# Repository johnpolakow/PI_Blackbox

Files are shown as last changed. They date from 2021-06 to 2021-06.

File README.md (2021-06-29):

# Raspberry Pi Based Data Acquistion System

# Directories in Repository    
## Docs/    
Contains various documentation info  created while building the software. Specification of commands to the client interface. Information on the ADC Loop, which is continuosly read out by the Raspberry Pi. Some notes on initial configuration of a Pi DAQ. Some how to files that may be useful while administrating the Pi DAQ.

## PCB/    
PI DAQ PCB Files    
Contains the files needed to FAB the Pi DAQ. All Gerber board files are present. The native Kicad project files are present as well, for maintenance and modification. There is rework required for the version of gerbers used here. The rework directions are in the **Docs/** folder. If time permits, will include a "fixed/corrected" version of the Kicad project files, eliminating the need for future rework. 

Cal Station Board Files
The PCB files for the Cal Station board are present as well, however I would not reccomend ordering this board. It was done extremely quickly and many mistakes were made. There was MUCH rework required to make the PCB functional. Almost all of the relay footprints are off. The relay part fits, but some of the pins are swapped. It was unpleasant to re-route all the signals with hookup wire, you would save yourself much time by starting over.    

All BOMS should be present as well.    

## Pi Firmware/
This folder contains the release versions of firmware that runs on the Pi DAQ. The different versions are kept for documentation and bug fixes. Also, the Configuration folder contains useful code to configure a Pi for the first time. It performs functions like:
  - Configuring hostname on the Pi
  - Configure user accounts
  - Getting / Setting Environment variables
  - Setting up alias commands for the pi user
  - setting default IP address and network configuration
  - Enabling SPI & I2C on the pi
  - Enabling SSH
  - Enable AutoLogin at boot for user pi
  - Getting the micro SD card usage stats

# Code Installation and Usage
## Source Code Download 
To download the code to the Pi, make sure you have an active internet connection on the Pi. This may involve editing the /etc/wpa_supplicant/wpa_supplicant.conf file on the Pi to add the credentials for the wifi network you want to connect to. The file will look like this:    
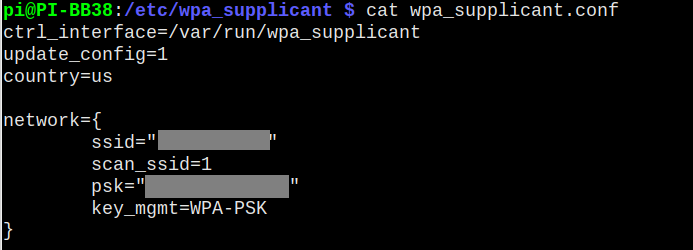
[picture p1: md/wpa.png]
plot
   
modify it by filling in the ssid of the network and the pre shared key (password) of the network.   

After conneting to Wifi/Internet, make a directory for the firmware:   
```mkdir /home/pi/firmware```   
```cd /home/pi/firmware```    
    
now clone the github repo:   
```git clone https://github.com/johnpolakow/PI_Blackbox.git```       

move everything to parent folder:         
```cd PI_Blackbox/```      
```mv -f ./* ../```     
```cd ..```
```rm -rf PI_Blackbox/```    

The PCB directory is not needed on the Pi:     
```rm -rf PCB/```     

move Docs folder to parent dir:    
```mv -f Docs/ ../```   

Change to Pi_Firmware directory and remove unnecesary releases, and move Configuration directory:      
```cd PI_Firmware/```     

Only the latest version is needed. You can remove the directories for older versions. For instance if you want to remove *Release0/* directory:    
```rm -rf Release0/```    

Move **Configuration/** directory to another location:    
```mv Configuration/ ../../```      

Last, the contents of the latest release may be moved to the firmware folder:    
```cd Release1```       
```mv -f ./* ../../```    
```cd ..```    
```rm -r Release1```    
```rm -r PI_Firmware/```     

You should now have two items in the **/home/pi/firmware/** folder:     
  - src/ folder, containing source code for compiling the DAQ executable    
  - makefile, to compile the source code    
![plot](./md/firmware3.png)    

## Compilation    
Compile the source code with the **make** command:    
![plot](./md/make_daq.png)   

the **DAQ** binary will be created. It can be executed directly with the command:     
```sudo ./DAQ```     

or, alternatively, the server process can be started with:     
```sudo systemctl restart Blackberry.service```    

check to see the process is running with the **top** command:   
```top```     
after executing the command a process display will popup. **DAQ** should be at the top:    
![plot](./md/top01.png)   
to exit out of the process display screen, hit the **q** button 

If DAQ process is not shown, then you need to either execute the DAQ process directly or start the Blackberry systemd service with:   
```sudo systemctl start Blackberry.service```

## SystemD Maintenance and Server Process Start     
 Some commands to administrate the Blackberry server process.
 see process status:        
```sudo systemctl status Blackberry.service```     

start the process:   
```sudo systemctl start Blackberry.service```    

stop the process:   
```sudo systemctl stop Blackberry.service```    

to start service at boot:    
```sudo systemctl enable [Blackberry.service]```    

view the server process file:   
```sudo systemctl cat Blackberry.service```

edit the service file:    
```sudo systemctl edit --full Blackberry.service```   

find out if the service is enabled:   
```sudo systemctl is-enabled Blackberry.service```

see log entries related only the the PI DAQ server process:   
```sudo journalctl UNIT=Blackberry.service```

```daemon-reload```

## Socket Connections    
The DAQ process opens tcp port 2020 and waits for a client to connect. To verify the port is open and listening, try these commands:    
```sudo ss -l -p | grep -vE '^(u_|nl )'```   
```sudo ss -lntu```    
```netstat -l -46```    
![plot](./md/netstat_l_46.png)   
![plot](./md/ss_lntu.png)   

## Querying the Server from a Client Machine
see client code repository. Also see 'Pi_Blackbox_Software_Behavioral_Specification' in the Docs/ directory:   
https://github.com/johnpolakow/PI_Blackbox/tree/master/Docs        
https://github.com/johnpolakow/PI_Blackbox/blob/master/Docs/Pi%20Blackbox%20Software%20Behavioral%20Specification_v2.pdf     
https://github.com/johnpolakow/Blackbox_Client    

## Lessons Learned
Things I would do differently if I was to do another version of this board:     
  - Do the layout in Cadence
  - Use switching regulator to drop input of +18-24V down to +13-14V. Eliminating the need for fan and heat sink
  - Low noise *switching* regulator for Pi voltage supply. The present switching converter IC required softening of the switching waveform to get the noise down.
  - Change 2N3055 BJT based programmable current source to FET based. 
  - smaller SMD crystals
  - Use SOM instead of full Pi Board
  - High speed ADCs for Voltage and Current measurement. More accurate power metric + phase information
  - More compact electrolytic caps
  - Only use ceramic caps near LT1054 voltage inverter. Tantalum cap ended up failing due to high ESR and switching current
  - smaller input capacitance, to lower the inrush current

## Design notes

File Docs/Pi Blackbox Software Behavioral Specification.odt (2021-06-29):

PI Blackbox

Software Specification

demo software commands

May 5, 2020

Table of Contents

Table 1 - Revision History

Version | Date | Author | Changes
Draft | Jan, 27, 2020 | John Polakowski | Based on group discussion of features and scope of interface. Initial goal to provide a rapid version of working code and conventions.

Table 2 – List of Acronyms

Acronym | Definition
DUT | Device Under Test
IDCA | Integrated Dewar Cooler Assembly
EMI | Electromagnetic Interference
PI_BB | PI Blackbox
LUT | Look Up Table

# Blackbox architecture

## Function

The Blackbox design goal is to datalog and control different metrics related to cooler testing. The Blackbox is to serve as an all-in-one piece of test equipment that can be used in many different use cases of cooler testing. These include: Lifetime Testing, Performance Testing, Burn-In Testing, …… The device under test (DUT) may be the complete IDCA, or one of its component parts (Compressor, Dewar, Displacer, CCC).

MUST EXECUTE PROGRAM WITH SUDO

## Peripherals

The peripherals of the PI_BB are:

Input Power

Power to CCC (banana plugs)

Dewar Connector (DB15)

3 thermocouples

PI USB

PI Ethernet

PI HDMI/DSI

Test Points

LEDs

## Metrics Captured

The IDCA metrics directly measured by the Pi Blackbox are:

- Power delivered to the Cooler Driver Board (Volts, mA, Watts)
- Dewar Temp Diode Voltage, and associated LUT temperature (Volts, Kelvins)
- Power delivered to heat load resistor in the Dewar (V, mA, mW)
- Heat Load State (On/Off)
- Relay State for Cooler Driver (On/Off)
- Temperature of x3 attached K-type thermocouples (Celsius)

## Capture Rate(s)

The target is to capture each metric once per second. The cooler power measurement accuracy improves considerably the more often we are able to sample it. It may become desirable at some point to reduce sampling frequency of the thermocouples, or temp diode, and increase the sampling frequency of the cooler power. For simplicity, at present all metrics are sampled equally.

The Pi firmware captures each metric sequentially, then writes the data points to file. Each datalog point of the above metrics is paired with:

- Timestamp ( MM/DD/YYYY hh:mm:ss )
- Elapsed Running Time when sample taken

# Software Specification

## Timestamp, Date-Time Naming Convention

A timestamp shall be represented in the format:

[MM-dd-YYYY]_[hh.mm.ss]

MM 2 digit month

dd 2 digit day of month

YYYY 4 digit year

hh 2 digit hour

mm 2 digit minute

ss 2 digit second

* 2 digit refers to the convention of including a leading zero if the value is less than ten.

** To avoid AM/PM confusion, the two digit hour shall be in the 24 hour based format. For example the hour 6:01:35 PM is represented as 18:01:35

Example:

Timestamp for Jan. 27th 2020 @ 3:18:34 PM is- 01/27/2020_15.18.34

## BlackBox Naming Convention

Each PI_BB has an associated ID. This is referred to in log files, Pi hostname, and IP address assignment. The ID scheme for a unit is as follows:

PI_BB[integer 10-240]

A valid ID would be: PI_BB20

This allocates a namespace of 230 potential blackboxes. The range of 10-240 makes sense in the IP Address space. The integer number will be the value used in the last address byte of the IP Address. The limitation to 240 follows with the largest value for an address byte: 255. The additional addresses (1-9, 241-254) are left for the hub computer, and any diagnostic PCs we might want to connect to. So for example if we have a unit named “PI_BB38”, on a network 192.168.123.0, the unit will have an IP Address of:

192.168.123.38

Additionally, the hostname for the pi will be:

pi@PI_BB38

If you open a terminal on this Pi, the resulting prompt will be:

This makes it easy to identify which Blackbox you are logged into if you SSH into the pi, or if you SCP a file to the PI.

**Possibility

If all units in a network are going to be used for a specific test, the ‘PI_BB’ could be changed to the name of the test. For instance:

pi@LifeTest20

pi@PerfTest20

pi@BurnIn20

Implementation Info

To change the hostname on a Pi two files need to be edited. These files must be edited using the ‘sudo’ command. To edit:

sudo vi /etc/hosts

sudo vi /etc/hostname

After editing and saving the above files, reboot to enable the new hostname.

Hub IP Address should always be .1

## Log File

### Log File Naming Convention:

The structure of the filename is:

BlackboxID_Date_Time.log

The specific syntax is:

PI_BB[blackbox#]_[MM-dd-YYYY]_[hh.mm.ss].log

The Date-Time timestamp is when the test begins.

All log files will end in ‘log’.

Optionally, the type of test being performed could be included in the filetype for easier file sorting in file store locations. For instance the following file extensions could be used when the type of test being performed is known:

.performance_log Performance test log file

.lifetime_log Lifetime Test Log files

.burnin_log Burn-In test Log Files

.log generic log file

Example: a log file for the performance test, which was captured using PI_BB21, and started the test on Feb. 2nd 2020 at 3:36:54 PM, would have the following log file:

PI_BB21_02-02-2020_15.36.54.performance_log

or alternatively:

PI_BB21_02-02-2020_15.36.54.log

### Log File Structure

// filename: XXXXXX

## PI_BB LOG FILE ##

firmware version XXXXX, PCB version

PI_BB: [blackbox#]

CCC: CCC_ID

Compressor: Compressor_ID

Dewar: Dewar_ID

Displacer: Displacer_ID

Test Execution: [Manual] or [profile filename]

Test_Type: [default/Performance/Lifetime/BurnIn]

Log Start: [Timestamp]

[COLUMN LEGEND]

_______________________________________________________________

START [TIMESTAMP]

DATA [TIMESTAMP]

COMMAND [TIMESTAMP]

DATA [TIMESTAMP]

STOP [TIMESTAMP]

________________________________________________________________

END

To avoid confusion and misinterpretation, the units of measure are included in both the Legend and immediately following the value of each metric.

### Log File Data Types and Format

The following are column entries in the log file. Each entry is defined as follows:

Value_ID [data type], decimal precision*, units, example entry

CCC_V floating point, 3, Volts, 12.432V

CCC_A floating point, 4, Amps, 0.4328A

CCC_W floating point, 3, Watts, 6.521W

Dewar_degK floating point, 2, Kelvins, 117.31K

Dewar_diodeV floating point, 3, Volts, 0.736V

Heat_Load_V floating point, 2, Volts, 8.42V

Heat_Load_mA floating point, 2, milliAmps, 28.31mA

Heat_Load_mW floating point, 2, milliWatts, 100.26mW

THRMCPL_degC floating point, 2, Celsius, 23.47C

Relay string, [ON/OFF], state, ON

Heat_Load string, [ON/OFF], state, OFF

*decimal precision here refers to the number of digits following the decimal point. For values less than 1, data shall have a leading 0.

For example: 0.236 = good,

.236 = not allowed

### Log File Creation and Refresh

A new log file is created, according to naming convention, at the start of test execution. A timestamp is including as part of the filename to prevent naming conflicts. The maximum length of time a log file records data is 24 hours. Whenever a new day begins ( at 00:00:00, or 12:00:00 AM), if an existing test is running, a new log file is created. The last line of the previous file instead of being “END” will be “CONTINUED” . The first line of the data section of the new file will be “PREVIOUS” instead of “START”. If the cooler is running, logging must occur.

Example:

[TODO]

### Log File Flags

START beginning of test execution. Either manually or via profile. Relay is closed (turned on). Metrics capture begins.

STOP Relay is opened (turned off). Cooler turns off. May be the end of the test or the test may continue with the cooler off. Datalogging continues.

END End of test. Datalogging halts. No data for this test is stored in a subsequent timestamped file.

CONTINUED Data for this test spans multiple files. It has data for this test stored in a subsequent timestamped file.

PREVIOUS Data for this test spans multiple files. It has data for this test stored in a previously timestamped file.

The above flags are not commands, but indicators of events.

Command Instructions which are issued either from a profile or via the socket interface are echoed to the log file.

### Log File Path

If a USB drive is inserted, the Linux kernel has been configured to mount it to:

/home/pi/USB_drive/

The flash drive is the default storage device if present. The Log file path is then:

/home/pi/USB_drive/Logs/filename.log

If a USB flash drive is not detected, the micro SD card will be used to store the data, and the path will be:

/home/pi/Logs/filename.log

DUT ID’s naming convention: TBD

- Compressor
- Dewar
- Displacer
- CCC

### Log File Upload

The Log File will be uploaded automatically when either:

- the test ends
- a new day begins, and a new file is created. Old file is uploaded

### Appending Parameters to Log File

In the future it may be desirable to annotate some derived metrics into the log file at the end of a test. These metrics might include:

- Cooldown Time
- Warmup Time
- Start Current, Stop Current
- Start Temp, Stop Temp
- Upper and Lower Bounds for power and temp, conditions when that datapoint ocurred.

## Config File

The config file stores and sets important system parameters for the PI_BB. It is not meant for regular user editing. Therefore it is a hidden file and requires elevated permissions to modify.

### Name

The config file is simply named “PI_BB.config”. Alternatively the individual blackbox number could be included, so “PI_BB38.config”. Only one config file should exist on each PI_BB.

### Config File Location

The config file is stored locally on the SD card in a hidden folder. In Linux hidden folders are named with a ‘.’ prefix. The config folder is named ‘.Config’ and is stored in the home directory.

For example:

~/.Config/PI_BB38.config

~/firmware/.config/PI_BB38.config

or

/home/pi/.Config/PI_BB38.config

/home/pi/firmware/.config/PI_BB38.config

### Config File Fields

// filename: PI_BB.config

hostname:

eth0_IP_address:

Network_address:

Subnet:

Hub_IP_address:

log file suffix (.log, .performance_log, etc)

HUB log store location

USB_flash_mount_folder:

PCB_revision_level:

Profile folder location(s)

environment variables

hostname

socket

HUB_IP_ADDR

cal file location

firmware version

## Profile File

### Profile File Structure

The file begins with a header describing the profile, the type of profile, and the profile name. After the file header is a separation line, then profile commands. For example:

// filename: XXXXX.profile

PI_BB_Profile_Definition_File

Profile_Type: [Lifetime | Performance | SADA | BurnIn | Custom]

Profile_Name: XXXXXX

Description: (description of profile)

________________________________________________________________

[COMMANDS] [TIMESTAMPS]

### Location

Profiles to be executed are stored locally on the SD card. The profiles are stored in a folder named ‘Profiles/’ and is located in the home directory.

For example:

~/Profiles/LifetimeTest.profile

or

/home/pi/Profiles/PerformanceTest.profile

### Profile Command List

START_LOG start data logging

RELAY_ON close relay to power CCC

RELAY_OFF open relay to power CCC

SET_LOAD change load setting. Setting is in mW, default is 0.0

LOAD_ON turn load on, adjust to setpoint

LOAD_OFF turn load off

STOP_TEST turn off load, turn off relay, stop logging

Each command must have an accompanying elapsed time timestamp, which indicates how much time elapses before executing the command. Every subsequent command must have a timestamp equal to or later than the previous command

Example File:

[ TODO ]

## System Startup

Once primary power is provided, the Pi begins to boot the kernel. A script is placed in the /etc/init.d/ folder which executes the following things:

- SPI and I2C enabled on the PI
- SSH enabled
- Read Config File
- Set IP Address
- Set Hostname
- Set Environment Variables
- Look for attached Flash Drive, if detected mount it
- Look for Hub to Connect to
- Sync to Network time if Available, else sync to DS3231
- Send SSH keys to hub
- Load Calibration files
- Enumerate any profiles in USB flash drive , copy to local SD card
- GPIOS are configured on the PI
- if network connected, do a package update

# parse kernel warnings

At end of test automatically upload file and unmount flash drive

log kernel errors to local non-volatile log file

# Socket Interface Specification

## Socket Instantiation

A specific port number mapping scheme needs to be decided on for the PIs and the Hub. [ TBD ]

## Socket Command Structure

All “commands” or instructions will originate from the hub computer. There are two types of instructions sent to a PI_BB:

- Get Instruction– will refer to as a ‘Query’
- Set Instruction – referred to as a ‘Command’

Query Instructions must begin with a ‘?’.

Command Instructions must begin with a ‘>’.

If an instruction is sent without the proper prefix of ‘?’ or ‘>’, or there is a typo in the instruction, the parser responds with a message:

Error: unable to parse instruction

to see command list type help

## Query List

?status Return the following parameters:

hostname

eth0 IP address

wlan0 address

flash drive disk usage

SD card disk usage

DUT ID for:

compressor

dewar

displacer

CCC

Pi CPU temperature

Test status (whether executing a test or not)

Execution set to manual or profile

Current time & date on PI

?profiles list the profiles currently stored on SD card

?logs list the logs currently stored on SD card

?profile list the current selected profile, if any

?show [filename] print the contents of the file. Could be a profile, log, config file, etc.

?metrics Returns a snapshot of the current measurements, if a test is running. If no test is running then a message is returned:

“No Test Currently Running”

?time Current date-time PI thinks it it right now

? If no argument is supplied with the query instruction, the list of query instructions is printed

help Prints query instructions and command instructions with usage info.

## Command List

>START_TEST Starts test execution, within the confines of selected test parameters. If a profile is selected, execution of the profile begins. If test execution is set to manual, then datalogging begins and the relay is turned on. A response is given affirming datalogging has begun, the response includes the name and path of the log file. Before executing the command, the system first asks the user to verify the test parameters. These include:

- Save Location
- Mode: manual or profile
- If profile is being run, lists the profile & run time

>RELAY_ON Turn on the relay. This command only valid if a test is currently executing AND test execution is set to manual.

>RELAY_OFF Turn off the relay. This command only valid if a test is currently executing AND test execution is set to manual.

>SET_LOAD [value] Set the load resistor setpoint. The load is not turned on with this command, just set to the value of the supplied argument. When the LOAD_ON command is issued, the load disipation will at the value supplied in this command. The units of [value] is milliWatts.This command only valid if a test is currently executing AND test execution is set to manual.

>LOAD_ON Set the load resistor current to the value prescribed by the SET_LOAD command. Default load current is 0 if the load has not been set yet. This command is only valid if a test is currently executing AND test execution is set to manual.

>LOAD_OFF Turn load resistor current off. This command is only valid if a test is currently executing AND test execution is set to manual.

>STOP_TEST Turn off cooler relay. Turn off load resistor current. Stop datalogging. Return total test execution time.

>SET_MANUAL_MODE Set test execution to manual.

>SET_PROFILE_MODE Set test execution to the current profile setting. If no profile has been selected, an error is given.

>LIST_PROFILES Display all profiles that can be found. Use ?profiles

>USE_PROFILE [profile] The file given as an argument is now selected as the profile to be executed. Verify the profile exists. The profile file is parsed to validate it is acceptable. Begin test execution by issuing START_TEST.

>SELFTEST Run the built-in self test operations and report back results.

>SET_TIME [MM-dd-YYYY]_[hh.mm.ss] Set Pi to argument timestamp.

>SEND_LOG upload log file(s) from the last test to the hub. This may span more than one file if the test lasted more than one day.

>SEND_ALL_LOGS upload all log files stored on the flash drive to the hub PC. If no flash drive is present, an error message is displayed regarding missing flash drive.

>SET_COMPRESSOR_ID

>SET_DISPLACER_ID

>SET_DEWAR_ID

>SET_CCC_ID

> If no argument is supplied with the Command instruction, the list of Commands is printed.

*Note: Once profile test execution begins with the START_TEST command, all commands except for STOP_TEST are ignored.

Example Command Workflow to Run a Profile Test:

>SELFTEST // verify PI_BB hardware is good

>USE_PROFILE [profile] // set the profile to a specific profile file

>SET_PROFILE_MODE // set execution to profile mode

?status // verify test parameters look ok

>START_TEST // run the profile

## Socket Permissions

All commands executed over the socket interface shall be executed with user account level permissions. Administrative actions require SSH login.

# PI OS Settings

## PI Relevant Folders

Logs: /home/pi/USB_drive/Logs/ [flash drive]

/home/pi/Logs/ [ SD Card]

Profiles: /home/pi/USB_drive/Profiles/ [flash drive]

/home/pi/Profiles/ [ SD Card]

Config: /home/pi/.Config/ [ SD Card]

Firmware: /home/pi/Firmware/ [ SD Card]

## SSH Keys

SSH is enabled for each PI_BB. SSH keys are generated for each Pi. At startup the PI sends the public keys to the hub for easy user level login and SCP file transfer.

## Calibration

The embedded hardware on the PI_BB PCB requires calibration to measure accurately.

[ TODO ]

## User Accounts

Two user accounts shall be created for use on the PI. One is a user level account, with permissions to do basic functions. The second account is an administrator account which can perform configuration edits, etc.

### Operator Access controlled functions

[ TODO ]

### Administrator Access Controlled functions

[ TODO ]

# Built in SELF Test function

A built in test function shall be available in the Command List. This function when exercised will perform a series of tests and report the result.

The list of information reported shall be

- CPU status
- RAM allocation for CPU and GPU
- GUI Video test
- PI_CPU temperature
- PI_USB interface up
- PI Ethernet Interface up
- Input Voltage in expected range
- Config file is filled out
- USB Flash drive detection
- Can ping Hub
- Can communicate with all onboard peripheral ICs
- Can operate relay
- temp diode and heat load resistor attached and working as expected
- Can talk to Hub over socket interface
- Real Time Clock has been set
- Synced to Network Time

PI_Blackbox Software Behavioral Document

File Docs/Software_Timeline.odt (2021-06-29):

Raspberry PI Blackbox

( Blackberry ?) Software

Timeline Estimates

Feb 13, 2020

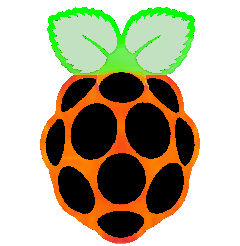
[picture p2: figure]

Table of Contents

# Completed Already

## System Startup / Configuration

Functionality Completed:

- Execute shell commands from C program
- List Files and Folders in a given directory
- Retrieve Environment Variables
- Set Hostname
- Get Hostname
- Add User
- Enable Autologin for user
- Set password for user / change password
- Backup files before modifying
- List Users
- Create Aliases File
- Verify boot file configured properly
- Configure boot file
  - enable ssh
  - enable I2C
  - enable SPI
  - enable SPI1
  - disable bluetooth
  - Set language to US
  - Set US keyboard layout

# Software TO COMPLETE

## System Startup / Configuration

Time Estimate: 7 days

Tasks

- setup network
- setup automatic mounting of flash drive to predictable location
- setup automated install of bcm2835 library, and other needed libraries
- parse PI_BB.config file
- Set Environment Variables
- Look for attached Flash Drive, if detected mount it
- Look for Hub to Connect to
- Sync to Network time if Available, else sync to DS3231
- Send SSH keys to hub
- Load Calibration files
- Enumerate any profiles in USB flash drive , copy to local SD card

## Board Assembly & Bring Up

Time Estimate: 7 days

Tasks

- add through hole components
- add Pis to boards
- bring boards up and verify everything works
  - verify relay working properly
  - verify both ADCs working
  - verify PS working
  - verify DS3231 working properly
  - verify programmable load and AC power measurement

## Execution Engine

Time Estimate: 10 days

Tasks

- Modify current monolithic datalogging code into modular executable components.
- Integrate socket / profile command inputs to execution engine

## Log File

Time Estimate: 3-4 days

Tasks

- Implement Naming Convention (use hostname)
- Parse device ID’s from config file, include in header
- Format Metrics properly
- Implement writing of start/stop flags
- Connect to execution engine to record commands (issued from socket or profile file) in the log
- Upload log file to hub after test completion
- Implement log file refresh every day at 12AM

## Profile File

Time Estimate: 3 days

Tasks

- parse profile, include error checking for: correct syntax, valid time specs, valid commands
- Create mechanism to pass commands to execution engine

## Calibration

Time Estimate: 10 days

Tasks

- get code working to connect to 5335B (power meter) over USB
- code to connect to HP 34401’s via RS232
- code to connect to HP power supply E3648A
- put together code to calibrate a board -
  - set voltage to various settings, read back with 34401
  - adjust pots on pcb
  - run through multiple cooldowns, at various load levels, logging from power meter
  - use logged values vs reported to create a LUT
  - Use external 200 Ohm resistor, run through various load currents, logging with 34401, use logged vs reported to create LUT
  - write code to group sampled values and create LUT
  - write LUT to Cal file

## GUI

Time Estimate: 4-7 days

Tasks

- integrate GUI w/ execution engine, linking the metrics reporting to dynamic updated fields in GUI
- polish GUI interface

## Code Release

Time Estimate: 4-7 days

Tasks

- put together network with Pis and a hub
- test & verify everything is functional when integrated together
- patch any bugs
- finish up any requisite documentation

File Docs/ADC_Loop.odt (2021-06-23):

///////////////////////////

HEAT_LOAD_ON

///////////////////////////

// DO NOT MODIFY THIS SEQUENCE

// THIS IS THE SEQUENCE FOR THE FUNCTION POINTER ARRAY FURTHER ABOVE IN THIS FILE.

// THERE IS A COMPLEX RELATIONSHIP BETWEEN SETTING THE MUX AND WHEN YOU CAN READ (TIME DELAY)

// WITH THIS SEQUENCE IT TAKES 937 milliseconds to complete a loop iteration

// THE FOLLOWING # OF SAMPLES ARE RECORDED:

// TEMP DIODE x 2 samples

// COOLER AMPS x 9 samples

// COOLER_VOLTS x 4 samples

// HEAT_LOAD_V x 4 samples

// HEAT_LOAD_I x 3 samples

// THRMCPL1 x 1 sample

// THRMCPL2 x 1 sample

// THRMCPL3 x 1 sample

ADC0_Read_Temp_Diode();

ADC1_Read_Cooler_Amps();

ADC0_Read_Temp_Diode();

ADC0_Set_MUX_Cooler_Volts();

ADC1_Read_Cooler_Amps();

ADC0_Throw_Away_Reading();

ADC1_Read_Cooler_Amps();

ADC1_Set_MUX_Heat_Load_V();

Read_Thermocouple_1();

ADC0_Read_Cooler_Volts();

ADC1_Throw_Away_Reading();

ADC0_Read_Cooler_Volts();

ADC1_Read_Heat_Load_V();

ADC0_Read_Cooler_Volts();

ADC1_Read_Heat_Load_V();

ADC0_Read_Cooler_Volts();

ADC0_Set_MUX_Cooler_Amps();

ADC1_Read_Heat_Load_V();

Read_Thermocouple_2();

ADC0_Throw_Away_Reading();

ADC1_Read_Heat_Load_V();

ADC1_Set_MUX_Heat_Load_I();

ADC0_Read_Cooler_Amps();

ADC1_Throw_Away_Reading();

ADC0_Read_Cooler_Amps();

ADC1_Read_Heat_Load_I();

ADC0_Read_Cooler_Amps();

ADC1_Read_Heat_Load_I();

ADC1_Set_MUX_Cooler_Amps();

ADC0_Read_Cooler_Amps();

ADC1_Throw_Away_Reading();

ADC0_Read_Cooler_Amps();

ADC0_Set_MUX_Temp_Diode();

Read_Thermocouple_3();

ADC0_Throw_Away_Reading();

ADC1_Read_Cooler_Amps();

//////////////////////////////////

HEAT LOAD OFF

///////////////////////////////////

// DO NOT MODIFY THIS SEQUENCE

// THERE IS COMPLEX RELATIONSHIP BETWEEN SETTING THE MUX AND WHEN YOU CAN READ FROM THE SETTING

// WITH THIS SEQUENCE IT TAKES 1004 milliseconds to complete a loop iteration

// THE FOLLOWING # OF SAMPLES ARE RECORDED:

// TEMP DIODE x 3 samples

// COOLER AMPS x 15 samples (ADC1 dedicated to reading cooler current)

// COOLER_VOLTS x 10 samples

// THRMCPL1 x 1 sample

// THRMCPL2 x 1 sample

// THRMCPL3 x 1 sample

ADC0_Read_Temp_Diode();

ADC1_Read_Cooler_Amps();

ADC0_Read_Temp_Diode();

ADC1_Read_Cooler_Amps();

ADC0_Read_Temp_Diode();

ADC0_Set_MUX_Cooler_Volts();

//printf("Converted %f V to %d counts\n", volts, corrected_counts);

ADC1_Read_Cooler_Amps();

Read_Thermocouple_1();

ADC0_Throw_Away_Reading();

ADC1_Read_Cooler_Amps();

ADC0_Read_Cooler_Volts();

ADC1_Read_Cooler_Amps();

ADC0_Read_Cooler_Volts();

ADC1_Read_Cooler_Amps();

ADC0_Read_Cooler_Volts();

ADC1_Read_Cooler_Amps();

ADC0_Read_Cooler_Volts();

ADC1_Read_Cooler_Amps();

ADC0_Read_Cooler_Volts();

ADC1_Read_Cooler_Amps();

Read_Thermocouple_2();

ADC0_Read_Cooler_Volts();

ADC1_Read_Cooler_Amps();

ADC0_Read_Cooler_Volts();

ADC1_Read_Cooler_Amps();

ADC0_Read_Cooler_Volts();

ADC1_Read_Cooler_Amps();

Read_Thermocouple_3();

ADC0_Read_Cooler_Volts();

ADC1_Read_Cooler_Amps();

ADC0_Read_Cooler_Volts();

ADC0_Set_MUX_Temp_Diode();

ADC1_Read_Cooler_Amps();

ADC0_Throw_Away_Reading();

ADC0:

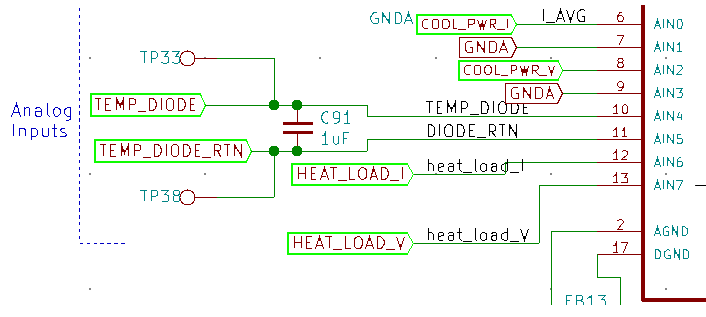
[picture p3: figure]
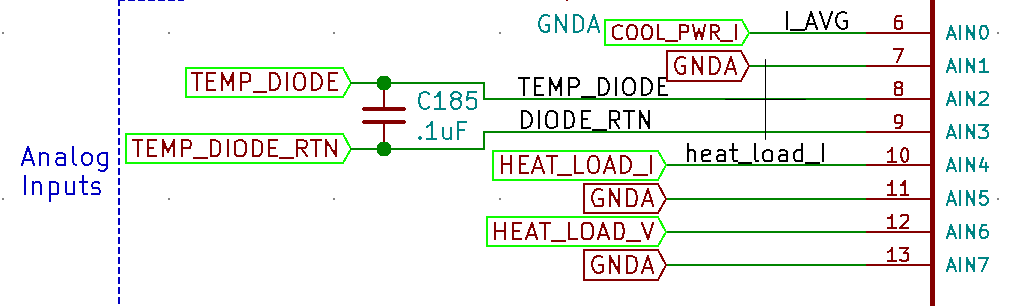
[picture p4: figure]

ADC1:

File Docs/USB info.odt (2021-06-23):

If drive is inserted, it will be listed in /media/pi/XXX

it can also be found with ls -laF /dev/disk/by-uuid

sudo umount /mnt/1GB_USB_flash

sudo mount -o uid=pi,gid=pi /dev/sda1 /mnt/1GB_USB_flash

where:

-o (lowercase letter "o", not the number zero) specifies that an option string follows

uid=pi,gid=pi specifies the user ID is user "pi" and the group ID is "pi" (note there are no spaces allowed between these terms)

/dev/sda1 is the first partition on the first USB drive

/mnt/1GB_USB_flash is the mount point directory

__________________________________________________________

$ sudo vi /etc/udev/rules.d/10-usbstick.rules

SUBSYSTEMS=="usb",KERNEL=="sd[a-h]1",SYMLINK+="usbkey", RUN+="/usr/lib/udev/usbkey " SUBSYSTEMS=="usb",KERNEL=="sd[a-h]1",ACTION=="remove", RUN+="/usr/lib/udev/usbkey"

3) created the /usr/lib/udev/ dir
4) created /usr/lib/udev/usbkey and Added

#!/bin/sh

ACTION=$(expr "$ACTION" : "\([a-zA-Z]\+\).*")

if [ "$ACTION" = "add" ]

then

mount /mnt/usb

else

umount /mnt/usb

fi

5) Gave it exec rights

Code: Select all (https://www.raspberrypi.org/forums/viewtopic.php?t=41056#)

sudo chmod 774 /usr/lib/udev/usbkey

6) Added the following in /etc/fstab

Code: Select all (https://www.raspberrypi.org/forums/viewtopic.php?t=41056#)

/dev/usbkey /mnt/usb vfat ro,noauto,user,exec 0 0

7) Create /mnt/usb dir

8) Reboot or restart udev service .

_______________________________________________________

sudo blkid - list disk devices

lsblk – list devices

ls -laF /dev/disk/by-uuid/

to reload fstab:

systemctl daemon-reload

use UUID in fstab:

UUID=18A9-9943 /media/usb vfat auto,nofail,noatime,users,rw,uid=pi,gid=pi 0 0

mount the device ( %mount /dev/sda1 )

unmount after writing

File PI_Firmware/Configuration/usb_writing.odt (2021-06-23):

We are writing a program for a Raspberry Pi 3B+ with Jesse I think and the 7 inch display. Pi has come a long way since I llooked at it several years ago. And it's true my Linux is a little historical in nature. The program is to display data from a battery controller that uses Tesla Model S batteries for solar energy storage.

It keeps a log file that can go back quite a bit in time and the 32GB SD card I'm using is more than generous. But the comma delimited file just begs an Xcel import and some further graphing and analysis. And we are putting the display and Pi in an enclosure that makes removing/installing the fragile SD card a less than optimal solution.

So basically, what I wanted to do was normally write to a log file on the SD card in our program directory. But if you insert a thumb drive into one of the USB ports, I wanted it to write it there instead. Later, if you removed the Thumb drive, I wanted to go back to the local directory.

I Googled this to death and instead of cunning techniques to do this, I found just entry after entry of snide and condescending snipes to the poor hapless yucks looking for this and bizarre workarounds that posed far too much work for far too little functionality. So by experimentation, I have kind of worked out a way to do this that isn't herculean. It's a little narrow in focus. But I thought I would take a moment and share it as it is kind of an obvious advantage of the 3B+ with the generous provision of four USB ports.

First, just mounting the thumb drive where you want it turned out to be a bit of a Texas Goat Rodeo to work out but quite simple in the end.

First I noted that if you just plugged in ONE thumb drive, no matter which port selected it always comes up as /dev/sda.. A stroke of luck. So to mount it , the first step is to make a directory where you want it to appear. Anywhere you have access to.

Code: Select all (https://www.raspberrypi.org/forums/viewtopic.php?t=222688#)

mkdir ~/programs/Powersafe/usbdrv

I thought this was a fabulous choice of course.

Step 2: append an entry to /etc/fstab using sudo nano /etc/fstab

Code: Select all (https://www.raspberrypi.org/forums/viewtopic.php?t=222688#)

/dev/sda /home/pi/programs/Powersafe/usbdrv auto uid=pi,gid=pi,umask=0022,sync,noauto,nosuid,rw,user 0 0

This basically mounts your drive when you insert it. It links the block /dev/sda to the directory /home/pi/programs/Powersafe/usbdrv.

auto actually refers to the file format. Some drives might be VFAT and others ext4 etc. the auto forces the kernel to try to identify it automatically which it does pretty well.

UID is user ID and GID is group ID and you want to set that to your user name, I still use the default pi account.
umask 0022 is again about permissions I think, I"m not actually sure.

synch simply sets it for synchronous communications.

noauto is quite important actually. It means don't automatically mount on boot. If you set this to auto, and you do NOT have a thumbdrive in a USB slot, it won't boot - it just hangs. Awkward.

nosuid block the operation of suid, and sgid bits.

rw indicates you can both read and write to the drive.

user means any user can mount and you need this for your desktop. Without this flag you might need sudo which isn't where I want to be in C.

The first 0 means the dump utility will ignore your thumbdrive and not try to back it up.
The final 0 is the pass value. File systems with a <pass> value 0 will not be checked by the fsck utility.

Once this is done, I've found the system surprisingly reliable. I can stick a thumb drive in and read it essentially immediately with a simple ls.
ANd when I remove it it disappears. It does usually pop up a FILE MANAGER window asking if I want to view it when I first insert the drive.

Programmatically, the difficulty is the usbdrv directory doesn't look much differently with a drive in our out. You can still read and write to the directory you made with no drive in at all. If you plug a drive in, you will see what is on it. And if you remove it, you'll see what was already there in the underlying directory. We ONLY want to write to that directory if it is linked to a thumb drive.

SO we have to detect whether a thumb drive is available. And that goes back to /dev/sda. So far, again no matter what drive stick I use or what port, it always comes up /dev/sda. So we'll use an ugly system call in our code to determine whether or not we have a thumb drive inserted.

Code: Select all (https://www.raspberrypi.org/forums/viewtopic.php?t=222688#)

void openLogFile()

{

//Check to see if we have a thumbdrive inserted by performing ls /dev/sda. If so we will open a logfile on the thumbdrive

//If not, we will open on the current directory.

char fileName[256]

int thumb = system("ls /dev/sda"); //Thumbdrive = 0 if thumbdrive detected or 512 if none available

//If it IS available, it is already mounted to our /usbdrv subdirectory by /etc/fstab

//FOR REFERENCE FSTAB /dev/sda /home/pi/programs/Powersafe/usbdrv auto uid=pi,gid=pi,umask=0022,sync,noauto,nosuid,rw,user 0 0

if(thumb==0)sprintf(fileName, "%s//usbdrv/PowerSafe100.log",programPath); //open a logfile on a USB Drive?

else sprintf(fileName, "%s//PowerSafe100.log", programPath); //else on our own directory

logfile=fopen(fileName,"a+");

}

The system call is

Code: Select all (https://www.raspberrypi.org/forums/viewtopic.php?t=222688#)

system("ls /dev/sda");

of course. It will return a result of 0 in int thumb if it can list /dev/sda and a value of 512 if it fails.

So we have two statements to form a fileName depending on whether or not thumb =0.

Code: Select all (https://www.raspberrypi.org/forums/viewtopic.php?t=222688#)

programPath

is simply a path link to /home/pi/programs/Powersafe where we run our program. So with a thumb drive, we go to the usbdrv directory below it, and if not, we stay in the main program directory. The file is PowerSafe100.log either way.

Once we have the file open for appending, we can refer to it elsewhere in the program using the global pointer logfile.

Anyway, thats how you can rather automatically mount it. That's how you can detect it. And that's how you can access it from C or C++.

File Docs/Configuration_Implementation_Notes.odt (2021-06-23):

PI Configuration Implementation Details

## Add_User(char* NEW_USERNAME)

Creates a new user login on the pi, and creates home directory for the new user. First the existing list of users is queried, so we don’t add a user if it already exists. If the new username doesnt already exists, it is created by executing the shell command:

sudo useradd [USERNAME]

Then the user account is added to all the groups on the PI, so the new user account can access all of the PI’s hardware resources. Shell command to add groups to the new user account:

sudo usermod %s -a -G sudo,pi,adm,dialout,cdrom,audio,video,plugdev, users,input,netdev,spi,i2c,gpio

## Create_Aliases_File()

Aliases are essentially keywords that represent other commands. They are used to make it simpler to execute otherwise complex or long commands. For instance if you wanted to create an easy way to change the IP Address on the command line, you create an “alias” that represents the longer form of the command.

Example long command:

sudo ifconfig eth0 192.168.250.118 // change IP Address

An alias can be created to represent this command. Pick a keyword to represent the above command, say, “setip”.

Example alias for long command:

alias setip=“sudo ifconfig eth0 192.168.250.188”

Now entering the command ‘setip’ performs the same function as if you entered the long form of changing eth0 address. Some custom alias commands have been added to make using the pi easier to navigate.

The aliases file where these are defined is location:

/home/pi/.bash_aliases or /home/[user]/.bash_aliases

Note the file begins with a ‘.’ This file executes when user ‘pi’ logs on. For a different username, the .bash_aliases file needs to be placed in location /home/[user]/.bash_aliases. If you edit this file manually, you wont see the results of changes until reboot. To effect the changes immediately you can enter the command:

source /home/pi/.bash_aliases

This file is created by this function. The aliases added are:

ls lists directory contents, but groups directories together and adds color coding

la lists all contents. Same as executing ls -la. Also groups directories and color codes the output.

dmesg returns kernel log information, but presents in human readable format. Timestamps are given as dates and timestamps instead of seconds since epoch

update updates cache of package repository

upgrade updates packages to their latest versiona

ps lists processes currently running, and shows the output in a tree format.

df lists disk space usage stats

temp reports CPU temperature of the PI.

Custom functions/commands:

the “temp” command is a custom addition. It reports the cpu temperature of the raspberry pi. It queries the temp by executing:

/opt/vc/bin/vcgencmd measure_temp

The output temperature is then parsed, and wrapped with text “CPU temp:”, and the temperature component is changed to red in color.

The “cd” command has been modified. The new functionality is defined in the ~/.bashrc file. The standard cd command changes directories. The new cd command changes directories, then lists the contents in the new directory location. Often when changing directories the next command you issue is an “ls” command, to list the contents. The new cd function integrates these two steps together and makes navigating the directory tree much easier. The addition to .bashrc is:

function cd

{

builtin cd "$@" && ls

}

source /home/pi/.bash_aliases

## char** Exec_Shell_Command(char* command);

Any command you might normally execute on the command line, you can execute by sending to this function. For instance to list the contents of a file on the command line you might issue:

cat somefile.txt

The same functionality can be executed from the C program using Exec_Shell_Command() function. A short code snippet to do the same thing:

char console_command[] = “cat somefile.txt”;

char** console_command_output;

console_command_output = Exec_Shell_Command( console_command );

Print_String_Array( console_command_output );

Free_String_Memory( console_command_output );

Notes about usage:

Exec_Shell_Command() returns a list of strings, hence the char** return type. Each string is a line of the output from the command. The list of strings is stored in dynamically allocated memory. As a result, we have to handle the “garbage collection”, or letting the OS know when we are done using the memory location. The c function to handle this is free(). Free cannot handle the entire string list though, it can only free one string at a time. It is necessary to loop through and individually free each string. To handle this a helper function was written: Free_String_Memory(), which handles the return of all the dynamic memory allocated. To print any response, Print_String_Array() prints all strings listed in the response of the shell command.

Notes about implementation:

The string representation of the command is passed as an argument to Exec_Shell_Command(). To execute the string, popen() is called. Popen() gives you access to either the read stream, or write stream from the process, but not both. To read the command response, we need the read stream, so the POPEN_READ flag is passed as an argument to popen. popen returns a file handle to the IO stream of the executed command. We can read from the file handle using fgets(). The output is read, one line at a time, and the output is copied to a dynamic string array. New memory locations for strings are allocated only as needed, one line at a time. The end of the string list is indicated by assigning NULL to the end of the list. The pointer to the string list is then returned. It is the callers responsibility to free the memory locations after use.

## Enable_Autologin_For_User(char* USERNAME)

This function enables “Autologin” for a user. In practice this means when you boot the pi, you dont have to enter a username and password before getting access to the console or desktop. To enable autologin, two files are edited:

/etc/lightdm/lightdm.conf // for desktop GUI

/etc/systemd/system/autologin@.service // for console

First these two files are examined to see if autologin has already been configured. The line for each file we are looking for is shown below:

file: /etc/lightdm/lightdm.conf

line in file: autologin-user=pi

file: /etc/systemd/system/autologin@.service

line in file: ExecStart=-/sbin/agetty –autologin pi –noclear %I $TERM

The entry “pi” will be changed to the username passed as an argument to Enable_Autologin_For_User(). To do the text find and replacement in the files, the linux stream editor sed is used. sed is a command line stream editor, which uses regular expressions to find and replace text. If the new username is FLIR, the sed commands are:

sudo sed -i -e '/autologin-user/s/=[a-zA-Z0-9]*/=FLIR/' /etc/lightdm/lightdm.conf

sudo sed -i -e 's/ExecStart=-\/sbin\/agetty --autologin[][a-zA-Z0-9]*[]/ExecStart=-\/sbin\/agetty --autologin FLIR /' /etc/systemd/system/autologin@.service

**Note: the above three lines are a single line in the file.

The meat of the second sed command is as follows:

s/ExecStart=-\/sbin\/agetty –autologin[][a-zA-Z0-9]*[]/ExecStart= ….--autologin FLIR /

s/ perform substitution. The syntax is s/ [find pattern ]/ [replacement text ]

Examining the first pattern match portion:

ExecStart=-\/sbin\/agetty –autologin[][a-zA-Z0-9]*[]/

Breaking the above line into segments for description:

ExecStart=-\/sbin\/agetty –autologin[ ][a-zA-Z0-9]*[ ]/

In english it means:

1. find text beginning with pattern ExecStart=-\/sbin\/agetty –autologin

2. after the above text, look for a single character enclosed in the first set of brackets [ ], which is a space

3. next look for alpha-numeric characters. Lowercase a to z, uppercase A to Z, or 0 to 9. There may be one or more of these characters, indicated by the ‘*’. This is the portion containing the username.

4. look for a single character enclosed in the second set of brackets [ ], which is a space

5. ‘/’marks the end of the pattern

The above pattern matches all text beginning with Exec…, all the way until the end of pi, and a space after pi. The entire line (highlighted in blue) will be replaced by the replacement text (highlighted in green).

*note the ‘\’ characters pre-pended before any string ‘/’ characters. The forward slash is a command flag indicator to sed, so it must be escaped with a backslash.

** If you look at the c code you’ll see any ‘\’ characters pre-pended with an additional ‘\’ character. This is due to C interpreting our escape sequence for sed as an escape sequence within a string. In effect, to enter the ‘/’ character as a string character ( and not a command flag), it must be pre-pended with ‘\\’.

The replacement text:

ExecStart=-\/sbin\/agetty --autologin FLIR /

## void Free_String_Array_Memory(char** string_array)

This function frees dynamically allocated memory stored in string lists, the list is passed as an argument to this function. To free the memory, the list is looped through until encountering a NULL value, identifying the last dynamical memory allocation location. After that, the pointer to the list is freed.

## char* Get_Environment_Variable_Value(char* env_variable)

There are two variable types that can be accessed: system Environment Variables, which are available system wide, and user Shell Variables, which are user specific shell variables. This function first queries the system environment variables, and if not found, the user shell variables are queried. If a match is found, the value of the variable is printed. To query the system environment variables, the c function:

getenv( env_variable )

which returns a string of the value of the environment variable. If getenv() doesnt find the environment variable, the we try to querying the shell for the value:

echo [ environment variable ]

The echo command is executed via a call to Exec_Shell_Command().

## void Get_Disk_Usage()

Gets disk space usage stats for the micro SD card, and any attached USB flash drives.

Stats are collected using the "df" shell command . "df" returns more stats than

just the USB flash and micro SD card, it also returns info from many locations in the root filesystem, so response needs to be trimmed. To filter, the output from df is piped to grep,

which only returns lines that contain “/dev/root” (microSD),

or “/dev/sd” (USB flash). Any USB drives have a kernel device location of /dev/sdX, where X is a letter a-z. To search for all USB drives, we just search on the path “/dev/sd”.

The full shell command is:

df -Tha --total | grep -E "/dev/root|/dev/sd"

Flags for df:

-T print filesystem type

-h print human readable output

--total produce grand totals

Flags for grep

-E use regular expressions in search pattern

Example output:

/dev/sda1 vfat 970M 297M 664M 32% /home/pi//USB_DRIVE

## void Set_Network_Configuration(char* eth0_IP);

Raspbian by default uses a DHCP Daemon (Dynamic Host Control Protocol) to configure the network interfaces. This is a client daemon that accepts IP addresses from a DHCP server. Typically the PI would connect to a router which hosts a DHCP server, and the server would assign the PI an IP address. For our use we want to set a static IP Address on eth0, and leave the wireless interface (wlan0) able to be configured by dhcp. To do this requires editing the dhcpcd.conf file.

*NOTE in previous versions of Raspbian networking was configured via the /etc/network/interfaces file. This no longer is the case. It is imperative to leave the interfaces file alone.

To check if the DHCP daemon is running enter:

sudo service dhcpcd status

If the service is not started, start and enable the service with:

sudo service dhcpcd start

sudo systemctl enable dhcpcd

For manual IP address assignment, the file /etc/dhcpcd.conf needs to be edited.

Edit the file, un-commenting the section titled “Example Static IP Configuration”. Delete the ‘#’ at the beginning of the line to uncomment. The section should now look like this:

interface eth0

static ip_address=192.168.123.11/24

static routers=192.168.123.1

static domain_name_servers=192.168.123.1

The static IP is set on the line:

static ip_address=192.168.123.11/24

The suffix ‘/24’ describes the subnet mask as 255.255.255.0. (Use first 24 bits of subnet mask. Each “255” corresponds with 8 bits.)

The fields static_routers and static_domain_name_servers should be set to the hub IP, or router if it is present.

To give the PI the new configuration:

sudo reboot

The eth0 interface will not actually be set to the static address specified. until there is an Ethernet cable connected between the PI and another network card, so the PI can sense an active connection. Then the interface is configured.

Wifi Configuration

Wifi parameters are set in the file /etc/wpa_supplicant/wpa_supplicant.conf. Only a few lines need to be added, which pertain to any wifi networks you want to join. Also it is important to set the country code in this file. The file should look like:

country=us

update_config=1

ctrl_interface=/var/run/wpa_supplicant

network={

scan_ssid=1

ssid="FLIR-Guest"

psk="6thSense+4BEs"

key_mgmt=WPA-PSK

}

## Get Environment Variables

This function queries the kernel for the values of some kernel environment variables. These specific variables are used in setting up the Pi. The environment variables retrieved are:

$USER

$HOME

$HOSTNAME

Note- these variables change depending on what user is running the command. For instance if user “pi” is logged in but you ask for the environment variables using “sudo”, the environment variables will return values for the user root.

## Get_Environment_Variable_Value

A string of the environment variable name is passed to this function. It then queries the kernel for the variable using the “getenv()” system call. If getenv() cannot find the environment variable name, next the shell is queried. The variable may be a shell variable instead of a system environment variable. The shell is queried via the command:

echo $variable

The command is executed via the EXEC_SHELL() function. The response from the shell is read using the fgets() function.

## Verify_SSH_Enabled

To enable SSH and other hardware settings, typically the rapi-config GUI is used. Though not documented, raspi-config also exposes a command line interface. The command line interface consists of a “get” and “set” option for each parameter. To query for SSH status the command is:

sudo raspi-config nonint get_ssh

The response is:

0 = SSH enabled

1 = SSH disabled.

The raspi-config command is executed in the shell via popen(), and the shell response is read via the fgets() command. The response is parsed to an integer with the strtol() function. (string to long)

Verify_SSH_Enabled() inverts this logic ( 1= enabled) and returns the value

## Set_SSH_Enabled

This also functions via command line interface to raspi-config. To enable SSH the command is:

sudo raspi-config nonint do_ssh 0 // 0 enables, 1 disables

## Verify_Boot_File_Config

The boot file is located here: /boot/config.txt . Don’t manually edit this file unless you are knowledgeable about what you’re doing. Most of the device enables are in this file. The gpio pins on the PI can be configured for different functions, it is done in this file. Each line configures a different setting. To verify the PI is setup how we want, this function searches the file for the configuration lines we want. Each option we desire is searched for.

## List_Users()

To list all users on a linux OS use the command:

getent passwd

getent is the shell command for “get entries”, and is used for mining databases, more than just the password file. Here we are asking for all entries in the password file. There are many users, here is the full output of the command:

root:x:0:0:root:/root:/bin/bash

daemon:x:1:1:daemon:/usr/sbin:/usr/sbin/nologin

bin:x:2:2:bin:/bin:/usr/sbin/nologin

sys:x:3:3:sys:/dev:/usr/sbin/nologin

sync:x:4:65534:sync:/bin:/bin/sync

games:x:5:60:games:/usr/games:/usr/sbin/nologin

man:x:6:12:man:/var/cache/man:/usr/sbin/nologin

lp:x:7:7:lp:/var/spool/lpd:/usr/sbin/nologin

mail:x:8:8:mail:/var/mail:/usr/sbin/nologin

news:x:9:9:news:/var/spool/news:/usr/sbin/nologin

uucp:x:10:10:uucp:/var/spool/uucp:/usr/sbin/nologin

proxy:x:13:13:proxy:/bin:/usr/sbin/nologin

www-data:x:33:33:www-data:/var/www:/usr/sbin/nologin

backup:x:34:34:backup:/var/backups:/usr/sbin/nologin

list:x:38:38:Mailing List Manager:/var/list:/usr/sbin/nologin

irc:x:39:39:ircd:/var/run/ircd:/usr/sbin/nologin

gnats:x:41:41:Gnats Bug-Reporting System (admin):/var/lib/gnats:/usr/sbin/nologin

nobody:x:65534:65534:nobody:/nonexistent:/usr/sbin/nologin

systemd-timesync:x:100:102:systemd Time Synchronization,,,:/run/systemd:/usr/sbin/nologin

systemd-network:x:101:103:systemd Network Management,,,:/run/systemd:/usr/sbin/nologin

systemd-resolve:x:102:104:systemd Resolver,,,:/run/systemd:/usr/sbin/nologin

_apt:x:103:65534::/nonexistent:/usr/sbin/nologin

pi:x:1000:1000:,,,:/home/pi:/bin/bash

messagebus:x:104:110::/nonexistent:/usr/sbin/nologin

_rpc:x:105:65534::/run/rpcbind:/usr/sbin/nologin

statd:x:106:65534::/var/lib/nfs:/usr/sbin/nologin

sshd:x:107:65534::/run/sshd:/usr/sbin/nologin

avahi:x:108:113:Avahi mDNS daemon,,,:/var/run/avahi-daemon:/usr/sbin/nologin

lightdm:x:109:114:Light Display Manager:/var/lib/lightdm:/bin/false

systemd-coredump:x:996:996:systemd Core Dumper:/:/usr/sbin/nologin

There are many extraneous users we aren’t interested in. To get only the “regular” users, we need to filter this list.

There are two fields we care about for each line entry:

pi:x:1000:1000:,,,:/home/pi:/bin/bash

The first highlighted field is the username, the second field is the User ID, or UID.

In the file /etc/login.defs there are parameters that dictate the range of numbers assigned to “regular” user UIDs:

UID_MIN

UID_MAX

The first step in filtering the large list of users is to read the min and max UID parameters. This done by searching the /etc/login.defs file for these two parameters. This done with the command:

grep -E '^UID_MIN|^UID_MAX' /etc/login.defs

The command is executed in the shell via Exec_Shell_Command. The return from the shell command is two strings of the form:

UID_MIN 1000

UID_MAX 60000

These two strings are then then parsed to the integer values: 1000 & 60000. These integer values are the filters for parsing the output from the command getent passwd. To parse the long form of the user list, the helper function parseUsers() is invoked.

void Enable_Sudo_No_Password_For_User(char* USERNAME)

char* Shell_List_Files(char* path)

void Set_Wallpaper(char* wallpaper_filepath)

char** Install_Software_Packages(char* software_list_filepath)

Hostname:

Implementation Info

To change the hostname on a Pi two files need to be edited. These files must be edited using the ‘sudo’ command. To edit:

sudo vi /etc/hosts

sudo vi /etc/hostname

After editing and saving the above files, reboot to enable the new hostname.

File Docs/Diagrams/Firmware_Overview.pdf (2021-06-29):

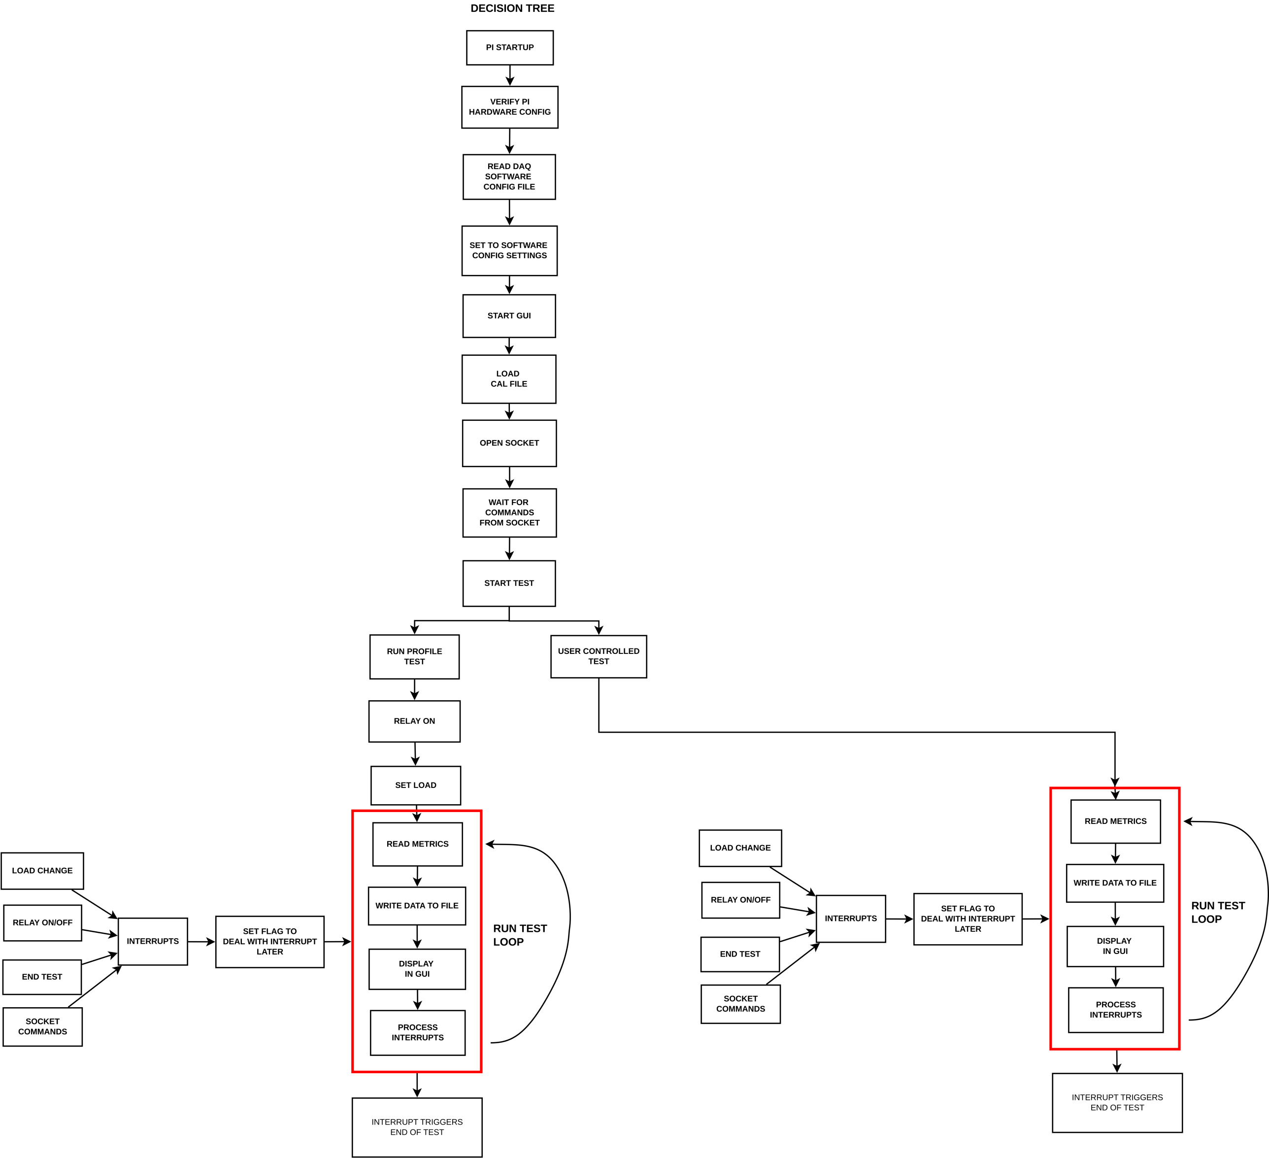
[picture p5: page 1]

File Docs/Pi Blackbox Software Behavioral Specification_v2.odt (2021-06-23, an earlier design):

PI Firmware

Commands/Queries

demo software commands

May 5, 2020

Table of Contents

# PI FIRMWARE

## Source Repository, Compiling, and Executable

The source code has all been written in C, for speed of execution and compatibility with the GPIO library used on the pi (bcm2835). The github repo where the source code can be accessed is:

https://github.com/johnpolakow/PI_Blackbox

The directory for code executing on the pi is “PI_Firmware”. To get a sample client application, which already works with the pi firmware, look in the “Client_Code” folder.

For compiling the firmware on the pi, here is the command (make sure bcm2835 library has been installed if this is a fresh OS):

gcc -g -o exec Execution_Engine.c -l pthread -l bcm2835 -l m

If debugging capabilities are desired use this command:

gcc -g -fsanitize=address -static-libasan -o exec Execution_Engine.c -l pthread -l bcm2835 -l m

The client code is easy to compile:

gcc -o client client.c

IF EXECUTING MANUALLY, MUST EXECUTE PROGRAM WITH SUDO

Note: the binary executable for the program must be executed on the raspberry pi with the “sudo” command. The pi requires programs which access the GPIO pins to have elevated access. If sudo is not used there will be a segmentation fault.

sudo ./exec

Note2: By default the pi has been configured to automatically start execution of the program at boot, MANUAL EXECUTION IS NOT NECESSARY. Under normal circumstances it is not necessary to execute the program manually. If you desire to for testing or debug purposes, make sure to preface the command with sudo.

## Metrics Captured

The metrics directly measured by the Pi Blackbox are:

- Power delivered to the Cooler Driver Board (Volts, mA, Watts)
- Dewar Temp Diode Voltage, and associated LUT temperature (Volts, Kelvins)
- Power delivered to heat load resistor in the Dewar (V, mA, mW)
- Heat Load State (On/Off)
- Relay State for Cooler Driver (On/Off)
- Temperature of x3 attached K-type thermocouples (Celsius)

## Capture Rate(s)

Each metric once per second. Every second a complete iteration of the various metrics are read and saved to storage. The pi can be queried over the socket interface as often as necessary to retrieve the metrics. If querying more than once per second, examine the timestamp in the metrics readout to ascertain whether a duplicate read has been sent. The pi responds with whatever the latest data is.

The Pi firmware captures each metric sequentially, then writes the data points to file. Each datalog point of the above metrics is paired with:

- Timestamp ( MM/DD/YYYY hh:mm:ss )
- Elapsed Running Time when sample taken

# Software Specification

## Timestamp, Date-Time Naming Convention

A timestamp shall be represented in the format:

[MM-dd-YYYY]_[hh.mm.ss]

MM 2 digit month

dd 2 digit day of month

YYYY 4 digit year

hh 2 digit hour

mm 2 digit minute

ss 2 digit second

* 2 digit refers to the convention of including a leading zero if the value is less than ten.

** To avoid AM/PM confusion, the two digit hour shall be in the 24 hour based format. For example the hour 6:01:35 PM is represented as 18:01:35

Example:

Timestamp for Jan. 27th 2020 @ 3:18:34 PM is- 01/27/2020_15.18.34

## Log File

### Log File Structure

// filename: XXXXXX

## PI_BB LOG FILE ##

firmware version XXXXX, PCB version

PI_BB: [blackbox#]

CCC: CCC_ID

Compressor: Compressor_ID

Dewar: Dewar_ID

Displacer: Displacer_ID

Test Execution: [Manual] or [profile filename]

Test_Type: [default/Performance/Lifetime/BurnIn]

Log Start: [Timestamp]

[COLUMN LEGEND]

_______________________________________________________________

DATA [TIMESTAMP]

COMMAND [TIMESTAMP]

DATA [TIMESTAMP]

STOP [TIMESTAMP]

________________________________________________________________

To avoid confusion and misinterpretation, the units of measure are included in both the Legend and immediately following the value of each metric. For instance a voltage is recorded as:

12.013V

### Log File Path

If a USB drive is inserted, the Linux kernel has been configured to mount it to:

/home/pi/USB_drive/

The flash drive is the default storage device if present. The Log file path is then:

/home/pi/USB_drive/Logs/filename.log

If a USB flash drive is not detected, the micro SD card will be used to store the data, and the path will be:

/home/pi/Logs/filename.log

The log file is automatically created and stored when the “>start_test” command is issued.

Note: When configuring the software to auto-launch at boot, it broke the save to USB functionality, so all Logs are being stored on the pi at:

/home/pi/Logs/filename.log

USB save functionality will be restored in the next software release.

### Log File Upload

Currently the log file upload to hub is not implemented. The logs can be accessed manually however.

# Socket Interface Specification

## Socket Instantiation

The socket hosted on the pi opens and listens on port 2020, waiting for any client to connect. The client can connect to the pi over Ethernet or Wifi, it is interface agnostic. The Pi listens on port 2020 for any incoming connection. The pi waits for clients to connect to it, the pi does not initiate any connections. The socket is configured as TCP/IP protocol, with the following socket parameters:

.ai_family = AF_INET;

.ai_socktype = SOCK_STREAM;

.ai_flags = AI_PASSIVE;

A sample client program has been written and is included to illustrate how to use the interface. The pi will always send a response to any client instruction.

## Socket Command Structure

All “commands” or instructions will originate from the hub computer. There are two types of instructions sent to a PI_BB:

- Get Instruction– will refer to as a ‘Query’
- Set Instruction – referred to as a ‘Command’

Query Instructions must begin with a ‘?’.

Command Instructions must begin with a ‘>’.

If an instruction is sent without the proper prefix of ‘?’ or ‘>’, or there is a typo in the instruction, the parser responds with an error message.

The commands/queries are not case sensitive, even though the commands are shown as all capital letters in this document.

## Query List

Not all queries are implemented yet. The non functional queries are greyed out.

?status Return the following parameters:

hostname

eth0 IP address

wlan0 address

flash drive disk usage

SD card disk usage

DUT ID for:

compressor

DDCA

displacer

CCC

Pi CPU temperature

Test status (whether executing a test or not)

Execution set to manual or profile

Current time & date on PI

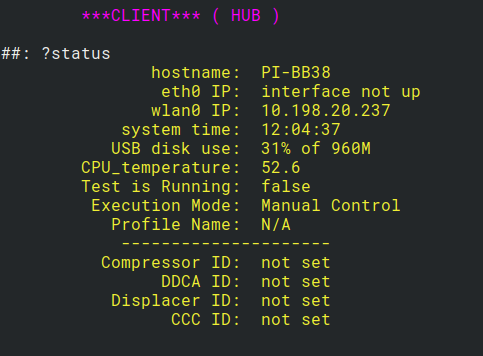
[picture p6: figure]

?profiles list the profiles currently stored on SD card

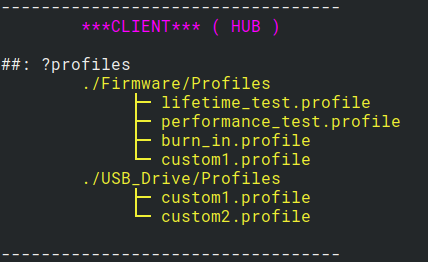
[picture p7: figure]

?logs list the logs currently stored on SD card

?profile list the current selected profile, if any

?show [filename] print the contents of the file. Could be a profile, log, config file, etc.

?metrics Returns a snapshot of the current measurements.

?time Current date-time PI thinks it it right now

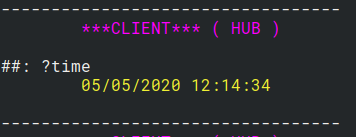
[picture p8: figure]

? If no argument is supplied with the query instruction, the list of query instructions is printed

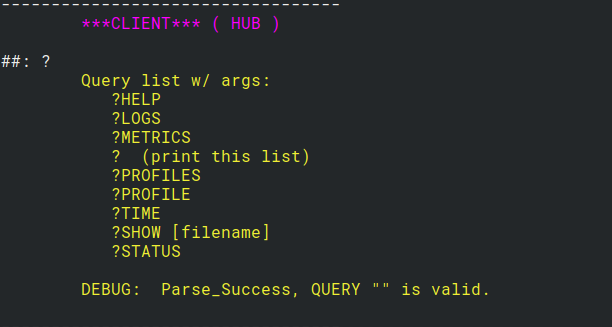
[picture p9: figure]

help Prints query instructions and command instructions with usage info. Note this command does not require a ‘?’ or ‘>’.

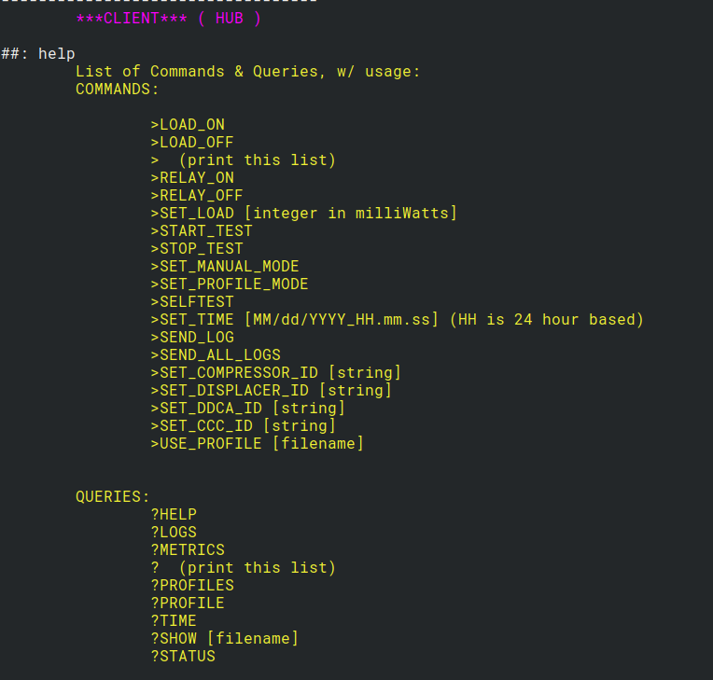
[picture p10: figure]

## Command List

DEBUG [ON/OFF] Turn additional debug information on or off. This may help when writing software to interface with the pi. Note the “>” character is not used to prepend the command with.

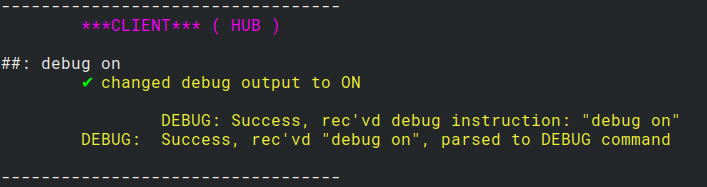
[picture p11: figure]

VERBOSE [ON/OFF] Turn verbose responses on or off. Verbose responses include the column headers for the metrics command. Note the “>” character is not used to prepend the command with.

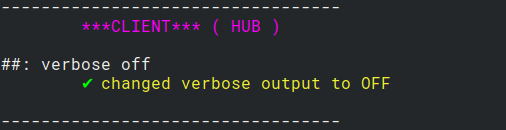
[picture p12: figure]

>START_TEST Starts test execution, within the confines of selected test parameters. At present, because profile functionality is not complete yet, the >start_test command only causes the log file to begin recording.

>RELAY_ON Turn on the relay.

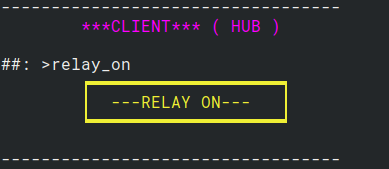
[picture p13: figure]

>RELAY_OFF Turn off the relay.

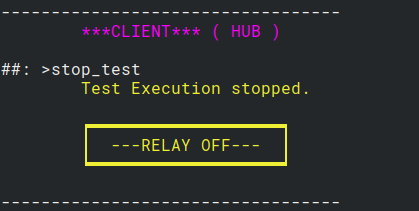
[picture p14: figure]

>SET_LOAD [value] Set the load resistor power dissipation in milliWatts. The load is not turned on with this command, just set to the value of the supplied argument. When the LOAD_ON command is issued, then power will be applied at the load dissipation value supplied in this command.

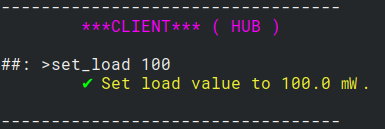
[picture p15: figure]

>LOAD_ON Set the load resistor current to the value prescribed by the SET_LOAD command. Default load current is 0 if the load has not been set yet.

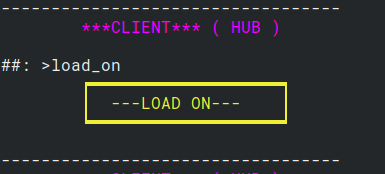
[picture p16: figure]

>LOAD_OFF Turn load resistor current off. This command is only valid if a test is currently executing AND test execution is set to manual.

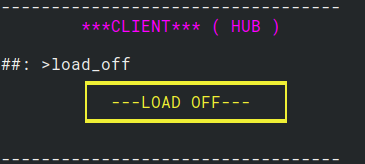
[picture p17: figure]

>STOP_TEST Turn off cooler relay. Turn off load resistor current. Stop data-logging.

>SET_MANUAL_MODE Set test execution to manual. Default value is manual mode.

>SET_PROFILE_MODE Set test execution to the current profile setting. This command works, however running a profile is not implemented yet.

>USE_PROFILE [profile] The file given as an argument is now selected as the profile to be executed. Verify the profile exists. The profile file is parsed to validate it is acceptable. Begin test execution by issuing START_TEST.

>SELFTEST Run the built-in self test operations and report back results. Not implemented yet.

>SET_TIME [MM-dd-YYYY]_[hh.mm.ss] Set Pi to argument timestamp.

>SEND_LOG upload log file(s) from the last test to the hub. This may span more than one file if the test lasted more than one day. Not implemented yet.

>SEND_ALL_LOGS upload all log files stored on the flash drive to the hub PC. If no flash drive is present, an error message is displayed regarding missing flash drive. Not implemented.

>SET_COMPRESSOR_ID

>SET_DISPLACER_ID

>SET_DEWAR_ID

>SET_CCC_ID

> If no argument is supplied with the Command instruction, the list of all Commands is printed.

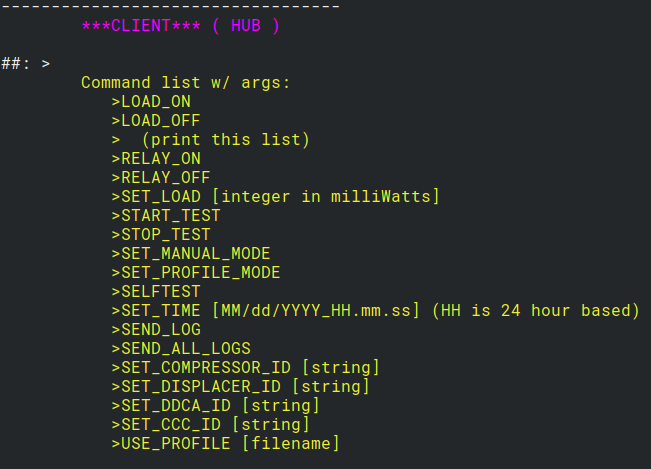
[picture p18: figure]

## Client Connection

When a client connects, the following welcome message is sent by the pi:

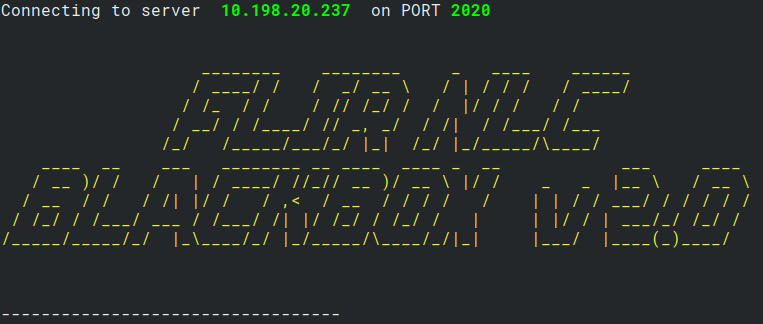
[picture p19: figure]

# Blackbox software & systemD

To configure the firmware to launch at boot, it was turned into a service launched by the systemd kernel subsystem. A file called “Blackberry.service” is located at:

/lib/systemd/system/Blackberry.service

Systemd auto-launches the executable at boot, and if the executable fails or quits for some reason, systemd will continuously attempt to relaunch the executable. This is good and verifies as long as the pi is on, we can connect to it.

One downside of the auto-launch feature is the executable doesn't launch in a terminal instance, so you can’t monitor commands and events as they happen on the pi. If you want to monitor the output on the pi you can stop the service, and launch the standalone executable. Here’s how to do it:

To stop the service:

sudo systemctl stop Blackberry.service

To restart the service:

sudo systemctl start Blackberry.service

To see the status:

sudo systemctl status Blackberry.service

To disable the service from auto-launching at boot:

sudo systemctl disable Blackberry.service

To enable the service from auto-launching at boot:

sudo systemctl enable Blackberry.service

sudo systemctl restart Blackberry.service

If for some reason the service is not working, you can view the error reporting in the following locations:

dmesg

journalctl -shows exec output for debugging

/var/log/boot.log

/var/log/daemon.log

/var/log/messages

/var/log/syslog

/var/log/user.log

PI_Blackbox Software Behavioral Document

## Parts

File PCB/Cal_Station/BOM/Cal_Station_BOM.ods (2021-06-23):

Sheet: Cal_Station_BOM
Component Count: | 259
Ref | Value | Footprint
C1 | 10uF | 0805
C2 | 10uF | 0805
C3 | 10uF | 0805
C4 | 10uF | 0805
C5 | 10uF | 0805
C6 | 10uF | 0805
C7 | 10uF | 0805
C8 | 10uF | 0805 |  |  |  | blue banana | https://www.digikey.com/product-detail/en/pomona-electronics/5931-6/501-1925-ND/737492
C9 | 10uF | 0805 |  |  |  | yellow | https://www.digikey.com/product-detail/en/pomona-electronics/5931-4/501-1924-ND/737490
C10 | 10uF | 0805 |  |  |  | white | https://www.digikey.com/product-detail/en/pomona-electronics/5931-9/501-1926-ND/737493
C11 | 10uF | 0805 |  |  |  | blk&red | https://www.digikey.com/product-detail/en/pomona-electronics/5931-02/501-2347-ND/737488
C12 | 10uF | 0805 |  |  |  | green | https://www.digikey.com/product-detail/en/pomona-electronics/5931-5/501-1921-ND/737491
C13 | 10uF | 0805 |  |  |  | blk | https://www.digikey.com/product-detail/en/pomona-electronics/5931-0/501-1805-ND/737487
C14 | 10uF | 0805 |  |  |  | red | https://www.digikey.com/product-detail/en/pomona-electronics/5931-2/501-1879-ND/737489
C15 | 10uF | 0805 |  |  |  | brown | https://www.digikey.com/product-detail/en/pomona-electronics/72930-1/501-1227-ND/1196361
C16 | 10uF | 0805
C17 | 10uF | 0805
C18 | 10uF | 0805
C19 | 10uF | 0805
C20 | 10uF | 0805
C21 | 10uF | 0805
C22 | 10uF | 0805
C23 | 10uF | 0805
C24 | 10uF | 0805
C25 | 10uF | 0805
C26 | 10uF | 0805
C27 | 10uF | 0805
C28 | 10uF | 0805
C29 | 10uF | 0805
C30 | 10uF | 0805
C31 | 10uF | 0805
C32 | 10uF | 0805
C33 | 10uF | 0805
C34 | 1uF | 0603
C35 | 1000uF | Capacitor_THT:CP_Radial_D12.5mm_P5.00mm
C36 | 10uF | 1206
C37 | 10uF | 1206
C38 | 10uF | 1206
C39 | 10uF | 1206
C40 | 10uF | 1206
C41 | 10uF | 1206
C42 | .1uF | 0603
C43 | .1uF | 0603
C44 | 10uF | 1206
C45 | 10uF | 1206
C46 | 10uF | 0805
C47 | 4.7uF | Capacitor_Tantalum_SMD:CP_EIA-3528-21_Kemet-B_Pad1.50x2.35mm_HandSolder
C48 | 560uF | Capacitor_THT:CP_Radial_D10.0mm_P5.00mm
C49 | 560uF | Capacitor_THT:CP_Radial_D10.0mm_P5.00mm
C50 | 10uF | 1206
C51 | 10uF | 1206
C52 | 10uF | 1206
C53 | 10uF | 1206
C54 | 10uF | 0805
C55 | .1uF | 0603
C56 | 10uF | 0805
C57 | 10uF | 0805
C58 | 4.7uF | Capacitor_Tantalum_SMD:CP_EIA-3528-21_Kemet-B_Pad1.50x2.35mm_HandSolder
C59 | 10uF | 0805
C60 | 1uF | 0805
C61 | 10uF | 0805
C62 | 4.7uF | Capacitor_Tantalum_SMD:CP_EIA-3528-21_Kemet-B_Pad1.50x2.35mm_HandSolder
C63 | 10uF | 0805
C64 | .1uF | 0603
C65 | 4.7uF | Capacitor_Tantalum_SMD:CP_EIA-3528-21_Kemet-B_Pad1.50x2.35mm_HandSolder
C66 | 10uF | 0805
D1 | 1N4148W | SOD123 | 1N4148W | Kicad Files:SOD123 | 100V 300mA |  | 1N4148W-FDICT-ND | 0.16
D2 | 1N4148W | SOD123
D3 | 1N4148W | SOD123
D4 | 1N4148W | SOD123
D5 | 1N4148W | SOD123
D6 | 1N4148W | SOD123
D7 | 1N4148W | SOD123
D8 | 1N4148W | SOD123
D9 | 1N4148W | SOD123
D10 | 1N4148W | SOD123
D11 | 1N4148W | SOD123
D12 | 1N4148W | SOD123
D13 | 1N4148W | SOD123
D14 | 1N4148W | SOD123
D15 | 1N4148W | SOD123
D16 | 1N4148W | SOD123
D17 | 1N4148W | SOD123
D18 | 1N4148W | SOD123
D19 | 1N4148W | SOD123
D20 | 1N4148W | SOD123
D21 | 1N4148W | SOD123
D22 | 1N4148W | SOD123
D23 | 1N4148W | SOD123
D24 | 1N4148W | SOD123
D25 | 1N4148W | SOD123
D26 | 1N4148W | SOD123
D27 | 1N4148W | SOD123
D28 | 1N4148W | SOD123
D29 | 1N4148W | SOD123
D30 | 1N4148W | SOD123
D31 | LED GRN | LED_SMD:LED_0805_2012Metric_Pad1.15x1.40mm_HandSolder
D32 | LED GRN | LED_SMD:LED_0805_2012Metric_Pad1.15x1.40mm_HandSolder
D33 | 1N4148W | SOD123 | 1N4148W | Kicad Files:SOD123 | 100V 300mA |  | 1N4148W-FDICT-ND | 0.16
D34 | 1N4148W | SOD123
D35 | 1N4148W | SOD123
D36 | 1N4148W | SOD123
FB2 | Ferrite_Bead_Small | Inductor_SMD:L_0805_2012Metric_Pad1.15x1.40mm_HandSolder |  | R_0805 | 600R @100Mhz |  | 445-2206-1-ND | 0.11 | Enclosure | 13x7 | Aluminum no bottom | 377-1018-ND | 19.1
K1 | 2A Relay | Footprints:Panasonic_TX2 |  |  |  | TX2-LT-5V-TH-ND | 5.02
K2 | 2A Relay | Footprints:Panasonic_TX2 |  |  |  | TX2-LT-5V-TH-ND | 5.02
K3 | 2A Relay | Footprints:Panasonic_TX2 |  |  |  | TX2-LT-5V-TH-ND | 5.02
K4 | 2A Relay | Footprints:Panasonic_TX2 |  |  |  | TX2-LT-5V-TH-ND | 5.02
K5 | 2A Relay | Footprints:Panasonic_TX2 |  |  |  | TX2-LT-5V-TH-ND | 5.02
K6 | 2A Relay | Footprints:Panasonic_TX2 |  |  |  | TX2-LT-5V-TH-ND | 5.02
K7 | 2A Relay | Footprints:Panasonic_TX2 |  |  |  | TX2-LT-5V-TH-ND | 5.02
K8 | TXS2 | Footprints:Panasonic_TX2 |  | DPDT | relay 10mA | 255-4236-5-ND | 5.78
K9 | TXS2 | Footprints:Panasonic_TX2 |  | DPDT | relay 10mA | 256-4236-5-ND | 5.78
K10 | TXS2 | Footprints:Panasonic_TX2 |  | DPDT | relay 10mA | 257-4236-5-ND | 5.78
K11 | TXS2 | Footprints:Panasonic_TX2 |  | DPDT | relay 10mA | 258-4236-5-ND | 5.78
K12 | TXS2 | Footprints:Panasonic_TX2 |  | DPDT | relay 10mA | 259-4236-5-ND | 5.78
K13 | TXS2 | Footprints:Panasonic_TX2 |  | DPDT | relay 10mA | 260-4236-5-ND | 5.78
K14 | TXS2 | Footprints:Panasonic_TX2 |  | DPDT | relay 10mA | 261-4236-5-ND | 5.78
K15 | TXS2 | Footprints:Panasonic_TX2 |  | DPDT | relay 10mA | 262-4236-5-ND | 5.78
K16 | TXS2 | Footprints:Panasonic_TX2 |  | DPDT | relay 10mA | 263-4236-5-ND | 5.78
K17 | TXS2 | Footprints:Panasonic_TX2 |  | DPDT | relay 10mA | 264-4236-5-ND | 5.78
PI1 | RPI_3B+_Header | Connector_PinHeader_2.54mm:PinHeader_2x20_P2.54mm_Vertical
Q1 | MMBT2222A | SOT23 | MMBT2222A-FDICT-ND |  |  |  | 0.13
Q2 | MMBT2222A | SOT23 | MMBT2222A-FDICT-ND |  |  |  | 0.13
Q3 | MMBT2222A | SOT23 | MMBT2222A-FDICT-ND |  |  |  | 0.13
Q4 | MMBT2222A | SOT23 | MMBT2222A-FDICT-ND |  |  |  | 0.13
Q5 | MMBT2222A | SOT23 | MMBT2222A-FDICT-ND |  |  |  | 0.13
Q6 | MMBT2222A | SOT23 | MMBT2222A-FDICT-ND |  |  |  | 0.13
Q7 | MMBT2222A | SOT23 | MMBT2222A-FDICT-ND |  |  |  | 0.13
Q8 | MMBT2222A | SOT23 | MMBT2222A-FDICT-ND |  |  |  | 0.13
Q9 | MMBT2222A | SOT23 | MMBT2222A-FDICT-ND |  |  |  | 0.13
Q10 | MMBT2222A | SOT23 | MMBT2222A-FDICT-ND |  |  |  | 0.13
Q11 | MMBT2222A | SOT23 | MMBT2222A-FDICT-ND |  |  |  | 0.13
Q12 | MMBT2222A | SOT23 | MMBT2222A-FDICT-ND |  |  |  | 0.13
Q13 | MMBT2222A | SOT23 | MMBT2222A-FDICT-ND |  |  |  | 0.13
Q14 | MMBT2222A | SOT23 | MMBT2222A-FDICT-ND |  |  |  | 0.13
Q15 | MMBT2222A | SOT23 | MMBT2222A-FDICT-ND |  |  |  | 0.13
Q16 | MMBT2222A | SOT23 | MMBT2222A-FDICT-ND |  |  |  | 0.13
Q17 | MMBT2222A | SOT23 | MMBT2222A-FDICT-ND |  |  |  | 0.13
Q18 | MMBT2222A | SOT23 | MMBT2222A-FDICT-ND |  |  |  | 0.13
Q19 | MMBT2222A | SOT23 | MMBT2222A-FDICT-ND |  |  |  | 0.13
Q20 | MMBT2222A | SOT23 | MMBT2222A-FDICT-ND |  |  |  | 0.13
Q21 | MMBT2222A | SOT23 | MMBT2222A-FDICT-ND |  |  |  | 0.13
Q22 | MMBT2222A | SOT23 | MMBT2222A-FDICT-ND |  |  |  | 0.13
Q23 | MMBT2222A | SOT23 | MMBT2222A-FDICT-ND |  |  |  | 0.13
Q24 | MMBT2222A | SOT23 | MMBT2222A-FDICT-ND |  |  |  | 0.13
Q25 | MMBT2222A | SOT23 | MMBT2222A-FDICT-ND |  |  |  | 0.13
Q26 | MMBT2222A | SOT23 | MMBT2222A-FDICT-ND |  |  |  | 0.13
Q27 | MMBT2222A | SOT23 | MMBT2222A-FDICT-ND |  |  |  | 0.13
Q28 | MMBT2222A | SOT23 | MMBT2222A-FDICT-ND |  |  |  | 0.13
Q29 | MMBT2222A | SOT23 | MMBT2222A-FDICT-ND |  |  |  | 0.13
Q30 | MMBT2222A | SOT23 | MMBT2222A-FDICT-ND |  |  |  | 0.13
Q31 | MMBT2222A | SOT23 | MMBT2222A-FDICT-ND |  |  |  | 0.13
Q32 | MMBT2222A | SOT23 | MMBT2222A-FDICT-ND |  |  |  | 0.13
Q33 | MMBT2222A | SOT23 | MMBT2222A-FDICT-ND |  |  |  | 0.13
Q34 | MMBT2222A | SOT23 | MMBT2222A-FDICT-ND |  |  |  | 0.13
Q35 | MMBT2222A | SOT23 | MMBT2222A-FDICT-ND |  |  |  | 0.13
Q36 | MMBT2222A | SOT23 | MMBT2222A-FDICT-ND |  |  |  | 0.13
R1 | 40R | 50W | 20ppm/C | chassis mount |  | 696-1472-ND | 4.01
R2 | 30R | 50W | 20ppm/C | chassis mount |  | RHRD-30-ND | 5.1
R3 | 24R | 50W | 50ppm/C | chassis mount |  | A131874-ND | 4.97
R4 | 20R | 50W | 30ppm/C | chassis mount |  | KAL50FB20R0-ND | 3.64
R5 | 120R | 25W | 30ppm/C | chassis mount |  | A102415-ND | 3.06
R6 | 60R | 50W | 50ppm/C | chassis mount |  | A132067-ND | 3.96
R7 | 300R | 0402
R8 | 300R | 0402
R9 | 300R | 0402
R10 | 300R | 0402
R11 | 300R | 0402
R12 | 300R | 0402
R13 | 300R | 0402
R14 | 300R | 0402
R15 | 300R | 0402
R16 | 300R | 0402
R17 | 300R | 0402
R18 | 300R | 0402
R19 | 100R | 0402
R20 | 100R | 0402
R21 | 100R | 0402
R22 | 300R | 0402
R23 | 300R | 0402
R24 | 300R | 0402
R25 | 300R | 0402
R26 | 300R | 0402
R27 | 300R | 0402
R28 | 300R | 0402
R29 | 300R | 0402
R30 | 300R | 0402
R31 | 300R | 0402
R32 | 300R | 0402
R33 | 300R | 0402
R34 | 300R | 0402
R35 | 300R | 0402
R36 | 300R | 0402
R37 | 300R | 0402
R38 | 300R | 0402
R39 | 300R | 0402
R40 | 1k | 0402
R41 | 300R | 0402
R42 | 1K | 0402
R43 | 1K | 0402
R44 | 20k | 0603
R45 | 2.2k | 0603
R46 | 20k | 0603
R47 | 2.2k | 0603
R48 | 500R | 0402
R49 | 500R | 0402
R50 | 300R | 0402
R51 | 50R | 0402
R52 | 100R | 0402
R53 | 50R | 0402
R54 | 50R | 0402
R55 | 100R | 0402
R56 | 50R | 0402
R57 | 1k | 0402
R58 | 50R | 0402
U1 | TPS7A7002
U2 | TPS7A7002
U3 | LTC6655 | Footprints:LTC6655_LS8
U4 | LTC2057 | Package_SO:SO-8_3.9x4.9mm_P1.27mm
U5 | LTC6655 | Footprints:LTC6655_LS8

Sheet: Sheet2
10uF | 53

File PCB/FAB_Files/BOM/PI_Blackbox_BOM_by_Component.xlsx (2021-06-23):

Description | Manufacturer | Digikey PN | MFR PN | Price EA | QTY | Reference Designators Populated Into
50V Ceramic .1uF X7R 0603 | Samsung | 1276-1000-1-ND |  | 0.1 | 57 | C3 | C5 | C9 | C10 | C11 | C12 | C14 | C19 | C21 | C22 | C38 | C41 | C52 | C53 | C54 | C56 | C57 | C59 | C61 | C64 | C68 | C72 | C77 | C78 | C83 | C85 | C90 | C99 | C102 | C105 | C106 | C115 | C117 | C120 | C157 | C158 | C160 | C166 | C168 | C171 | C172 | C173 | C183 | C186 | C188 | C190 | C191 | C194 | C195 | C196
CAP CER 1UF 25V X7R 0805 | Kemet | 399-8004-1-ND |  | 0.15 | 33 | C6 | C7 | C15 | C18 | C20 | C49 | C50 | C51 | C55 | C58 | C66 | C69 | C73 | C81 | C88 | C89 | C103 | C104 | C112 | C113 | C114 | C118 | C119 | C121 | C128 | C141 | C143 | C149 | C174 | C175 | C176 | C178 | C179
CAP TANT 47UF 10% 35V 2917 T495X | Kemet | 399-3905-1-ND | T495X476K035ATE300 | 2.41 | 12 | C8 | C71 | C87 | C95 | C126 | C131 | C136 | C140 | C148 | C151 | C152 | C156
1uF Film 16VDC | Cornell Dubilier | 338-2778-1-ND | FCA1210C105M-G2 | 0.94 | 9 | C13 | C91 | C96 | C97 | C159 | C163 | C164 | C167 | C170
CAP CER 1000PF 16V X7R 0402 | Kemet | 399-1032-1-ND | C0402C102K5RACTU | 0.1 | 3 | C16 | C35 | C177
CAP TANT 4.7UF 10% 35V 1411 | Kemet | 399-10431-1-ND | T491B475K035AT | 0.95 | 7 | C17 | C62 | C67 | C70 | C116 | C180 | C181
CAP CER 1UF 25V X7R 0603 | Kemet | 399-7376-1-ND | C0603C105K3RACTU | 0.3 | 8 | C23 | C98 | C161 | C182 | C184 | C187 | C189 | C208
20pF, 50V, C0G | Murata | 490-1410-1-ND | GRM1885C1H200JA01D | 0.1 | 4 | C24 | C25 | C192 | C193
CAP CER 10UF 50V X7R 1206 | Samsung | 1276-6767-1-ND | CL31B106KBHNNNE | 0.4 | 30 | C29 | C34 | C36 | C74 | C75 | C76 | C84 | C92 | C93 | C100 | C101 | C107 | C109 | C123 | C124 | C125 | C127 | C130 | C132 | C134 | C135 | C138 | C142 | C144 | C145 | C146 | C153 | C154 | C212 | C214
CAP CER 10UF 16V X7R 0805 | Samsung | 1276-6472-1-ND | CL21B106KOQNNNG | 0.3 | 8 | C37 | C111 | C122 | C165 | C209 | C210 | C211 | C213
CAP FILM 1UF 10% 63VDC RADIAL | Kemet | 399-11451-1-ND | MMK5105K63J04L16.5TR18 | 0.95 | 1 | C30
CAP POLY 6000UF 35V T/H | United Chemi Con | 565-4353-ND | ELBK350ELL602AMN3S | 3.93 | 2 | C31 | C32
0603 .01UF 10% 50V X7R | Kemet | 399-C0603C103K5RAC7081CT-ND | C0603C103K5RAC7081 | 0.11 | 4 | C33 | C60 | C63 | C65
CAP FILM 3.3UF 20% 50VDC RAD | WIMA | 1928-1627-ND | MKS2B043301H00MSSD | 1.15 | 3 | C39 | C108 | C169
CAP ALUM 1000UF 20% 35V RADIAL | Panasonic | P15382CT-ND | EEU-FR1V102B | 1.03 | 3 | C94 | C110 | C147
CAP CER 10000PF 50V X7R 0402 | Kemet | 399-7760-1-ND | C0402C103M5RACTU | 0.1 | 6 | C40 | C42 | C43 | C45 | C46 | C48
CAP CER 0.47UF 10V X7R 0402 | Taiyo Tuden | 587-5912-1-ND | LMK105B7474KV-F | 0.25 | 2 | C129 | C133
CAP CER 100UF 16V X5R 1210 | Kemet | 399-11270-1-ND | C1210C107M4PAC7800 | 3.23 | 2 | C139 | C150
CAP CER 0.1UF 25V X7R 0402 | Murata | 490-13341-1-ND | GRM155R71E104ME14D | 0.1 | 6 | C44 | C47 | C162 | C198 | C199 | C200
DIODE SCHOTTKY 40V 1A SOD123 | Diodes Incorporated | 1N5819HW-FDICT-ND | 1N5819HW-7-F | 0.44 | 2 | D1 | D3
TVS DIODE 18V 29.2V DO214AB | Littelfuse | SMDJ18CACT-ND | SMDJ18CA | 1.17 | 1 | D2
DIODE GEN PURP 100V 300MA SOD123 | Diodes Incorporated | 1N4148W-FDICT-ND | 1N4148W-7-F | 0.16 | 2 | D4 | D12
LED GREEN CLEAR SMD | Litte-On | 160-1426-1-ND | LTST-C171KGKT | 0.29 | 6 | D5 | D8 | D10 | D11 | D13 | D16
LED YELLOW CLEAR SMD | Litte-On | 160-1416-1-ND | LTST-C170KSKT | 0.33 | 2 | D6 | D9
LED ORANGE CLEAR SMD | Lite-On | 160-1419-1-ND | LTST-C171AKT | 0.31 | 1 | D14
LED RED CLEAR SMD | Lite-On | 160-1427-1-ND | LTST-C171KRKT | 0.29 | 1 | D17
HEATSINK 18X50MM 2-CLIP TO-220 | Wakefield-Vette | 345-1491-ND | OMNI-220-18-50-2C | 7.43 | 1 | HS1
CAP CER 0.1UF 50V Z5U 1206 | Kemet | 399-1258-1-ND | C1206C104Z5UACTU | 0.19 | 2 | C26 | C155
CAP CER 0.1UF 25V X7R 0805 | Kemet | 399-8000-1-ND | C0805C104M3RACTU | 0.1 | 2 | C79 | C185
FIXED IND 10UH 850MA 300 MOHM | Wurth | 732-4516-1-ND | 74479887310A | 1.2 | 5 | L1 | L2 | L7 | L9 | L13
TRANS NPN 40V 0.6A SOT23 | Micro Commercial | MMBT2222ATPMSCT-ND | MMBT2222A-TP | 0.1 | 3 | Q1 | Q4 | Q7
FIXED IND 10UH 500MA 300 MOHM | TDK | 445-6762-1-ND | MLZ2012N100LT000 | 0.14 | 2 | L16 | L17
PC TEST POINT, WHITE, SMT | Keystone | 36-5192CT-ND | 5192TR | 0.44 | 9 | TP3 | TP5 | TP6 | TP7 | TP8 | TP9 | TP10 | TP12 | TP50
PC TEST POINT, BLACK, SMT | Keystone | 36-5191CT-ND | 5191TR | 0.44 | 5 | TP11 | TP32 | TP38 | TP40 | TP43
PC TEST POINT, PURPLE, SMT | Keystone | 36-5199CT-ND | 5199TR | 0.44 | 3 | TP4 | TP14 | TP15
PC TEST POINT, YELLOW, SMT | Keystone | 36-5194CT-ND | 5194TR | 0.44 | 7 | TP17 | TP18 | TP22 | TP31 | TP45 | TP46 | TP47
PC TEST POINT, RED, SMT | Keystone | 36-5190CT-ND | 5190TR | 0.44 | 7 | TP16 | TP19 | TP27 | TP28 | TP29 | TP35 | TP44
PC TEST POINT, BLUE, SMT | Keystone | 36-5197CT-ND | 5197TR | 0.44 | 3 | TP13 | TP23 | TP24
PC TEST POINT, GREEN, SMT | Keystone | 36-5196CT-ND | 5196TR | 0.44 | 2 | TP26 | TP48
PC TEST POINT, ORANGE, SMT | Keystone | 36-5193CT-ND | 5193TR | 0.44 | 1 | TP33
CAP CER 10000PF 50V X7R 1206 | Yageo | 311-1174-1-ND | CC1206KRX7R9BB103 | 0.24 | 1 | C27
CAP ALUM 560UF 20% 35V RADIAL | Nichicon | 493-15313-ND |  | 0.74 | 2 | C28 | C137
FIXED IND 10UH 500MA | TDK | 445-6762-1-ND | MLZ2012N100LT000 | 0.14 | 19 | FB1 | FB3 | FB4 | FB5 | FB6 | FB7 | FB8 | FB9 | FB12 | FB15 | FB16 | FB17 | FB18 | FB19 | FB20 | FB24 | FB25 | FB28 | FB30
FIXED IND 22UH 230MA | Taiyo Yuden | 587-1721-1-ND | CBMF1608T220K | 0.27 | 9 | FB2 | FB11 | FB21 | FB22 | FB23 | FB26 | FB27 | FB29 | FB31
FERRITE BEAD 1 KOHM 1210 1LN | Taiyo Yuden | 587-1753-1-ND | FBMH3225HM102NT | 0.44 | 4 | FB10 | FB13 | FB14 | FB32
FIXED IND 2.2UH 30MA | TDK | 445-15690-1-ND | MLF1005G2R2KT000 | 0.28 | 3 | FB33 | FB34 | FB35
CAP CER 12PF 50V C0G/NP0 0603 | Kemet | 399-1050-1-ND | C0603C120J5GACTU | 0.1 | 1 | C80
CAP CER 3000PF 50V C0G/NP0 0603 | Murata | 490-6384-1-ND | GRM1885C1H302JA01D | 0.19 | 1 | C82
CAP CER 680PF 250V C0G/NP0 0603 | Kemet | 399-14994-1-ND | C0603C681JAGAC7867 | 0.11 | 1 | C86
DIODE SCHOTTKY 40V 3A SMA | ON Semiconductor | MBRA340T3GOSCT-ND | MBRA340T3G | 0.48 | 1 | D7
PTC .15A |  | 507-1755-1-ND |  | 0.14 | 1 | F1
PTC RESET FUSE 24V 2A 2920 | Bel Fuse | 507-1749-1-ND | 0ZCF0200AF2C | 0.29 | 2 | F2 | F3
CONN HEADER SMD R/A 2POS 3MM | TE Connectivity | A33212CT-ND |  | 0.99 | 1 | J3
FILTER LC 1UF SMD | Murata | 490-5052-1-ND | BNX022-01L | 6.04 | 1 | L3
TRANS 2PNP 65V 0.1A 6TSOP | Nexperia | 1727-5391-1-ND | BCM856DS | 0.43 | 1 | Q3
MOSFET N/P-CH 30V TSOT23-6 | Diodes Incorporated | DMG6602SVT-7DICT-ND | DMG6602SVT-7 | 0.37 | 1 | Q5
MOSFET P-CH 12V 4.3A SOT-23 | Infineon | IRLML6401PBFCT-ND | IRLML6401TRPBF | 0.37 | 1 | Q6
10K OHM 0.5% 1/16W 0402 | Susumu | RR05P10.0KDCT-ND | RR0510P-103-D | 0.1 | 15 | R5 | R6 | R7 | R25 | R60 | R62 | R64 | R100 | R105 | R110 | R114 | R115 | R116 | R125 | R126
2K OHM 1% 1/16W 0402 100ppm/C | Yageo | 311-2KLRCT-ND | RC0402FR-072KL | 0.1 | 8 | R22 | R31 | R34 | R118 | R123 | R124 | R130 | R138
100 OHM 1% 1/16W 0402 | Yageo | 311-100LRCT-ND | RC0402FR-07100RL | 0.1 | 14 | R1 | R2 | R8 | R17 | R42 | R43 | R44 | R45 | R46 | R47 | R50 | R52 | R68 | R148
10K OHM 0.5% 1/16W 0402 | Susumu | RR05P10.0KDCT-ND | RR0510P-103-D | 0.1 | 18 | R5 | R6 | R7 | R25 | R58 | R60 | R62 | R64 | R100 | R105 | R110 | R114 | R115 | R116 | R125 | R126 | R133 | R147
1K OHM 1% 1/16W 0402 100ppm/C | Yageo | 311-1.00KLRCT-ND | RC0402FR-071KL | 0.1 | 11 | R15 | R16 | R18 | R35 | R39 | R63 | R72 | R81 | R87 | R98 | R99
RES 47 OHM 5% 1/16W 0402 100ppm/C | Stackpole | RMCF0402JT47R0CT-ND | RMCF0402JT47R0 | 0.1 | 29 | R48 | R49 | R51 | R53 | R54 | R55 | R56 | R57 | R59 | R61 | R65 | R66 | R111 | R112 | R113 | R131 | R132 | R134 | R135 | R136 | R137 | R139 | R140 | R141 | R142 | R143 | R144 | R145 | R146
49.9KOHM 0.5% 1/16W 0603 | Susumu | RR08P49.9KDCT-ND | RR0816P-4992-D-68C | 0.11 | 3 | R30 | R32 | R33
20K OHM 0.5% 1/16W 0603 | Susumu | RR08P20.0KDCT-ND | RR0816P-203-D | 0.11 | 2 | R12 | R75
100 OHM 0.5% 1/16W 0603 | Susumu | RR08P100DCT-ND | RR0816P-101-D | 0.11 | 4 | R36 | R37 | R83 | R119
499 OHM 1% 1/10W 0402 100ppm/C | Panasonic | P499LCT-ND | ERJ-2RKF4990X | 0.1 | 3 | R80 | R85 | R86
22 OHM 1% 1/16W 0402 | Yageo | 311-22.0LRCT-ND | RC0402FR-0722RL | 0.1 | 4 | R89 | R91 | R121 | R122
49.9 OHM 1% 1/10W 0402 100ppm/C | Panasonic | P49.9LCT-ND | ERJ-2RKF49R9X | 0.1 | 2 | R67 | R101
RES 0.5 OHM 1% 1/2W 1206 | Vishay Dale | 541-4389-1-ND | RCWE1206R500FKEA | 0.61 | 2 | R38 | R84
300 OHM 0.5% 1/16W 0402 | Susumu | RR05P300DCT-ND | RR0510P-301-D | 0.1 | 2 | R74 | R93
47K OHM 1% 1/10W 0603 | Yageo | 311-47.0KHRCT-ND | RC0603FR-0747KL | 0.1 | 2 | R96 | R97
1M OHM 0.1% 1/10W 0603 25ppm/C | Yageo | YAG4498CT-ND | RT0603BRD071ML | 0.35 | 2 | R106 | R120
200 OHM 1% 1/10W 0603 100ppm/C | Panasonic | P200HCT-ND | ERJ-3EKF2000V | 0.1 | 1 | R9
1K OHM 0.5% 1/16W 0603 | Yageo | RR08P1.0KDCT-ND | RR0816P-102-D | 0.11 | 1 | R10
49.9 OHM 1% 1/10W 0603 | Yageo | 311-49.9HRCT-ND | RC0603FR-0749R9L | 0.1 | 1 | R11
RES SMD 1 OHM 1% 1/2W 1206 | Susumu | RL16R1.0FCT-ND | RL1632R-1R00-F | 0.68 | 1 | R13
0.39 OHM 1% 1/2W 1206 | Vishay Dale | RCWE.39ECT-ND | RCWE1206R390FKEA | 0.61 | 1 | R14
300 OHM 0.5% 1/16W 0603 | Susumu | RR08P300DCT-ND | RR0816P-301-D | 0.11 | 1 | R19
2.2K OHM 0.5% 1/10W 0805 | Susumu | RR12P2.2KDCT-ND | RR1220P-222-D | 0.11 | 1 | R40
200 OHM 0.5% 1/10W 0805 | Susumu | RR12P200DCT-ND | RR1220P-201-D | 0.11 | 1 | R41
10K OHM 1% 1/10W 0603 | Yageo | 311-10.0KHRCT-ND | RC0603FR-0710KL | 0.1 | 1 | R69
RES 20 OHM 5% 1/8W 0805 | Stackpole | RMCF0805JT20R0CT-ND | RMCF0805JT20R0 | 0.1 | 1 | R70
215K OHM 0.1% 1/10W 0603 | Panasonic | P215KDBCT-ND | ERA-3AEB2153V | 0.35 | 1 | R71
36K OHM 0.5% 1/16W 0603 | Susumu | RR08P36.0KDCT-ND | RR0816P-363-D | 0.11 | 1 | R73
2.2K OHM 1% 1/10W 0603 | Yageo | 311-2.20KHRCT-ND | RC0603FR-072K2L | 0.1 | 1 | R76
71.5KOHM 0.1% 1/10W 0603 | Panasonic | P71.5KDBCT-ND | ERA-3AEB7152V | 0.35 | 1 | R77
11K OHM 0.1% 1/10W 0603 | Panasonic | P11KDBCT-ND | ERA-3AEB113V | 0.35 | 1 | R78
750 OHM 0.5% 1/16W 0402 25ppm/C | Susumu | RR05P750DCT-ND | RR0510P-751-D | 0.1 | 1 | R79
750 OHM 0.5% 1/16W 0603 | Susumu | RR08P750DCT-ND | RR0816P-751-D | 0.1 | 1 | R82
THICK FILM RESISTOR | KOA | 2019-RK73H2ETTD20R0FCT-ND | RK73H2ETTD20R0F | 0.2 | 1 | R88
220K OHM 0.1% 1/10W 0603 | Panasonic | P220KDBCT-ND | ERA-3AEB224V | 0.35 | 1 | R90
11.5KOHM 0.1% 1/10W 0603 | Panasonic | P11.5KDBCT-ND | ERA-3AEB1152V | 0.35 | 1 | R92
RES 0.056 OHM 1% 3/4W 1206 | Susumu | 408-1579-1-ND | KRL1632E-M-R056-F-T5 | 0.54 | 1 | R94
2.2K OHM 1% 1/16W 0402 100ppm/C | Yageo | 311-2.20KLRCT-ND | RC0402FR-072K2L | 0.1 | 1 | R95
RES 0.2 OHM 1% 1/2W 1206 | Susumu | RL16R.20FCT-ND | RL1632R-R200-F | 0.65 | 1 | R102
RES SMD 1.5 OHM 1% 1/2W 1206 | Susumu | RL16R1.5FCT-ND | RL1632R-1R50-F | 0.68 | 1 | R103
33.2KOHM 0.1% 1/16W 0402 25ppm/C | Panasonic | P33.2KDCCT-ND | ERA-2AEB3322X | 0.45 | 1 | R104
51K OHM 0.1% 1/10W 0603 | Panasonic | P51KDBCT-ND | ERA-3AEB513V | 0.35 | 1 | R107
4.7K OHM 5% 1/16W 0402 | Yageo | 311-4.7KJRCT-ND | RC0402JR-074K7L | 0.1 | 1 | R108
RES SMD 47 OHM 1% 1/2W 1206 | TE Connectivity | A129227CT-ND | CRGH1206F47R | 0.16 | 1 | R109
1.87KOHM 0.1% 1/10W 0603 | Panasonic | P1.87KDBCT-ND | ERA-3AEB1871V | 0.35 | 1 | R117
47 OHM 0.5% 1/16W 0603 | Susumu | RR08Q47DCT-ND | RR0816Q-470-D | 0.11 | 1 | R127
RES SMD 4.99 OHM 1% 1/8W 0805 | Yageo | 311-4.99CRCT-ND | RC0805FR-074R99L | 0.1 | 1 | R128
RES 0.1 OHM 5% 1/10W 0603 | Panasonic | P.10AHCT-ND | ERJ-3RSJR10V | 0.25 | 1 | R129
TRIMMER 500 OHM 0.25W J LEAD TOP | Bourns | 3214W-501ECT-ND | 3214W-1-501E | 3.24 | 1 | SCALE1
TRIMMER 50K OHM 0.25W J LEAD TOP | Bourns | 3214W-503ECT-ND | 3214W-1-503E | 3.24 | 1 | ZERO1
IC BUF NON-INVERT 5.5V SOT23-5 | Texas Instruments |  | SN74AHC1G125DBVR | 0.32 | 3 | U32 | U33 | U34
IC BUFFER NON-INVERT 6V 14TSSOP | Texas Instruments | 296-26461-1-ND | SN74HC125PWR | 0.36 | 3 | U35 | U36 | U37
IC CONV THERMOCOUPLE 14TSSOP | Maxim Integrated | MAX31856MUD+-ND | MAX31856MUD+ | 6.45 | 3 | U11 | U12 | U13
IC OPAMP ZERO-DRIFT 1 CIRC 8SOIC | Analog Devices | AD8628ARZ-REEL7CT-ND | AD8628ARZ-REEL7 | 2.95 | 5 | U10 | U19 | U21 | U27 | U28
24 Bit Analog to Digital Converter 4, 8 Input 1 Sigma-Delta 28-SSOP | Texas Instruments | 296-25898-1-ND | ADS1256IDBR | 14.87 | 2 | U6 | U31
RES ARRAY 4 RES 10K OHM 8TSSOP | Analog Devices | LT5400BIMS8E-1#PBF-ND | LT5400BIMS8E-1#PBF | 9.31 | 2 | U5 | U14
IC REG LINEAR 0V 500MA 12MSOP | Analog Devices | LT3045EMSE#PBF-ND | LT3045EMSE#PBF | 6.78 | 2 | U22 | U30
IC CURR SENSE 1 CIRCUIT 8SOIC | Analog Devices | AD8417WBRZ-ND | AD8417WBRZ | 3.02 | 3 | U32 | U8 | U25
7.68MHz ±30ppm Crystal 18pF 80 Ohms HC- | TXC Corporation | 887-1047-1-ND | 9C-7.680MAAJ-T | 0.46 | 1 | Y1
IC OPAMP ZERO-DRIFT 1 CIRC 8SOIC | Analog Devices | LTC2057IS8#TRPBF | LTC2057IS8#TRPBFCT-ND | 2.99 | 1 | U1
IC OPAMP DIFF 1 CIRCUIT 8SOIC | Analog Devices | AD8278BRZ | AD8278BRZ-ND | 4 | 1 | U4
IC REG LIN POS ADJ 500MA 12MSOP | Analog Devices | LT3065IMSE#PBF | LT3065IMSE#PBF-ND | 5.1 | 1 | U7
IC CURR SOURCE/SINK MIRROR 8SOIC | Texas Instruments | REF200AU | 296-44855-5-ND | 8.91 | 1 | U9
IC VREF SERIES 0.05% 8CLCC | Analog Devices | LTC6655CHLS8-2.5#PBF | LTC6655CHLS8-2.5#PBF-ND | 11.65 | 1 | U15
IC DAC 16BIT V-OUT 8VSSOP | Texas Instruments | DAC8552IDGKR | 296-46082-1-ND | 7.25 | 1 | U16
IC ANALOG SWITCH 8MSOP | Vishay Siliconix | DG419LEDQ-T1-GE3 | DG419LEDQ-T1-GE3CT-ND | 1.36 | 1 | U17
IC REG BCK SPLIT RAIL ADJ 8SOPWR | Texas Instruments | TPS54360DDA | 296-35014-ND | 5.71 | 1 | U18
SENSOR DIGITAL -55C-150C 8SOIC | Analog Devices | ADT7410TRZ-REEL7 | ADT7410TRZ-REEL7CT-ND | 3.93 | 1 | U20
IC REG CHARGE PUMP INV 8SOIC | Analog Devices | LT1054LCS8#PBF | LT1054LCS8#PBF-ND | 4.85 | 1 | U23
IC RMS TO DC CONVERTER 16SOIC | Analog Devices | AD637JRZ | AD637JRZ-ND | 24.07 | 1 | U24
IC REG LIN POS ADJ 3A 8SO PWRPAD | Texas Instruments | TPS7A7002DDA | 296-39506-5-ND | 2.8 | 1 | U26
IC RTC CLK/CALENDAR I2C 8-SOIC | Maxim Integrated | DS3231MZ+ | DS3231MZ+-ND | 7.89 | 1 | U29
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

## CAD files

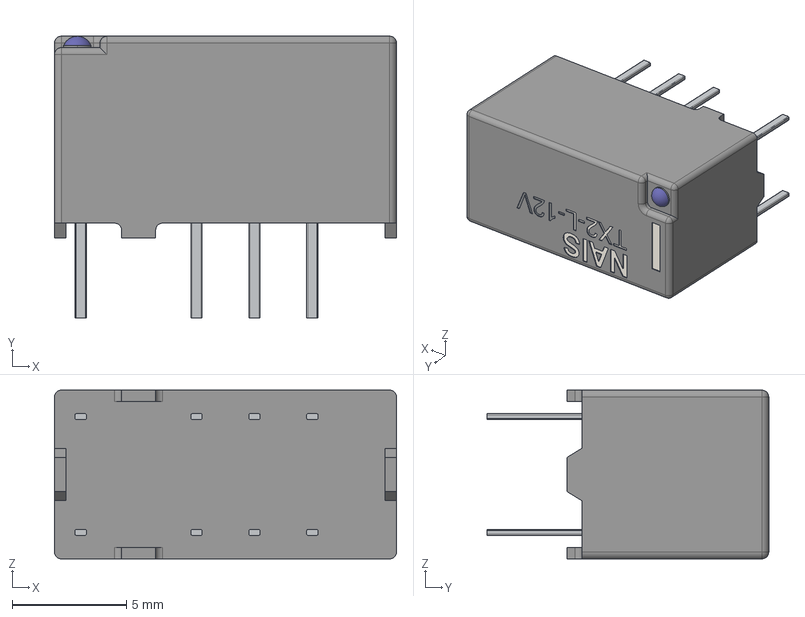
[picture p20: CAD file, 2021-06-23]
PCB/Cal_Station/STEP/TX2relay.step
15.0 x 12.3 x 7.40 mm

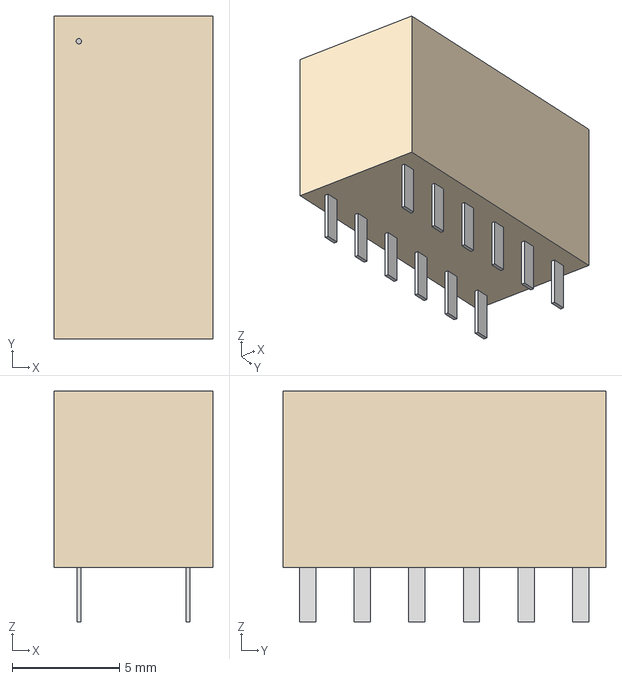
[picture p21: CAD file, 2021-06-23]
PCB/Cal_Station/STEP/RELAY_TX2_L2_PAN.step
7.39 x 15.0 x 10.7 mm

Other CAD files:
PCB/Cal_Station/STEP/User Library-TX2-L.STEP

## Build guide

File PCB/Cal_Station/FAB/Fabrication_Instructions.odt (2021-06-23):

FABRICATION INSTRUCTIONS

NOTE: ALL DIMENSIONS IN BOARD DOCUMENTS ARE IN MILLIMETERS

BOARD DIMENSIONS: 149 MM x 120 MM

NUMBER OF LAYERS: 4

1. MATERIAL: LAMINATED EPOXY GLASS FR-4, NOMINAL 1.6 MM, COLOR NATURAL

NOM 1 OZ COPPER WEIGHT. THICKNESS 1.8 MM MAX AFTER PLATING

2. SOLDERMASK OVER BARE COPPER ON TOP AND BOTTOM WITH MATERIAL PER ANSI/IPC-SM-840, COLOR SHALL BE GREEN

3. HOLES.

A. PLATING IN HOLES SHALL BE CONTINUOUS ELECTROLYTIC COPPER WITH .025 MM MINIMUM BARREL THICKNESS

B. MINIMUM HOLE SIZE: 0.2 MM

D. HOLE SIZES ARE SPECIFIED AS FINAL DIMENSIONS AFTER PLATING

4. SEE SEPARATE DRILL FILE FOR HOLE LOCATIONS

5. SURFACE FINISH. ENIG PLATING PER CURRENT REVISION OF IPC 4552

6. APPLY SILKSCREEN TO TOP AND BOTTOM SIDE OF BOARD WITH WHITE EPOXY, NON-CONDUCTIVE INK

7. DIMENSIONAL TOLERANCES ARE: .XX=+/- .01; .XXX=+/-.005

8. OUTLINE DEFINED IN SEPARATE GERBER FILE “Cal_Station-Edge_Cuts.gbr”

9. NO CONTROLLED IMPEDANCE

10. DESIGN GEOMETRY MINIMUM FEATURE SIZES:

TRACE WIDTH; 0.25 MM

TRACE-TO-TRACE; TRACE-TO-PAD 0.20 MM

HOLE-TO-HOLE 0.254 MM

PAD-TO-PAD 0.20 MM

MIN HOLE SIZE 0.2 MM

LAYER STACKUP

SOLDERMASK Cal_Station-F_Mask.gbr

SILKSCREEN Cal_Station-F_SilkS.gbr

TOP COPPER , 2 oz Cal_Station-F_Cu.gbr

DIELECTRIC

INNER COPPER LAYER #1, 1 oz Cal_Station-In1_Cu.gbr

DIELECTRIC

INNER COPPER LAYER #2 1 oz Cal_Station-In2_Cu.gbr

DIELECTRIC

BOTTOM COPPER 2 oz Cal_Station-B_Cu.gbr

SOLDER MASK Cal_Station-B_Mask.gbr

SILKSCREEN Cal_Station-B_SilkS.gbr

BOARD OUTLINE Cal_Station-Edge_Cuts.gbr

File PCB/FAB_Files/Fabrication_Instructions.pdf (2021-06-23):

FABRICATION INSTRUCTIONS

NOTE: ALL DIMENSIONS IN BOARD DOCUMENTS ARE IN MILLIMETERS

BOARD DIMENSIONS: | 125.776 MM x 175.236 MM
NUMBER OF LAYERS: | 6
1. MATERIAL: LAMINATED EPOXY GLASS FR-4, NOMINAL 1.6 MM, COLOR NATURAL NOM 2 OZ COPPER WEIGHT. THICKNESS 1.8 MM MAX AFTER PLATING
2. SOLDERMASK OVER BARE COPPER ON TOP AND BOTTOM WITH MATERIAL PER ANSI/ IPC-SM-840, COLOR SHALL BE GREEN
3. HOLES.
A. PLATING IN HOLES SHALL BE CONTINUOUS ELECTROLYTIC COPPER WITH .025 MM MINIMUM BARREL THICKNESS
B. MINIMUM HOLE SIZE: 0.2 MM
C. SEE DRILL CHART FOR FINISHED HOLE SIZE AND TOLERANCE
D. HOLE SIZES ARE SPECIFIED AS FINAL DIMENSIONS AFTER PLATING
4. SEE SEPARATE DRILL FILE FOR HOLE LOCATIONS
5. SURFACE FINISH. ENIG PLATING PER CURRENT REVISION OF IPC 4552
6. APPLY SILKSCREEN TO TOP AND BOTTOM SIDE OF BOARD WITH WHITE EPOXY, NON-CONDUCTIVE INK
7. DIMENSIONAL TOLERANCES ARE: .XX=+/- .01; .XXX=+/-.005
8. OUTLINE DEFINED IN SEPARATE GERBER FILE “Pi_Blackbox-Edge_Cuts.gbr”
9. NO CONTROLLED IMPEDANCE
10. DESIGN GEOMETRY MINIMUM FEATURE SIZES:
TRACE WIDTH; | 0.25 MM
TRACE-TO-TRACE; TRACE-TO-PAD | 0.19 MM
HOLE-TO-HOLE | 0.254 MM
PAD-TO-PAD | 0.19 MM
MIN HOLE SIZE | 0.2 MM

LAYER STACKUP

SOLDERMASK | Pi_Blackbox-F_Mask.gbr
SILKSCREEN | Pi_Blackbox-F_SilkS.gbr
TOP COPPER, 2 oz | Pi_Blackbox-F_Cu.gbr
DIELECTRIC
INNER COPPER LAYER #1, 1 oz | Pi_Blackbox-In1_Cu.gbr
DIELECTRIC
INNER COPPER LAYER #2 1 oz | Pi_Blackbox-In2_Cu.gbr
DIELECTRIC
INNER COPPER LAYER #3 1 oz | Pi_Blackbox-In3_Cu.gbr
DIELECTRIC
INNER COPPER LAYER #4 1 oz | Pi_Blackbox-In4_Cu.gbr
DIELECTRIC
BOTTOM COPPER 2 oz | Pi_Blackbox-B_Cu.gbr
SOLDER MASK | Pi_Blackbox-B_Mask.gbr
SILKSCREEN | Pi_Blackbox-B_SilkS.gbr

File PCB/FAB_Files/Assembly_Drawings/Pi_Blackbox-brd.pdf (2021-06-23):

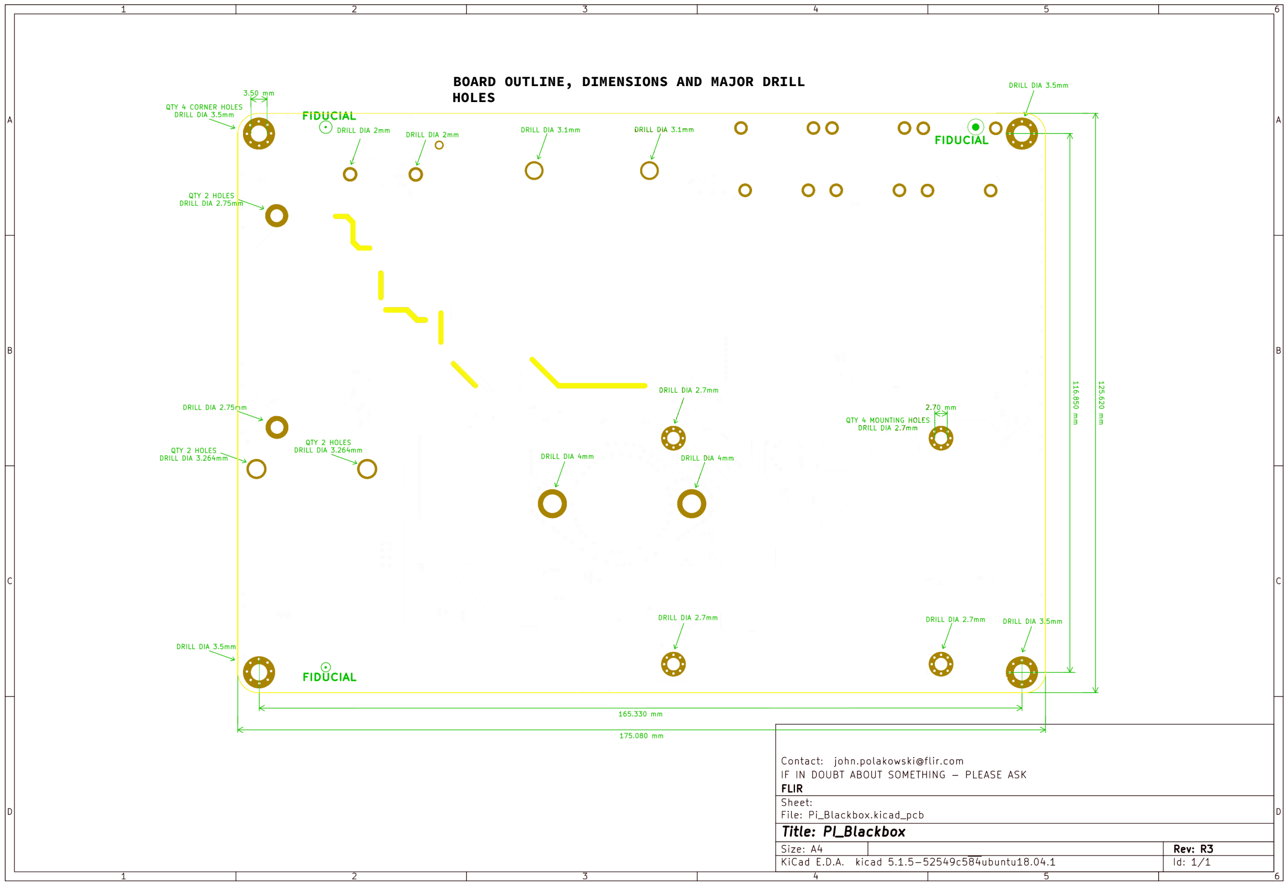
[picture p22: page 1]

BOARD OUTLINE, DIMENSIONS AND MAJOR DRILL HOLES

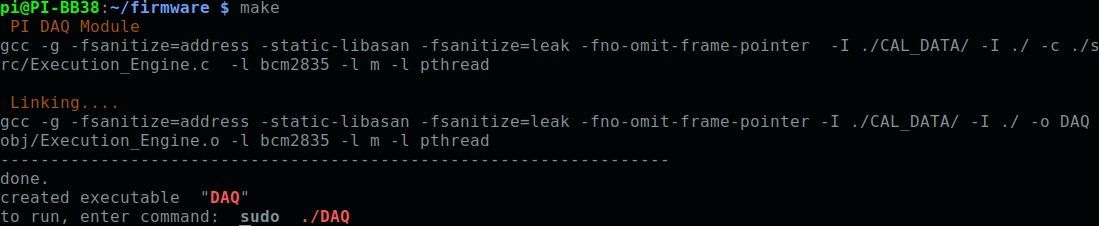
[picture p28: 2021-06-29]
md/make_daq.png

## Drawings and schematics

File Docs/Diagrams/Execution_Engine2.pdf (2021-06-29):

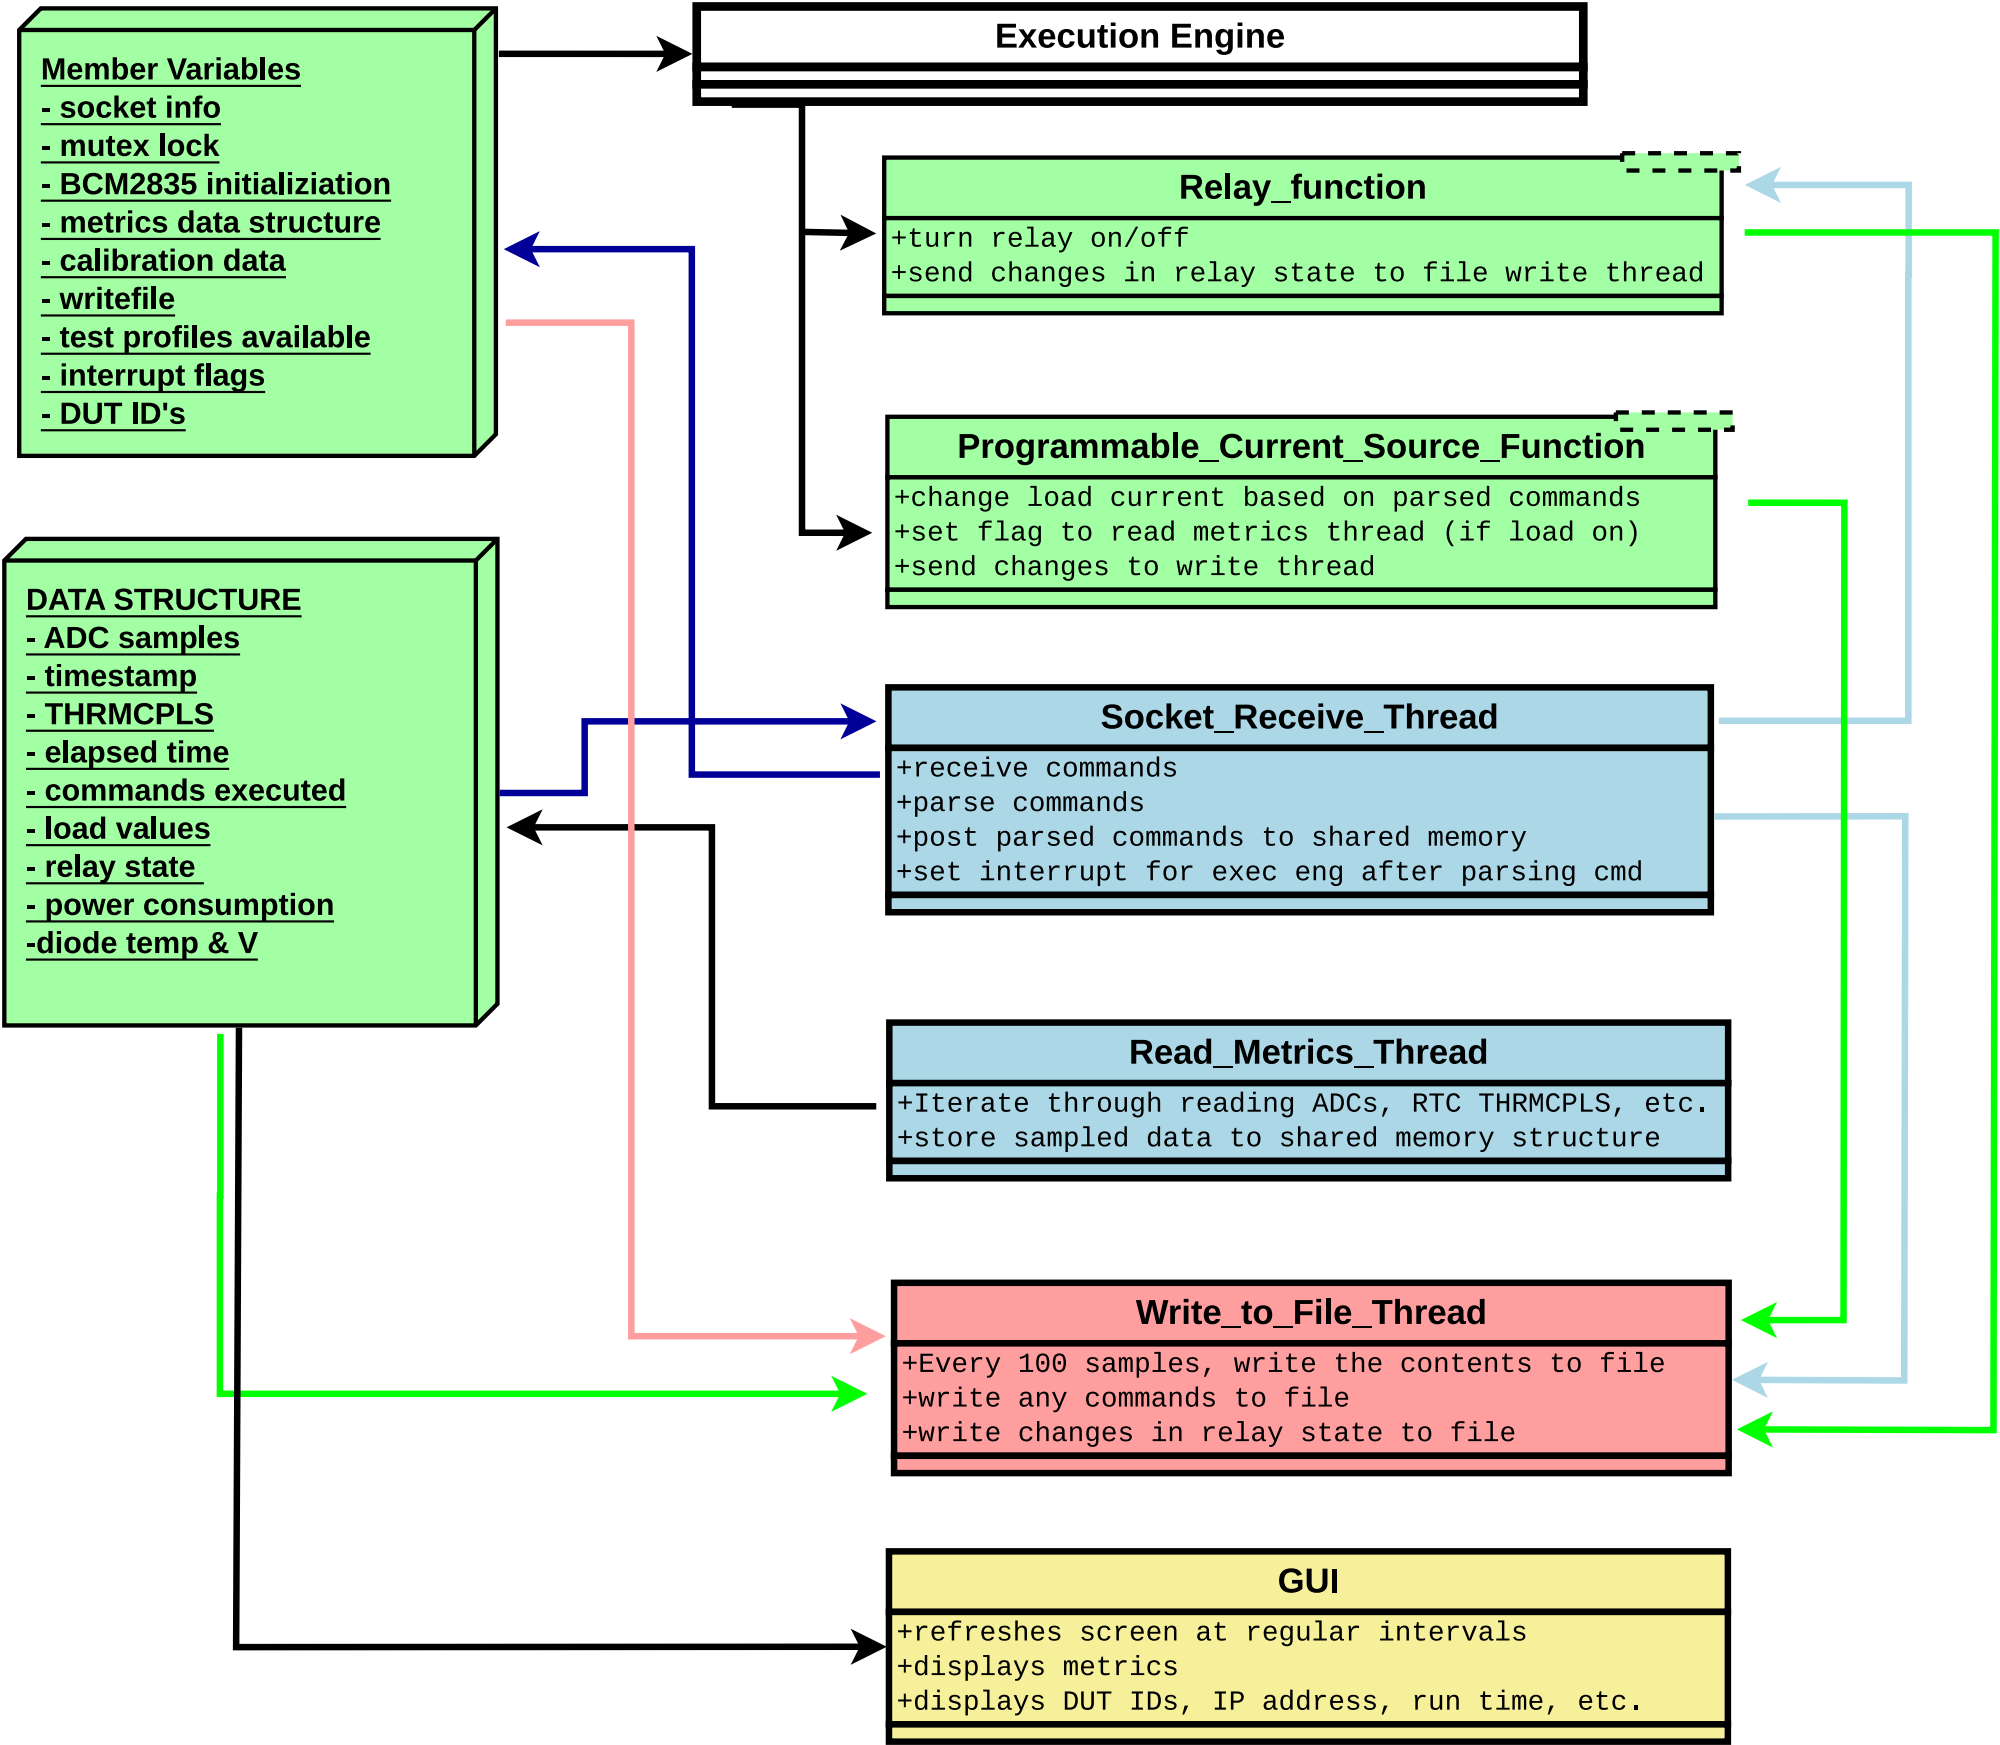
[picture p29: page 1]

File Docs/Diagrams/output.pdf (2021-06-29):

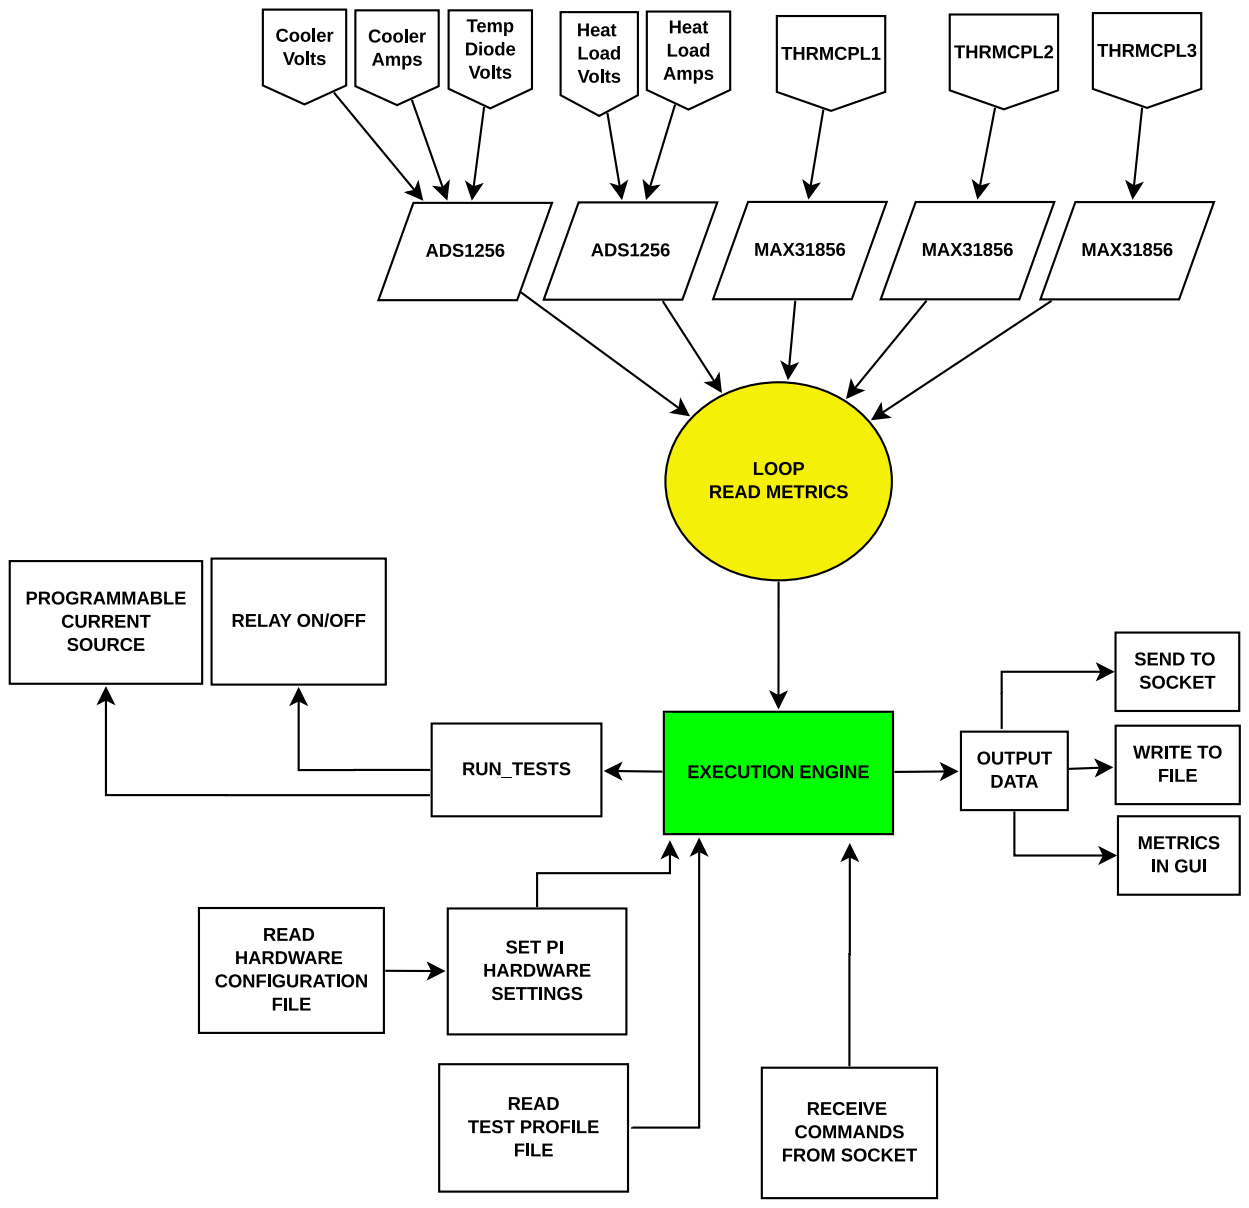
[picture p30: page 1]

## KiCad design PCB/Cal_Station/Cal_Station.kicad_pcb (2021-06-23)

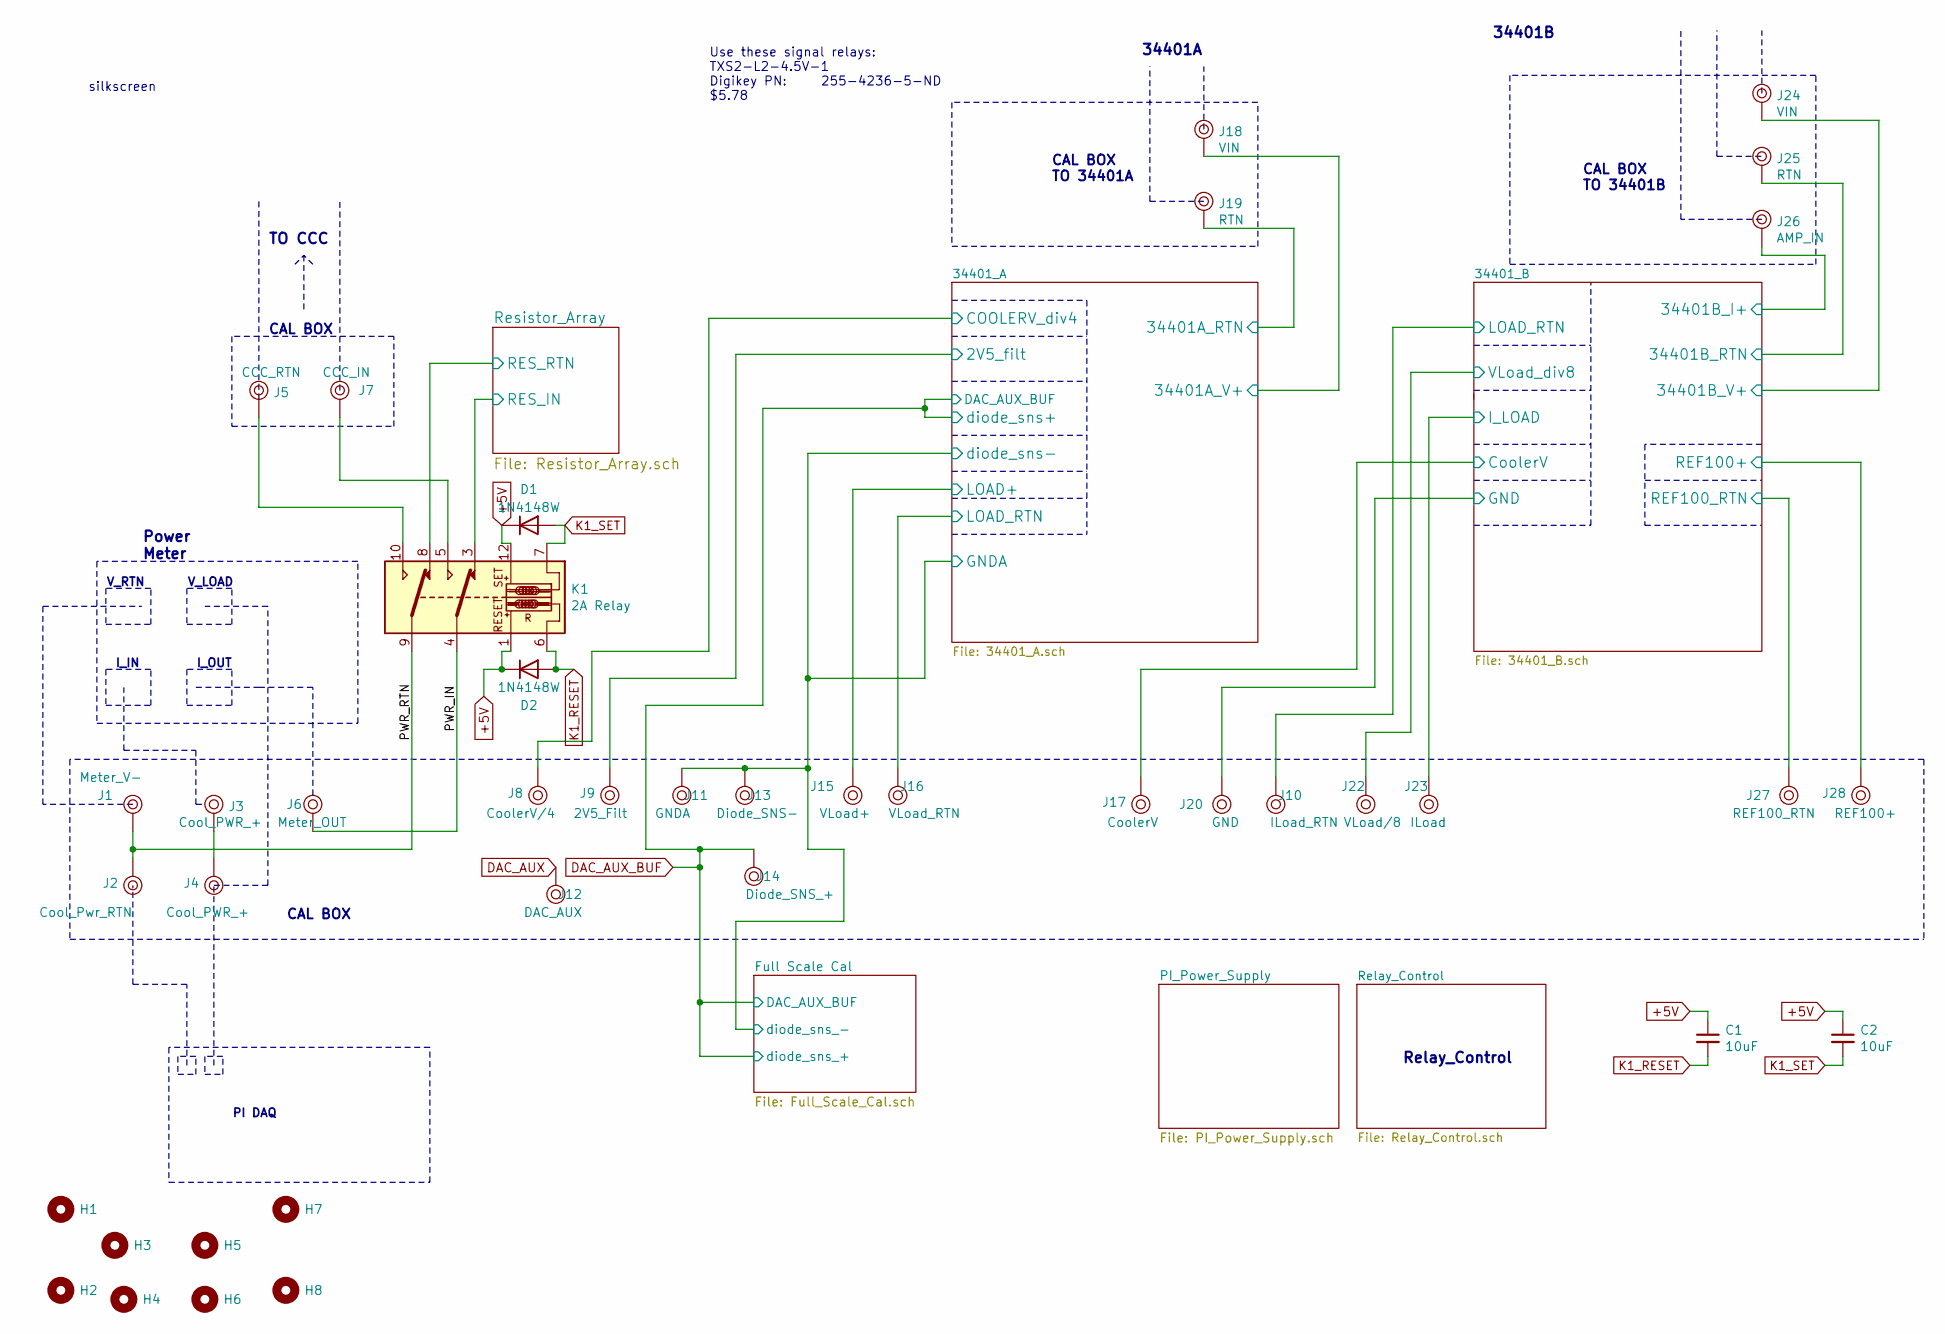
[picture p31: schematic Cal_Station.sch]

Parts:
C1, C2: 10uF; C_0805_2012Metric_Pad1.15x1.40mm_HandSolder
D1, D2: 1N4148W; D_SOD-123
H1, H2, H3, H4: MountingHole; MountingHole_2.7mm_M2.5_Pad_Via
H5, H6, H7, H8: MountingHole; MountingHole_3.2mm_M3_Pad_Via
J1: Meter_V-; TestPoint_THTPad_D3.0mm_Drill1.5mm; MPN 105-1102-001; Digi-Key_PN J576-ND
J2: Cool_Pwr_RTN; TestPoint_THTPad_D3.0mm_Drill1.5mm; MPN 105-1102-001; Digi-Key_PN J576-ND
J3, J4: Cool_PWR_+; TestPoint_THTPad_D3.0mm_Drill1.5mm; MPN 105-1102-001; Digi-Key_PN J576-ND
J5: CCC_RTN; TestPoint_THTPad_D3.0mm_Drill1.5mm; MPN 105-1102-001; Digi-Key_PN J576-ND
J6: Meter_OUT; TestPoint_THTPad_D3.0mm_Drill1.5mm; MPN 105-1102-001; Digi-Key_PN J576-ND
J7: CCC_IN; TestPoint_THTPad_D3.0mm_Drill1.5mm; MPN 105-1102-001; Digi-Key_PN J576-ND
J8: CoolerV/4; TestPoint_THTPad_D3.0mm_Drill1.5mm; MPN 105-1102-001; Digi-Key_PN J576-ND
J9: 2V5_Filt; TestPoint_THTPad_D3.0mm_Drill1.5mm; MPN 105-1102-001; Digi-Key_PN J576-ND
J10: ILoad_RTN; TestPoint_THTPad_D3.0mm_Drill1.5mm; MPN 105-1102-001; Digi-Key_PN J576-ND
J11: GNDA; TestPoint_THTPad_D3.0mm_Drill1.5mm; MPN 105-1102-001; Digi-Key_PN J576-ND
J12: DAC_AUX; TestPoint_THTPad_D3.0mm_Drill1.5mm; MPN 105-1102-001; Digi-Key_PN J576-ND
J13: Diode_SNS-; TestPoint_THTPad_D3.0mm_Drill1.5mm; MPN 105-1102-001; Digi-Key_PN J576-ND
J14: Diode_SNS_+; TestPoint_THTPad_D3.0mm_Drill1.5mm; MPN 105-1102-001; Digi-Key_PN J576-ND
J15: VLoad+; TestPoint_THTPad_D3.0mm_Drill1.5mm; MPN 105-1102-001; Digi-Key_PN J576-ND
J16: VLoad_RTN; TestPoint_THTPad_D3.0mm_Drill1.5mm; MPN 105-1102-001; Digi-Key_PN J576-ND
J17: CoolerV; TestPoint_THTPad_D3.0mm_Drill1.5mm; MPN 105-1102-001; Digi-Key_PN J576-ND
J18, J24: VIN; TestPoint_THTPad_D3.0mm_Drill1.5mm; MPN 105-1102-001; Digi-Key_PN J576-ND
J19, J25: RTN; TestPoint_THTPad_D3.0mm_Drill1.5mm; MPN 105-1102-001; Digi-Key_PN J576-ND
J20: GND; TestPoint_THTPad_D3.0mm_Drill1.5mm; MPN 105-1102-001; Digi-Key_PN J576-ND
J22: VLoad/8; TestPoint_THTPad_D3.0mm_Drill1.5mm; MPN 105-1102-001; Digi-Key_PN J576-ND
J23: ILoad; TestPoint_THTPad_D3.0mm_Drill1.5mm; MPN 105-1102-001; Digi-Key_PN J576-ND
J26: AMP_IN; TestPoint_THTPad_D3.0mm_Drill1.5mm; MPN 105-1102-001; Digi-Key_PN J576-ND
J27: REF100_RTN; TestPoint_THTPad_D3.0mm_Drill1.5mm; MPN 105-1102-001; Digi-Key_PN J576-ND
J28: REF100+; TestPoint_THTPad_D3.0mm_Drill1.5mm; MPN 105-1102-001; Digi-Key_PN J576-ND
K1: 2A Relay; Panasonic_TX2_2

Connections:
/34401_A/2V5_filt: J9.1; also elsewhere on the board
/34401_A/34401A_RTN: J19.1; also elsewhere on the board
/34401_A/34401A_V+: J18.1; also elsewhere on the board
/34401_A/COOLERV_div4: J8.1; also elsewhere on the board
/34401_A/GNDA: J11.1, J13.1; also elsewhere on the board
/34401_A/LOAD+: J15.1; also elsewhere on the board
/34401_A/LOAD_RTN: J16.1; also elsewhere on the board
/34401_B/34401B_I+: J26.1; also elsewhere on the board
/34401_B/34401B_RTN: J25.1; also elsewhere on the board
/34401_B/34401B_V+: J24.1; also elsewhere on the board
/34401_B/CoolerV: J17.1; also elsewhere on the board
/34401_B/GND: J20.1; also elsewhere on the board
/34401_B/I_LOAD: J23.1; also elsewhere on the board
/34401_B/LOAD_RTN: J10.1; also elsewhere on the board
/34401_B/REF100+: J28.1; also elsewhere on the board
/34401_B/REF100_RTN: J27.1; also elsewhere on the board
/34401_B/VLoad_div8: J22.1; also elsewhere on the board
/PWR_IN: J6.1, K1.4
/PWR_RTN: J1.1, J2.1, K1.9
/Resistor_Array/RES_IN: K1.3; also elsewhere on the board
/Resistor_Array/RES_RTN: K1.8; also elsewhere on the board
DAC_AUX: J12.1; also elsewhere on the board
DAC_AUX_BUF: J14.1; also elsewhere on the board
K1_RESET: C1.2, D2.2 (A), K1.6; also elsewhere on the board
K1_SET: C2.2, D1.2 (A), K1.7; also elsewhere on the board
unnamed: J3.1, J4.1
unnamed: J5.1, K1.10
unnamed: J7.1, K1.5

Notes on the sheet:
34401A
34401B
Power Meter
Use these signal relays: TXS2-L2-4.5V-1 Digikey PN: 255-4236-5-ND $5.78
TO CCC
V_RTN
PI DAQ
V_LOAD
I_OUT
I_IN
CAL BOX
CAL BOX TO 34401A
CAL BOX TO 34401B
Relay_Control
silkscreen

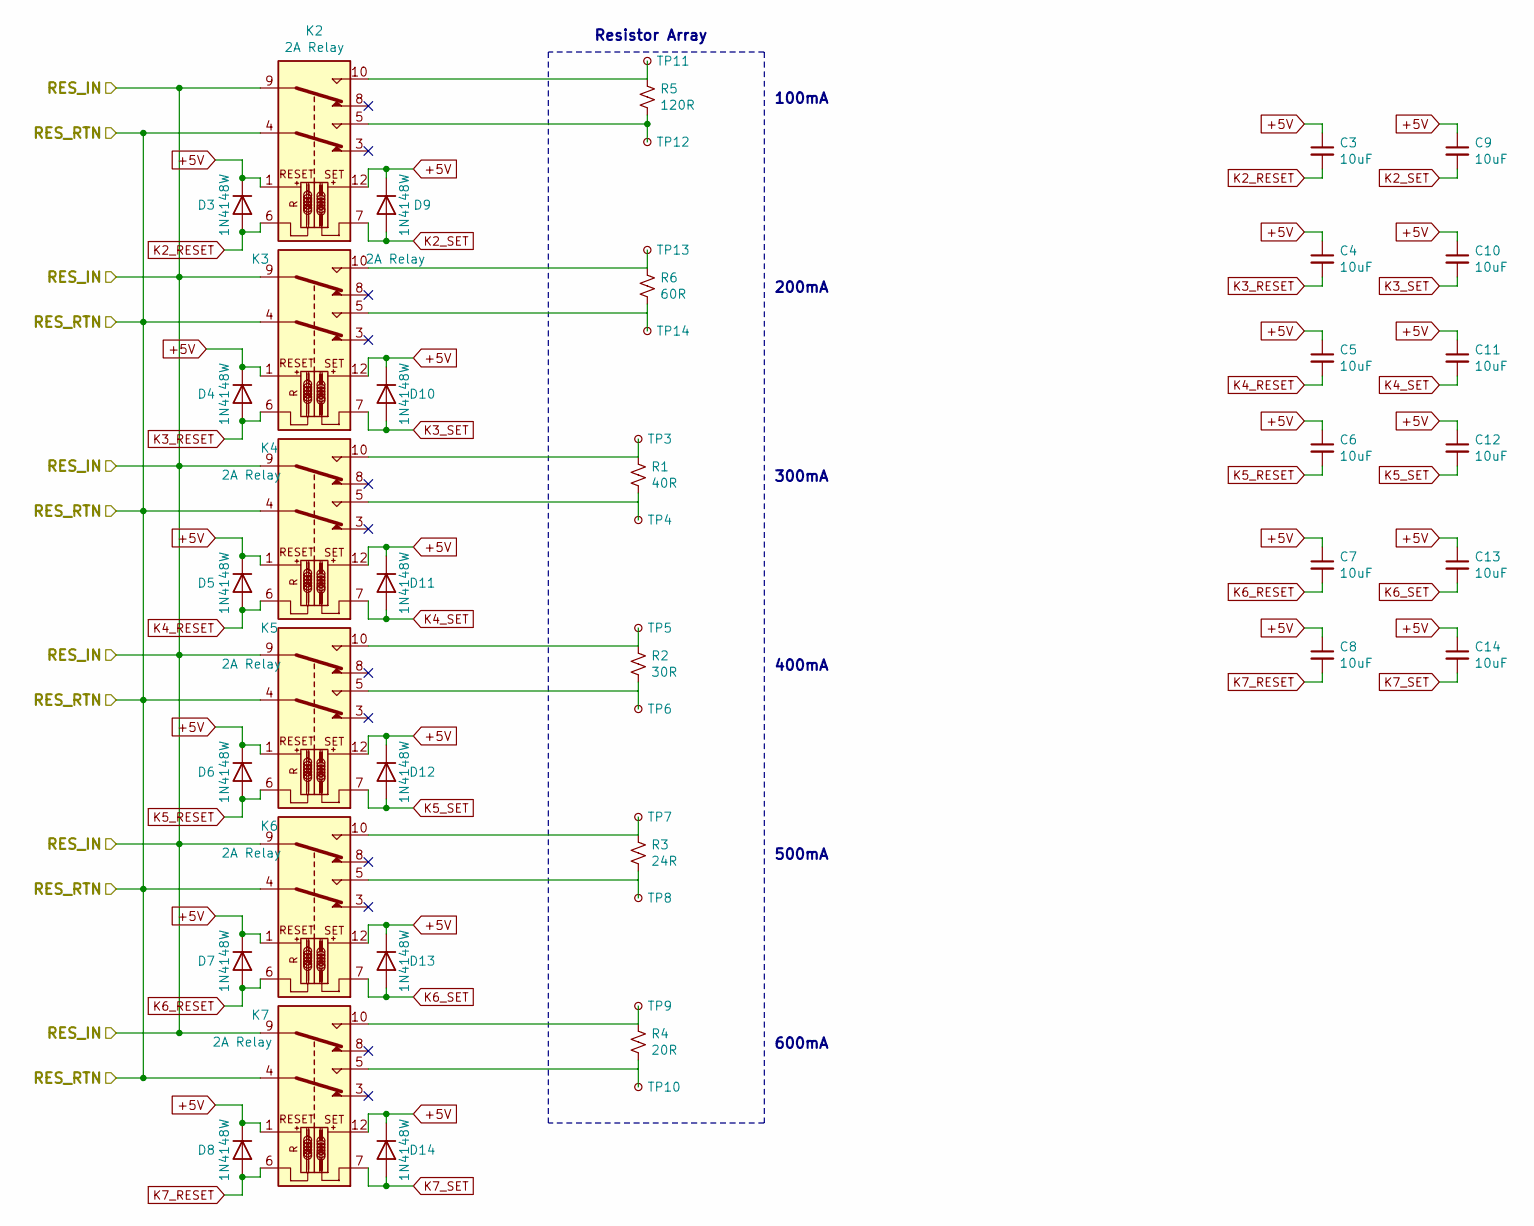
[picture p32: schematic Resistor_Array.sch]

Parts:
C3, C4, C5, C6, C7, C8, C9, C10, C11, C12, C13, C14: 10uF; C_0805_2012Metric_Pad1.15x1.40mm_HandSolder
D3, D4, D5, D6, D7, D8, D9, D10, D11, D12, D13, D14: 1N4148W; D_SOD-123
K2, K3, K4, K5, K6, K7: 2A Relay; Panasonic_TX2_2
R1: 40R
R2: 30R
R3: 24R
R4: 20R
R5: 120R
R6: 60R
TP3, TP4, TP5, TP6, TP7, TP8, TP9, TP10, TP11, TP12, TP13, TP14: TestPoint_Small; TestPoint_THTPad_D3.0mm_Drill1.5mm

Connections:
/Resistor_Array/RES_IN: K2.9, K3.9, K4.9, K5.9, K6.9, K7.9; also elsewhere on the board
/Resistor_Array/RES_RTN: K2.4, K3.4, K4.4, K5.4, K6.4, K7.4; also elsewhere on the board
K2_RESET: C3.2, D3.2 (A), K2.6; also elsewhere on the board
K2_SET: C9.2, D9.2 (A), K2.7; also elsewhere on the board
K3_RESET: C4.2, D4.2 (A), K3.6; also elsewhere on the board
K4_RESET: C5.2, D5.2 (A), K4.6; also elsewhere on the board
K4_SET: C11.2, D11.2 (A), K4.7; also elsewhere on the board
K5_RESET: C6.2, D6.2 (A), K5.6; also elsewhere on the board
K5_SET: C12.2, D12.2 (A), K5.7; also elsewhere on the board
K6_RESET: C7.2, D7.2 (A), K6.6; also elsewhere on the board
K6_SET: C13.2, D13.2 (A), K6.7; also elsewhere on the board
K7_RESET: C8.2, D8.2 (A), K7.6; also elsewhere on the board
K7_SET: C14.2, D14.2 (A), K7.7; also elsewhere on the board
unnamed: K2.5, R5.1, TP12.1
unnamed: K2.10, R5.2, TP11.1
unnamed: K3.5, R6.1, TP14.1
unnamed: K3.10, R6.2, TP13.1
unnamed: K4.5, R1.1, TP4.1
unnamed: K4.10, R1.2, TP3.1
unnamed: K5.5, R2.1, TP6.1
unnamed: K5.10, R2.2, TP5.1
unnamed: K6.5, R3.1, TP8.1
unnamed: K6.10, R3.2, TP7.1
unnamed: K7.5, R4.1, TP10.1
unnamed: K7.10, R4.2, TP9.1

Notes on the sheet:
100mA
200mA
300mA
400mA
500mA
600mA
Resistor Array

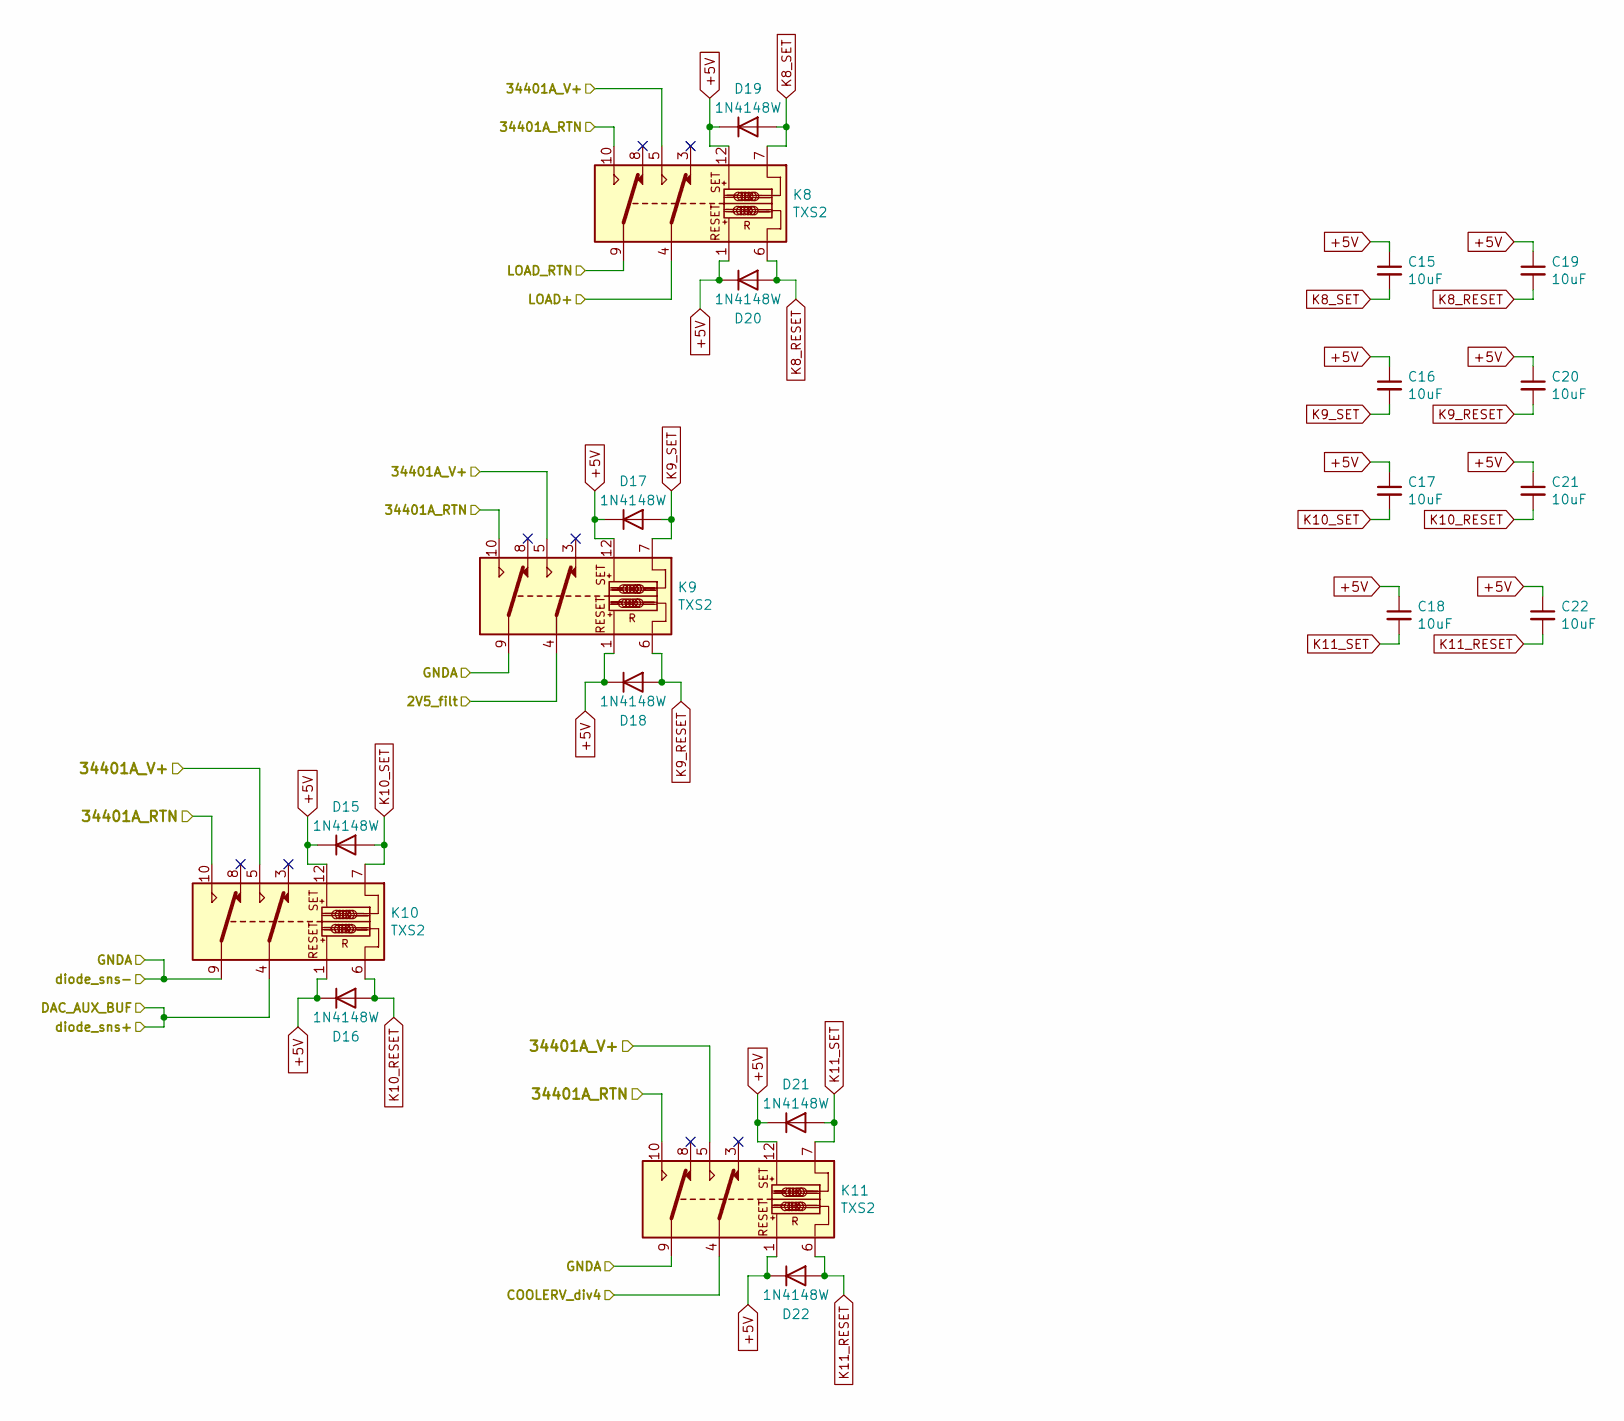
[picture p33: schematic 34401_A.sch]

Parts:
C15, C16, C17, C18, C19, C20, C21, C22: 10uF; C_0805_2012Metric_Pad1.15x1.40mm_HandSolder
D15, D16, D17, D18, D19, D20, D21, D22: 1N4148W; D_SOD-123
K8, K9, K10, K11: TXS2; Panasonic_TX2_2

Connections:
/34401_A/2V5_filt: K9.4; also elsewhere on the board
/34401_A/34401A_RTN: K8.10, K9.10, K10.10, K11.10; also elsewhere on the board
/34401_A/34401A_V+: K8.5, K9.5, K10.5, K11.5; also elsewhere on the board
/34401_A/COOLERV_div4: K11.4; also elsewhere on the board
/34401_A/GNDA: K9.9, K10.9, K11.9; also elsewhere on the board
/34401_A/LOAD+: K8.4; also elsewhere on the board
/34401_A/LOAD_RTN: K8.9; also elsewhere on the board
DAC_AUX_BUF: K10.4; also elsewhere on the board
K8_RESET: C19.2, D20.2 (A), K8.6; also elsewhere on the board
K8_SET: C15.2, D19.2 (A), K8.7; also elsewhere on the board
K9_RESET: C20.2, D18.2 (A), K9.6; also elsewhere on the board
K9_SET: C16.2, D17.2 (A), K9.7; also elsewhere on the board
K10_RESET: C21.2, D16.2 (A), K10.6; also elsewhere on the board
K10_SET: C17.2, D15.2 (A), K10.7; also elsewhere on the board
K11_RESET: C22.2, D22.2 (A), K11.6; also elsewhere on the board
K11_SET: C18.2, D21.2 (A), K11.7; also elsewhere on the board

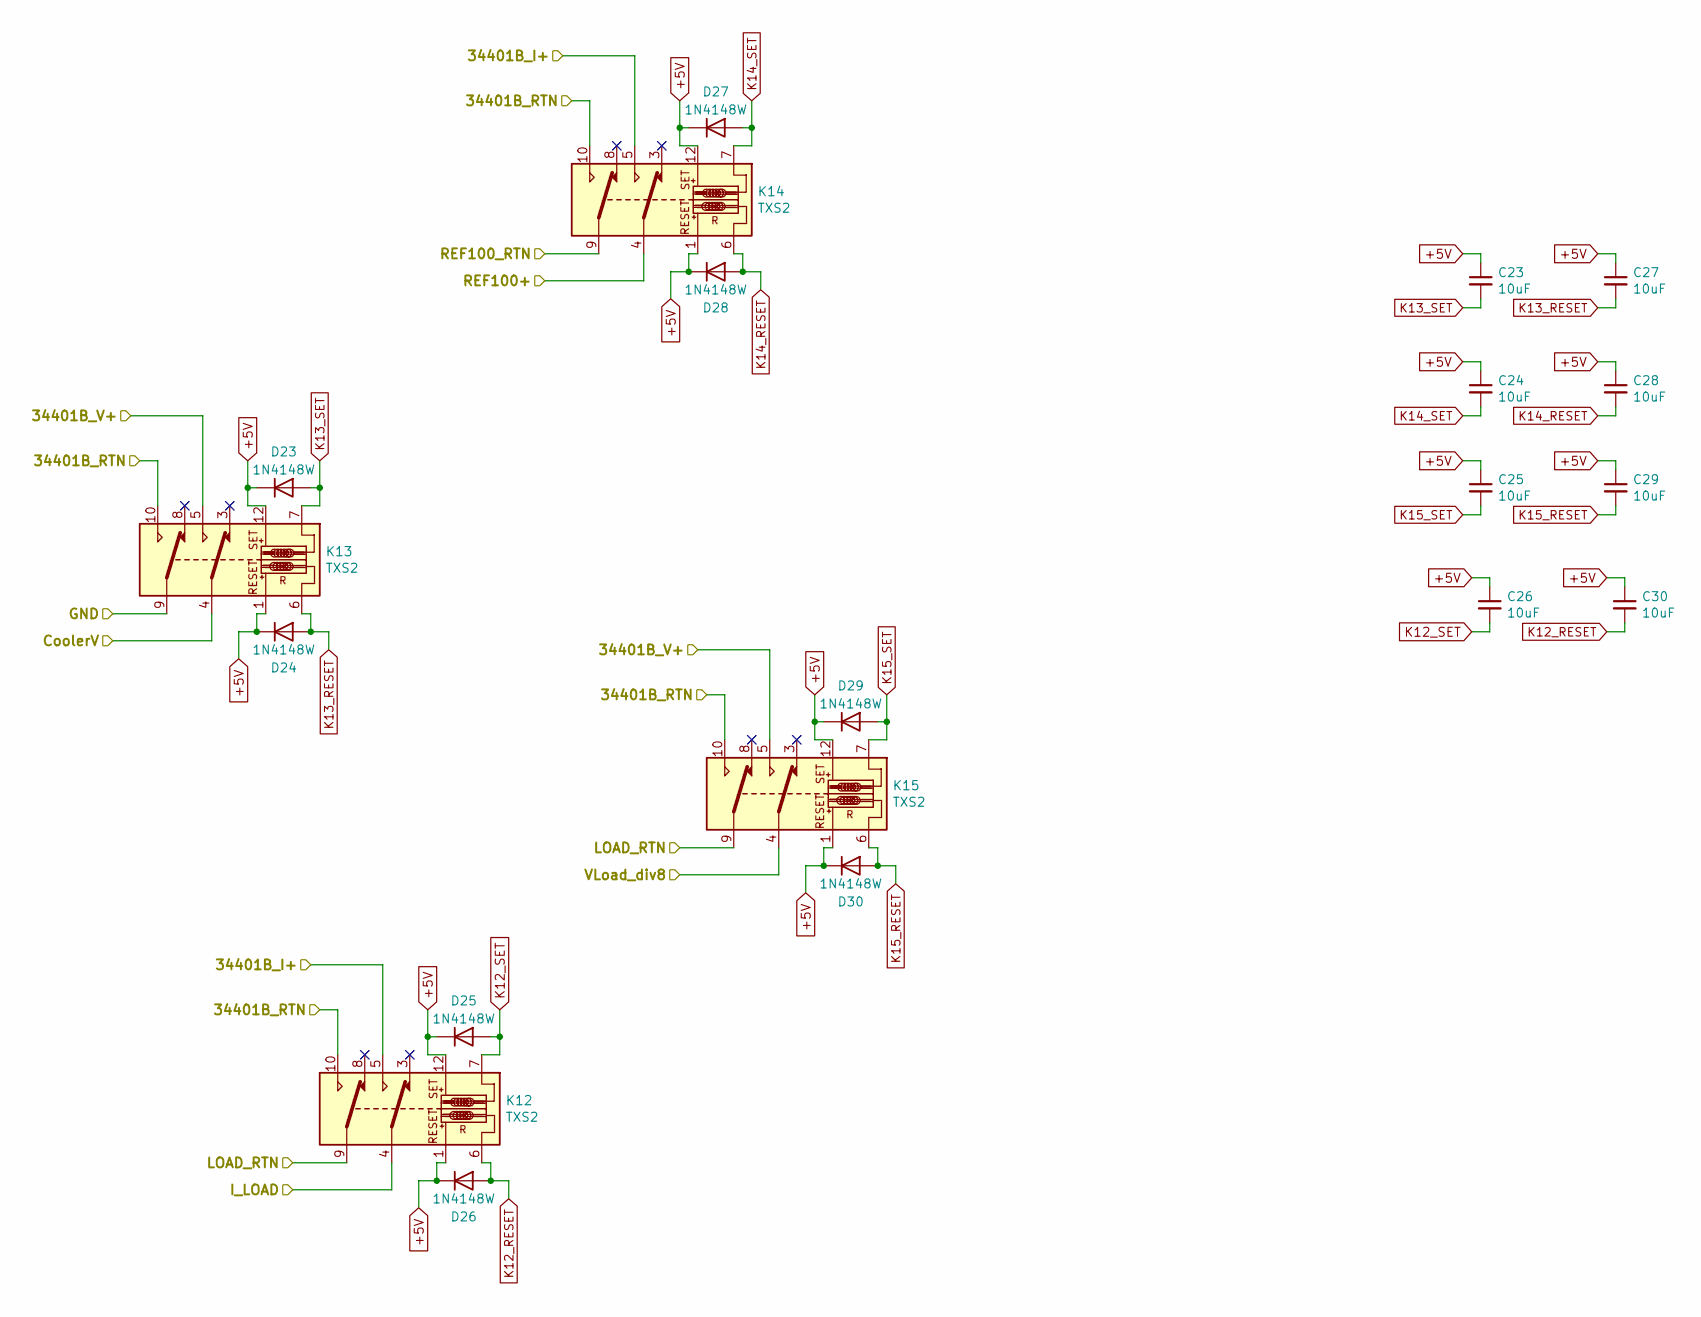
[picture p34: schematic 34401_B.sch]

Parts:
C23, C24, C25, C26, C27, C28, C29, C30: 10uF; C_0805_2012Metric_Pad1.15x1.40mm_HandSolder
D23, D24, D25, D26, D27, D28, D29, D30: 1N4148W; D_SOD-123
K12, K13, K14, K15: TXS2; Panasonic_TX2_2

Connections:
/34401_B/34401B_I+: K12.5, K14.5; also elsewhere on the board
/34401_B/34401B_RTN: K12.10, K13.10, K14.10, K15.10; also elsewhere on the board
/34401_B/34401B_V+: K13.5, K15.5; also elsewhere on the board
/34401_B/CoolerV: K13.4; also elsewhere on the board
/34401_B/GND: K13.9; also elsewhere on the board
/34401_B/I_LOAD: K12.4; also elsewhere on the board
/34401_B/LOAD_RTN: K12.9, K15.9; also elsewhere on the board
/34401_B/REF100+: K14.4; also elsewhere on the board
/34401_B/REF100_RTN: K14.9; also elsewhere on the board
/34401_B/VLoad_div8: K15.4; also elsewhere on the board
K12_RESET: C30.2, D26.2 (A), K12.6; also elsewhere on the board
K12_SET: C26.2, D25.2 (A), K12.7; also elsewhere on the board
K13_RESET: C27.2, D24.2 (A), K13.6; also elsewhere on the board
K13_SET: C23.2, D23.2 (A), K13.7; also elsewhere on the board
K14_RESET: C28.2, D28.2 (A), K14.6; also elsewhere on the board
K14_SET: C24.2, D27.2 (A), K14.7; also elsewhere on the board
K15_RESET: C29.2, D30.2 (A), K15.6; also elsewhere on the board
K15_SET: C25.2, D29.2 (A), K15.7; also elsewhere on the board

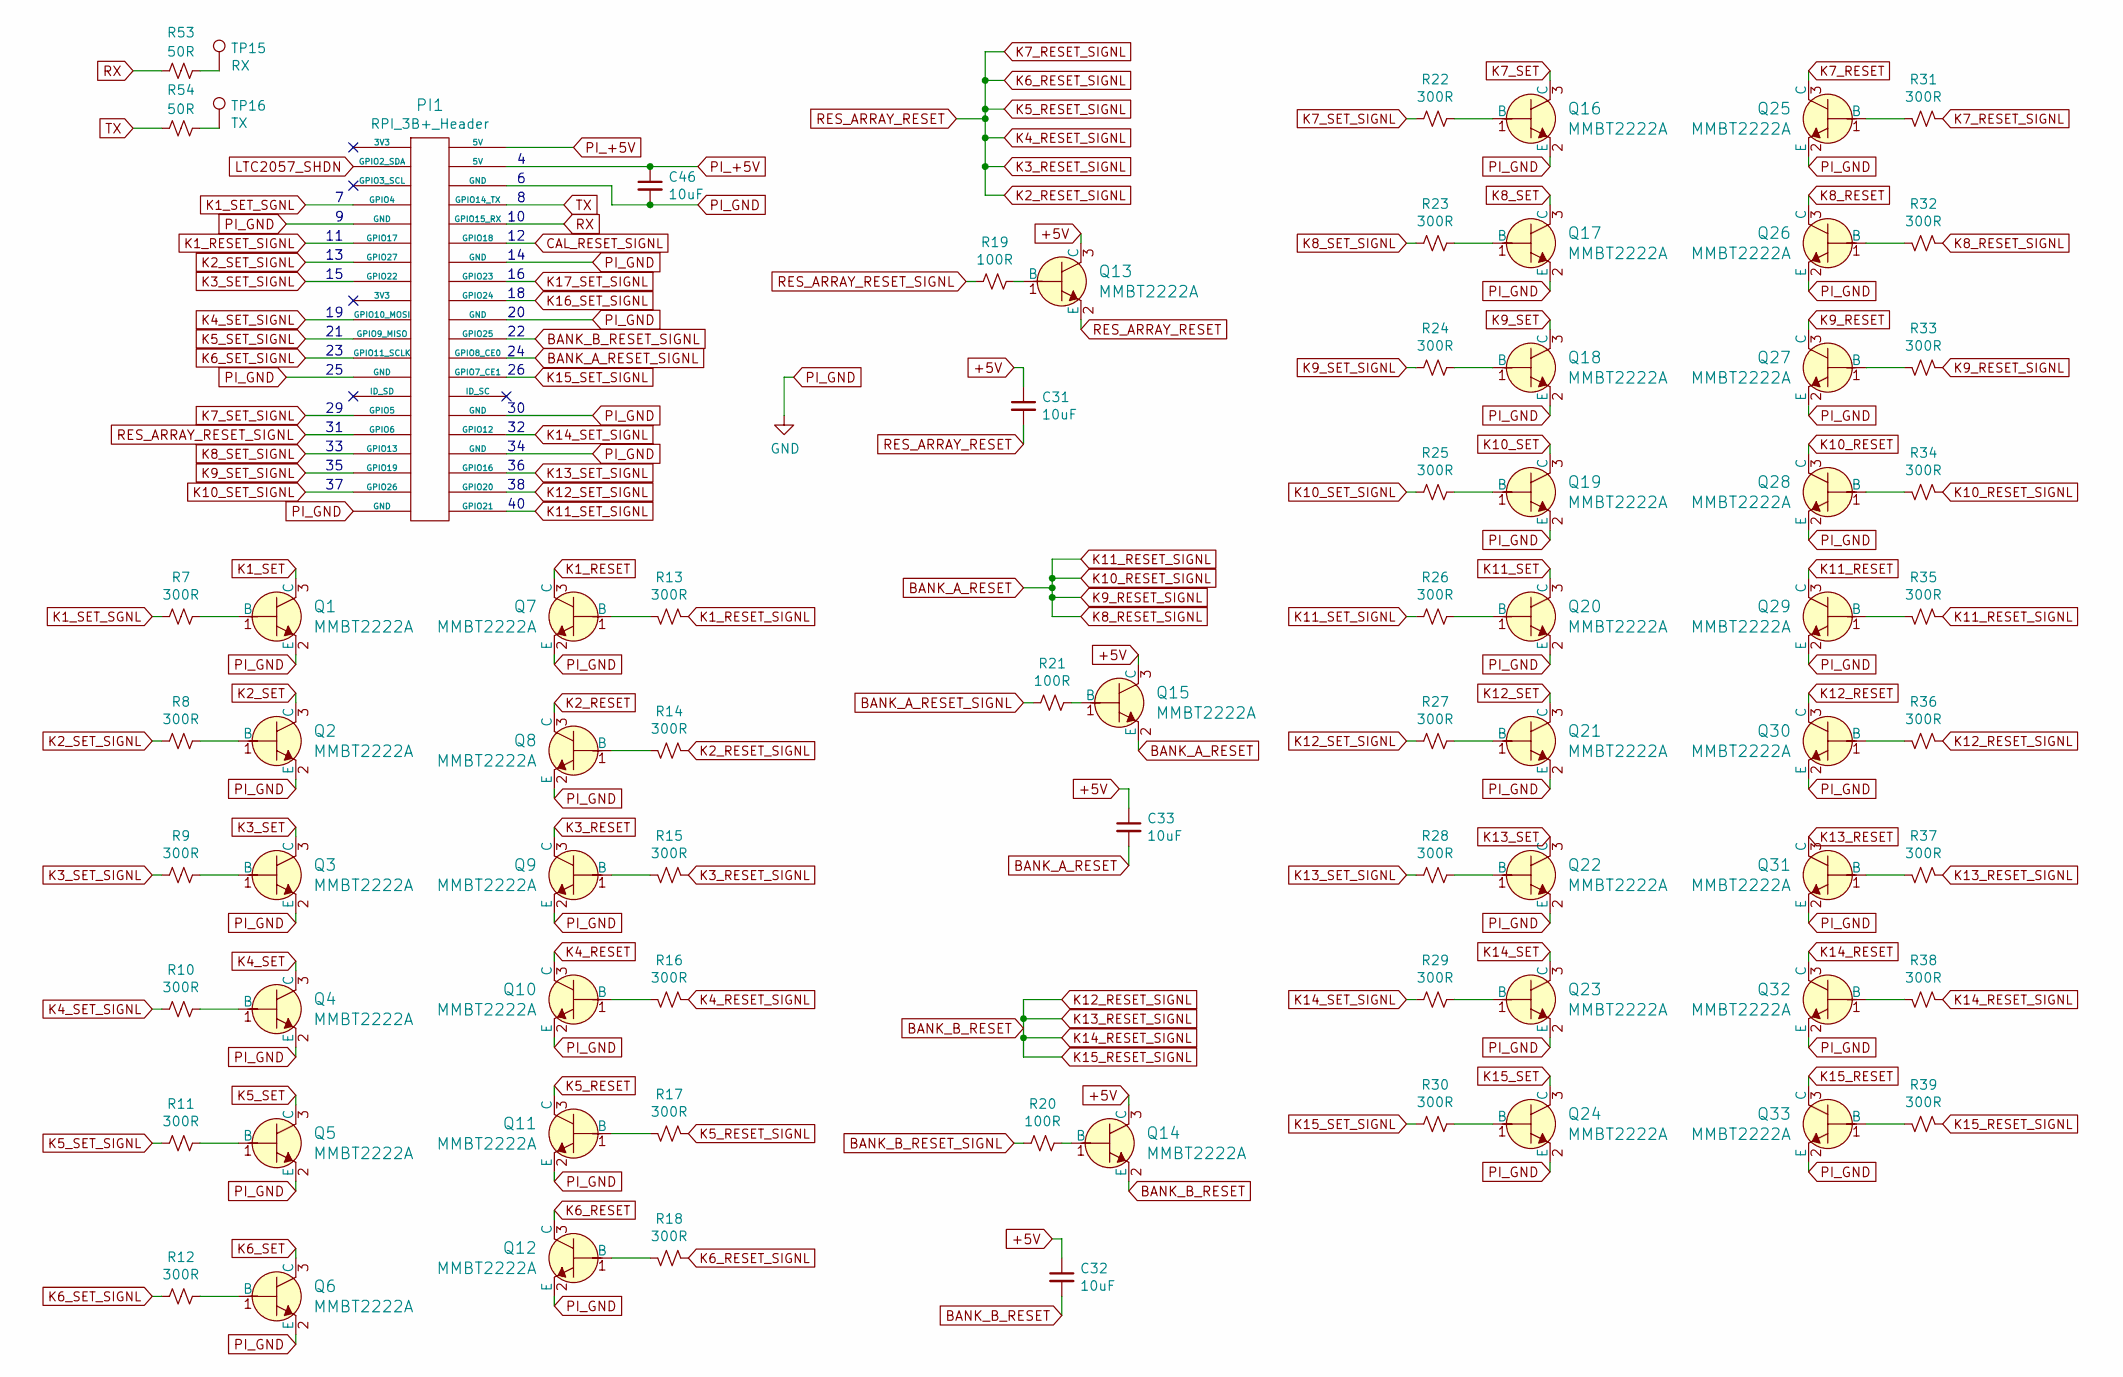
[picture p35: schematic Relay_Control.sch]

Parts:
C31, C32, C33, C46: 10uF; C_0805_2012Metric_Pad1.15x1.40mm_HandSolder
PI1: RPI_3B+_Header; PinHeader_2x20_P2.54mm_Vertical
Q1, Q2, Q3, Q4, Q5, Q6, Q7, Q8, Q9, Q10, Q11, Q12, Q13, Q14, Q15, Q16, Q17, Q18, Q19, Q20, Q21, Q22, Q23, Q24, Q25, Q26, Q27, Q28, Q29, Q30, Q31, Q32, Q33: MMBT2222A; SOT-23-3; MPN MMBT2222A-7-F; Digi-Key_PN MMBT2222A-FDICT-ND
R7, R8, R9, R10, R11, R12, R13, R14, R15, R16, R17, R18, R22, R23, R24, R25, R26, R27, R28, R29, R30, R31, R32, R33, R34, R35, R36, R37, R38, R39: 300R; C_0402_1005Metric
R19, R20, R21: 100R; C_0402_1005Metric
R53, R54: 50R; C_0402_1005Metric
TP15: RX; TestPoint_Pad_D2.5mm
TP16: TX; TestPoint_Pad_D2.5mm

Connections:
BANK_A_RESET: C33.2, Q15.2 (E), R32.2, R33.2, R34.2, R35.2
BANK_A_RESET_SIGNL: PI1.24 (GPIO8_CE0), R21.2
BANK_B_RESET: C32.2, Q14.2 (E), R36.2, R37.2, R38.2, R39.2
BANK_B_RESET_SIGNL: PI1.22 (GPIO25), R20.2
CAL_RESET_SIGNL: PI1.12 (GPIO18); also elsewhere on the board
K1_RESET: Q7.3 (C); also elsewhere on the board
K1_RESET_SIGNL: PI1.11 (GPIO17), R13.2
K1_SET: Q1.3 (C); also elsewhere on the board
K1_SET_SGNL: PI1.7 (GPIO4), R7.2
K2_RESET: Q8.3 (C); also elsewhere on the board
K2_RESET_SIGNL: C31.2, Q13.2 (E), R14.2, R15.2, R16.2, R17.2, R18.2, R31.2
K2_SET: Q2.3 (C); also elsewhere on the board
K2_SET_SIGNL: PI1.13 (GPIO27), R8.2
K3_RESET: Q9.3 (C); also elsewhere on the board
K3_SET_SIGNL: PI1.15 (GPIO22), R9.2
K4_RESET: Q10.3 (C); also elsewhere on the board
K4_SET: Q4.3 (C); also elsewhere on the board
K4_SET_SIGNL: PI1.19 (GPIO10_MOSI), R10.2
K5_RESET: Q11.3 (C); also elsewhere on the board
K5_SET: Q5.3 (C); also elsewhere on the board
K5_SET_SIGNL: PI1.21 (GPIO9_MISO), R11.2
K6_RESET: Q12.3 (C); also elsewhere on the board
K6_SET: Q6.3 (C); also elsewhere on the board
K6_SET_SIGNL: PI1.23 (GPIO11_SCLK), R12.2
K7_RESET: Q25.3 (C); also elsewhere on the board
K7_SET: Q16.3 (C); also elsewhere on the board
K7_SET_SIGNL: PI1.29 (GPIO5), R22.2
K8_RESET: Q26.3 (C); also elsewhere on the board
K8_SET: Q17.3 (C); also elsewhere on the board
K8_SET_SIGNL: PI1.33 (GPIO13), R23.2
K9_RESET: Q27.3 (C); also elsewhere on the board
K9_SET: Q18.3 (C); also elsewhere on the board
K9_SET_SIGNL: PI1.35 (GPIO19), R24.2
K10_RESET: Q28.3 (C); also elsewhere on the board
K10_SET: Q19.3 (C); also elsewhere on the board
K10_SET_SIGNL: PI1.37 (GPIO26), R25.2
K11_RESET: Q29.3 (C); also elsewhere on the board
K11_SET: Q20.3 (C); also elsewhere on the board
K11_SET_SIGNL: PI1.40 (GPIO21), R26.2
K12_RESET: Q30.3 (C); also elsewhere on the board
K12_SET: Q21.3 (C); also elsewhere on the board
K12_SET_SIGNL: PI1.38 (GPIO20), R27.2
K13_RESET: Q31.3 (C); also elsewhere on the board
K13_SET: Q22.3 (C); also elsewhere on the board
K13_SET_SIGNL: PI1.36 (GPIO16), R28.2
K14_RESET: Q32.3 (C); also elsewhere on the board
K14_SET: Q23.3 (C); also elsewhere on the board
K14_SET_SIGNL: PI1.32 (GPIO12), R29.2
K15_RESET: Q33.3 (C); also elsewhere on the board
K15_SET: Q24.3 (C); also elsewhere on the board
K15_SET_SIGNL: PI1.26 (GPIO7_CE1), R30.2
K16_SET_SIGNL: PI1.18 (GPIO24); also elsewhere on the board
K17_SET_SIGNL: PI1.16 (GPIO23); also elsewhere on the board
LTC2057_SHDN: PI1.3 (GPIO2_SDA); also elsewhere on the board
unnamed: Q1.1 (B), R7.1
unnamed: Q2.1 (B), R8.1
unnamed: Q3.1 (B), R9.1
unnamed: Q4.1 (B), R10.1
unnamed: Q5.1 (B), R11.1
unnamed: Q6.1 (B), R12.1
unnamed: Q7.1 (B), R13.1
unnamed: Q8.1 (B), R14.1
unnamed: Q9.1 (B), R15.1
unnamed: Q10.1 (B), R16.1
unnamed: Q11.1 (B), R17.1
unnamed: Q12.1 (B), R18.1
unnamed: Q13.1 (B), R19.1
unnamed: Q14.1 (B), R20.1
unnamed: Q15.1 (B), R21.1
unnamed: Q16.1 (B), R22.1
unnamed: Q17.1 (B), R23.1
unnamed: Q18.1 (B), R24.1
unnamed: Q19.1 (B), R25.1
unnamed: Q20.1 (B), R26.1
unnamed: Q21.1 (B), R27.1
unnamed: Q22.1 (B), R28.1
unnamed: Q23.1 (B), R29.1
unnamed: Q24.1 (B), R30.1
unnamed: Q25.1 (B), R31.1
unnamed: Q26.1 (B), R32.1
unnamed: Q27.1 (B), R33.1
unnamed: Q28.1 (B), R34.1
unnamed: Q29.1 (B), R35.1
unnamed: Q30.1 (B), R36.1
unnamed: Q31.1 (B), R37.1
unnamed: Q32.1 (B), R38.1
unnamed: Q33.1 (B), R39.1
unnamed: R53.1, TP15.1
unnamed: R54.1, TP16.1
PI_GND: C46.2, PI1.6 (GND), PI1.9 (GND), PI1.14 (GND), PI1.20 (GND), PI1.25 (GND), PI1.30 (GND), PI1.34 (GND), PI1.39 (GND), Q1.2 (E), Q2.2 (E), Q3.2 (E), Q4.2 (E), Q5.2 (E), Q6.2 (E), Q7.2 (E), Q8.2 (E), Q9.2 (E), Q10.2 (E), Q11.2 (E), Q12.2 (E), Q16.2 (E), Q17.2 (E), Q18.2 (E), Q19.2 (E), Q20.2 (E), Q21.2 (E), Q22.2 (E), Q23.2 (E), Q24.2 (E), Q25.2 (E), Q26.2 (E), Q27.2 (E), Q28.2 (E), Q29.2 (E), Q30.2 (E), Q31.2 (E), Q32.2 (E), Q33.2 (E); also elsewhere on the board
RES_ARRAY_RESET_SIGNL: PI1.31 (GPIO6), R19.2
RX: PI1.10 (GPIO15_RX), R53.2
TX: PI1.8 (GPIO14_TX), R54.2

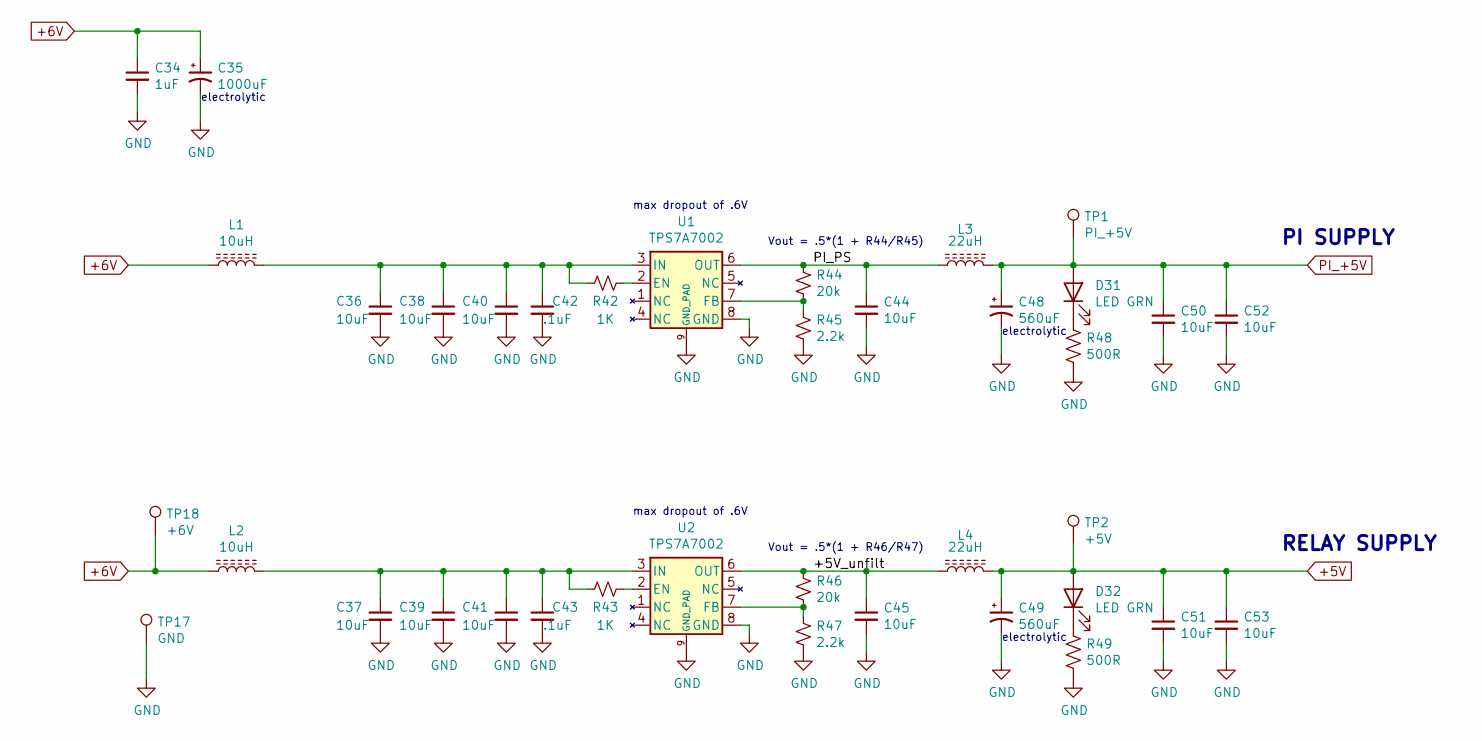
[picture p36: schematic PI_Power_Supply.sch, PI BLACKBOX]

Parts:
C34: 1uF; C_0603_1608Metric_Pad1.05x0.95mm_HandSolder
C35: 1000uF; CP_Radial_D12.5mm_P5.00mm; MFG Part # EEU-FR1V102B
C36, C37, C38, C39, C40, C41, C44, C45, C50, C51, C52, C53: 10uF; C_1206_3216Metric_Pad1.42x1.75mm_HandSolder
C42, C43: .1uF; C_0603_1608Metric_Pad1.05x0.95mm_HandSolder
C48, C49: 560uF; CP_Radial_D10.0mm_P5.00mm
D10, D32: LED GRN; LED_0805_2012Metric_Pad1.15x1.40mm_HandSolder
L2, L9: 10uH; 10uH_Wurth_74479887310A
L4, L8: 22uH; Sumida_CDRH105
R42, R43: 1K; R_0402_1005Metric
R44, R46: 20k; R_0603_1608Metric_Pad1.05x0.95mm_HandSolder
R45, R47: 2.2k; R_0603_1608Metric_Pad1.05x0.95mm_HandSolder
R49, R80: 500R; R_0402_1005Metric
TP1: PI_+5V; TestPoint_Pad_D1.5mm
TP2: +5V; TestPoint_Pad_D1.0mm
TP17: GND; TestPoint_THTPad_D3.0mm_Drill1.5mm
TP18: +6V; TestPoint_THTPad_D3.0mm_Drill1.5mm
U1, U2: TPS7A7002; SOIC-8-1EP_3.9x4.9mm_P1.27mm_EP2.514x3.2mm_ThermalVias

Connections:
+6V: C34.1, C35.1, L2.1, TP18.1; also elsewhere on the board
/PI_Power_Supply/+5V_unfilt: C45.1, L4.1, R46.1, U2.6 (OUT)
/PI_Power_Supply/PI_PS: C44.1, R44.1, U1.6 (OUT); also elsewhere on the board
unnamed 83: C36.1, C38.1, C40.1, C42.1, R42.2, U1.3 (IN); also elsewhere on the board
unnamed: C37.1, C39.1, C41.1, C43.1, L2.2, R43.2, U2.3 (IN)
unnamed: D32.1 (K), R49.1
unnamed: R42.1, U1.2 (EN)
unnamed: R43.1, U2.2 (EN)
unnamed: R44.2, R45.1, U1.7 (FB)
unnamed: R46.2, R47.1, U2.7 (FB)
PI_GND: C34.2, C35.2, C36.2, C37.2, C38.2, C39.2, C40.2, C41.2, C42.2, C43.2, C44.2, C45.2, C48.2, C49.2, C50.2, C51.2, C52.2, C53.2, R45.2, R47.2, R49.2, TP17.1, U1.8 (GND), U1.9 (GND_PAD), U2.8 (GND), U2.9 (GND_PAD); also elsewhere on the board

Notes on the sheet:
Vout = .5*(1 + R44/R45)
PI SUPPLY
max dropout of .6V
electrolytic
Vout = .5*(1 + R46/R47)
RELAY SUPPLY

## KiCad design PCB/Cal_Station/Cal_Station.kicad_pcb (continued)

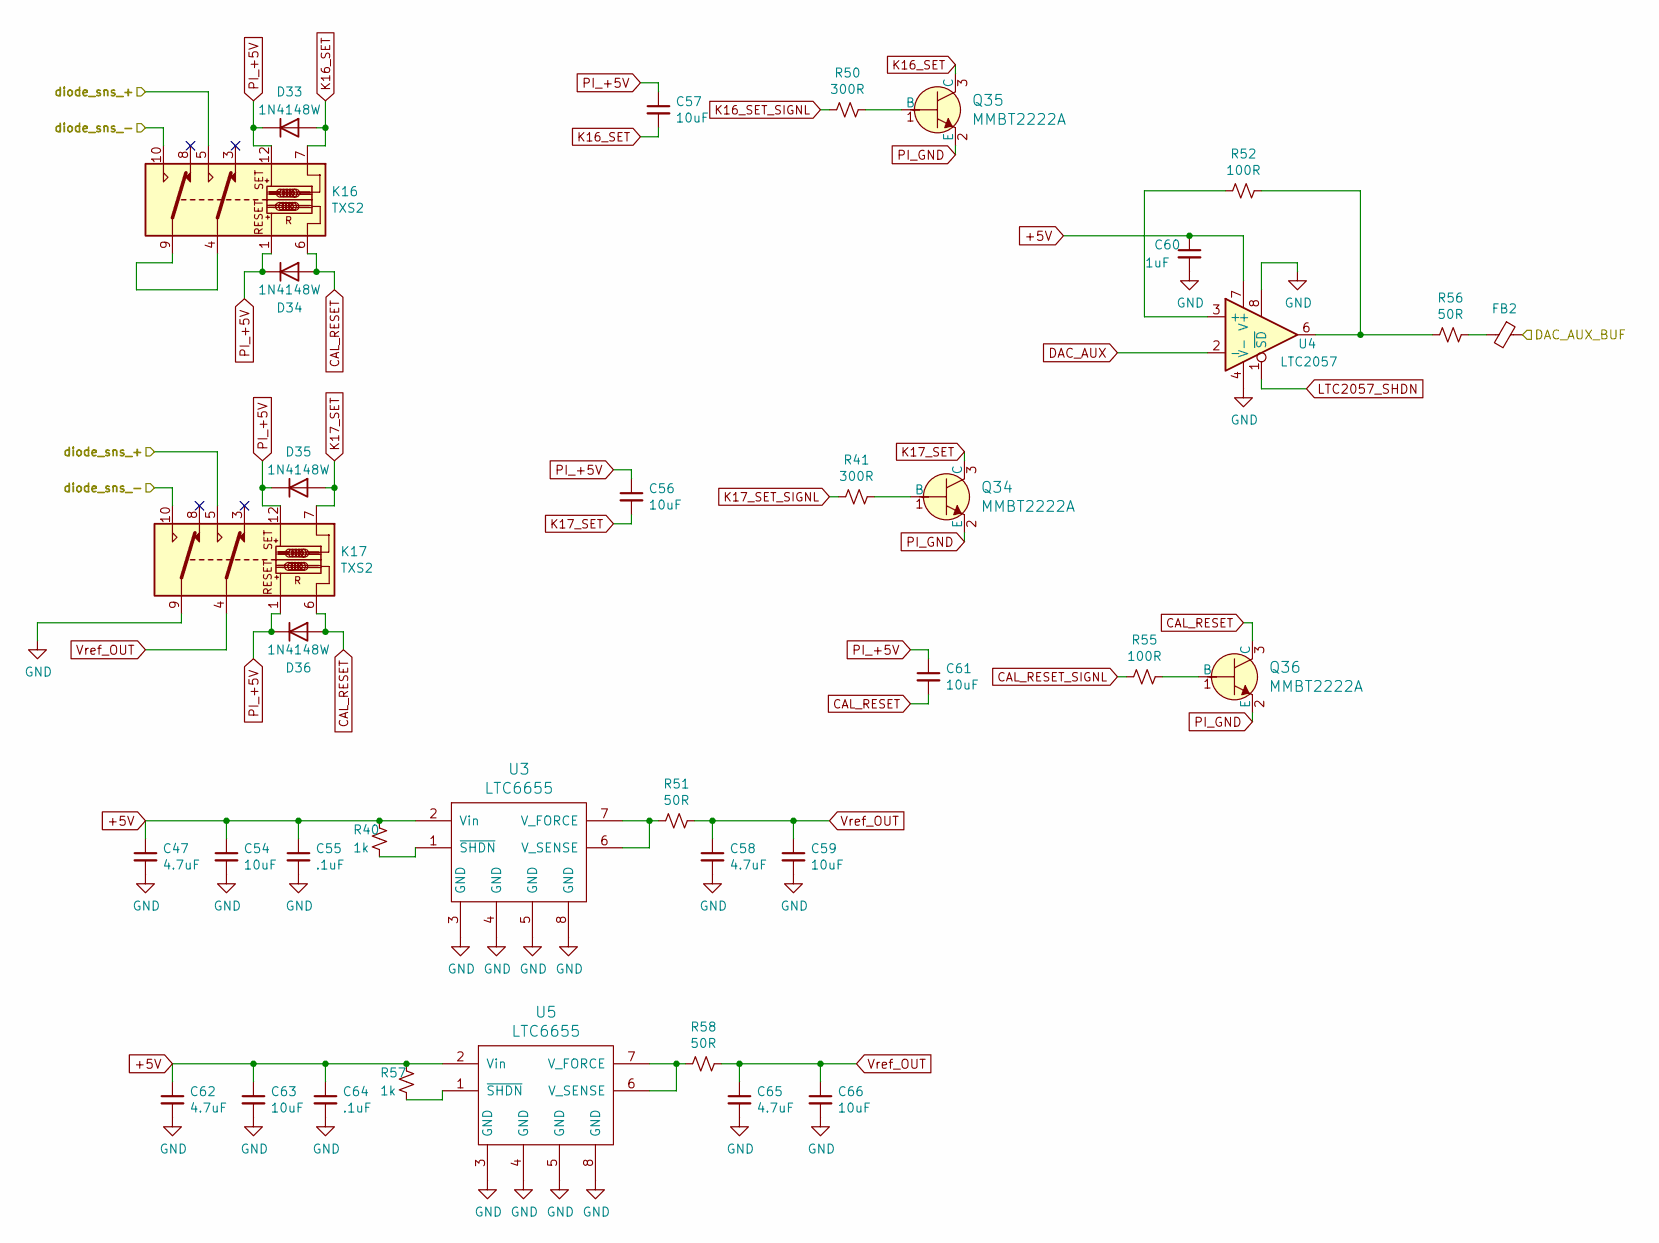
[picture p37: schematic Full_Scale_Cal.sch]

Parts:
C47, C58, C62, C65: 4.7uF; CP_EIA-3528-21_Kemet-B_Pad1.50x2.35mm_HandSolder
C54, C56, C57, C59, C61, C63, C66: 10uF; C_0805_2012Metric_Pad1.15x1.40mm_HandSolder
C55, C64: .1uF; C_0603_1608Metric_Pad1.05x0.95mm_HandSolder
C60: 1uF; C_0805_2012Metric_Pad1.15x1.40mm_HandSolder
D33, D34, D35, D36: 1N4148W; D_SOD-123
FB2: Ferrite_Bead_Small; L_0805_2012Metric_Pad1.15x1.40mm_HandSolder
K16, K17: TXS2; Panasonic_TX2_2
Q34, Q35, Q36: MMBT2222A; SOT-23-3; MPN MMBT2222A-7-F; Digi-Key_PN MMBT2222A-FDICT-ND
R40, R57: 1k; C_0402_1005Metric
R41, R50: 300R; C_0402_1005Metric
R51, R56, R58: 50R; C_0402_1005Metric
R52, R55: 100R; C_0402_1005Metric
U3, U5: LTC6655; LTC6655_LS8
U4: LTC2057; SO-8_3.9x4.9mm_P1.27mm

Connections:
/34401_A/GNDA: K16.10, K17.10; also elsewhere on the board
CAL_RESET: C61.2, D34.2 (A), D36.2 (A), K16.6, K17.6, Q36.3 (C)
CAL_RESET_SIGNL: R55.2; also elsewhere on the board
DAC_AUX: U4.2 (-); also elsewhere on the board
DAC_AUX_BUF: FB2.1, K16.5, K17.5; also elsewhere on the board
K16_SET: C57.2, D33.2 (A), K16.7, Q35.3 (C)
K16_SET_SIGNL: R50.2; also elsewhere on the board
K17_SET: C56.2, D35.2 (A), K17.7, Q34.3 (C)
K17_SET_SIGNL: R41.2; also elsewhere on the board
LTC2057_SHDN: U4.1 (~SD); also elsewhere on the board
unnamed: FB2.2, R56.1
unnamed: K16.4, K16.9
unnamed: Q34.1 (B), R41.1
unnamed: Q35.1 (B), R50.1
unnamed: Q36.1 (B), R55.1
unnamed: R40.2, U3.1 (~SHDN)
unnamed: R51.2, U3.6 (V_SENSE), U3.7 (V_FORCE)
unnamed: R52.1, R56.2, U4.6
unnamed: R52.2, U4.3 (+)
unnamed: R57.2, U5.1 (~SHDN)
unnamed: R58.2, U5.6 (V_SENSE), U5.7 (V_FORCE)
PI_GND: C47.2, C54.2, C55.2, C58.2, C59.2, C60.2, C62.2, C63.2, C64.2, C65.2, C66.2, K17.9, Q34.2 (E), Q35.2 (E), Q36.2 (E), U3.3 (GND), U3.4 (GND), U3.5 (GND), U3.8 (GND), U4.4 (V-), U4.8, U5.3 (GND), U5.4 (GND), U5.5 (GND), U5.8 (GND); also elsewhere on the board
Vref_OUT: C58.1, C59.1, C65.1, C66.1, K17.4, R51.1, R58.1

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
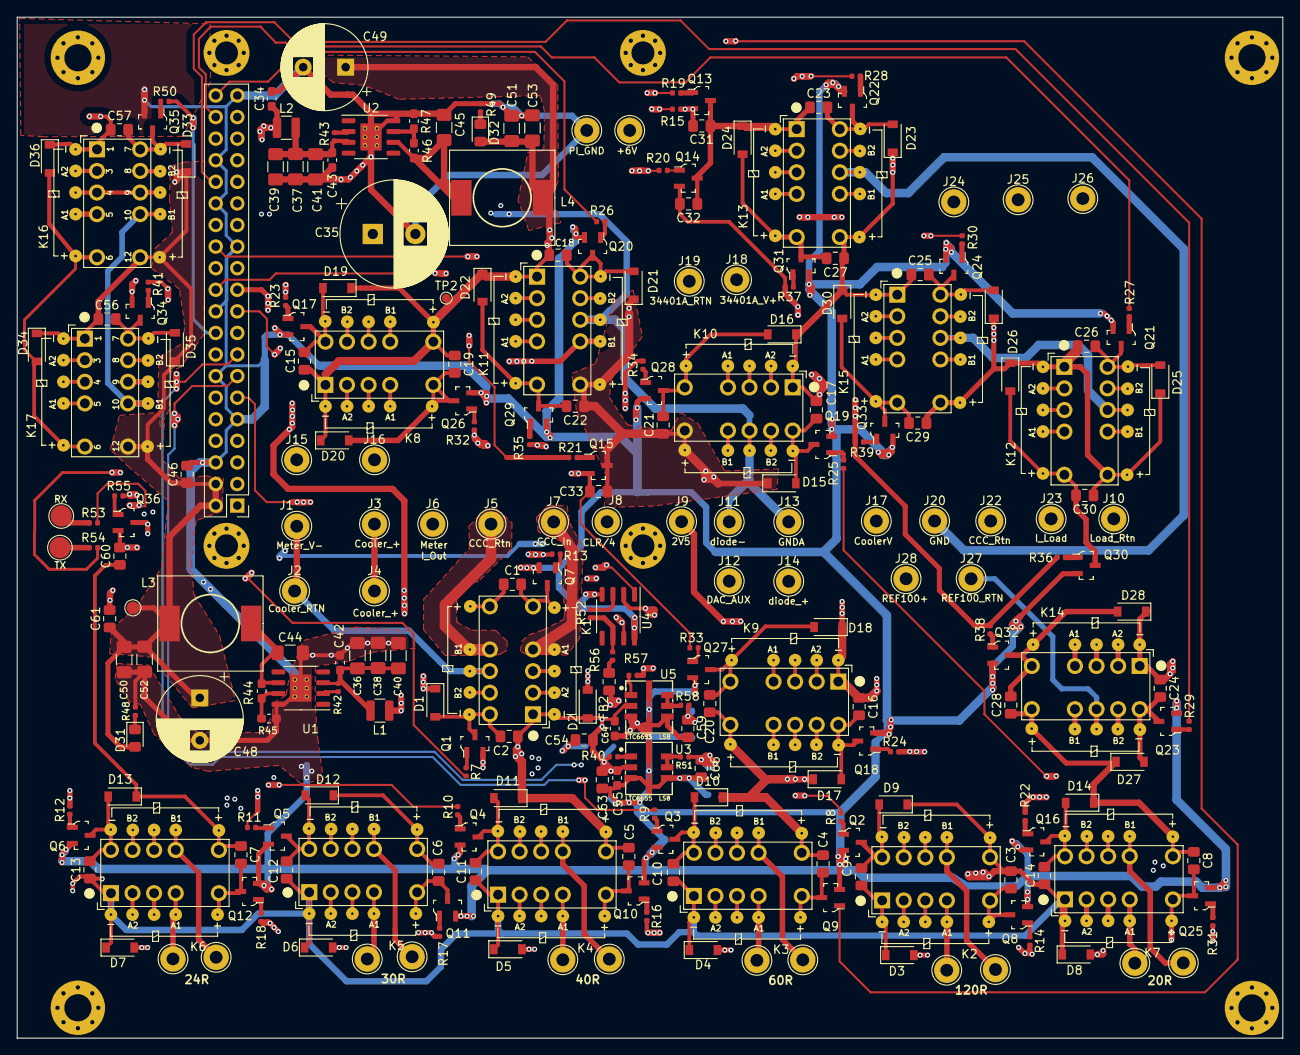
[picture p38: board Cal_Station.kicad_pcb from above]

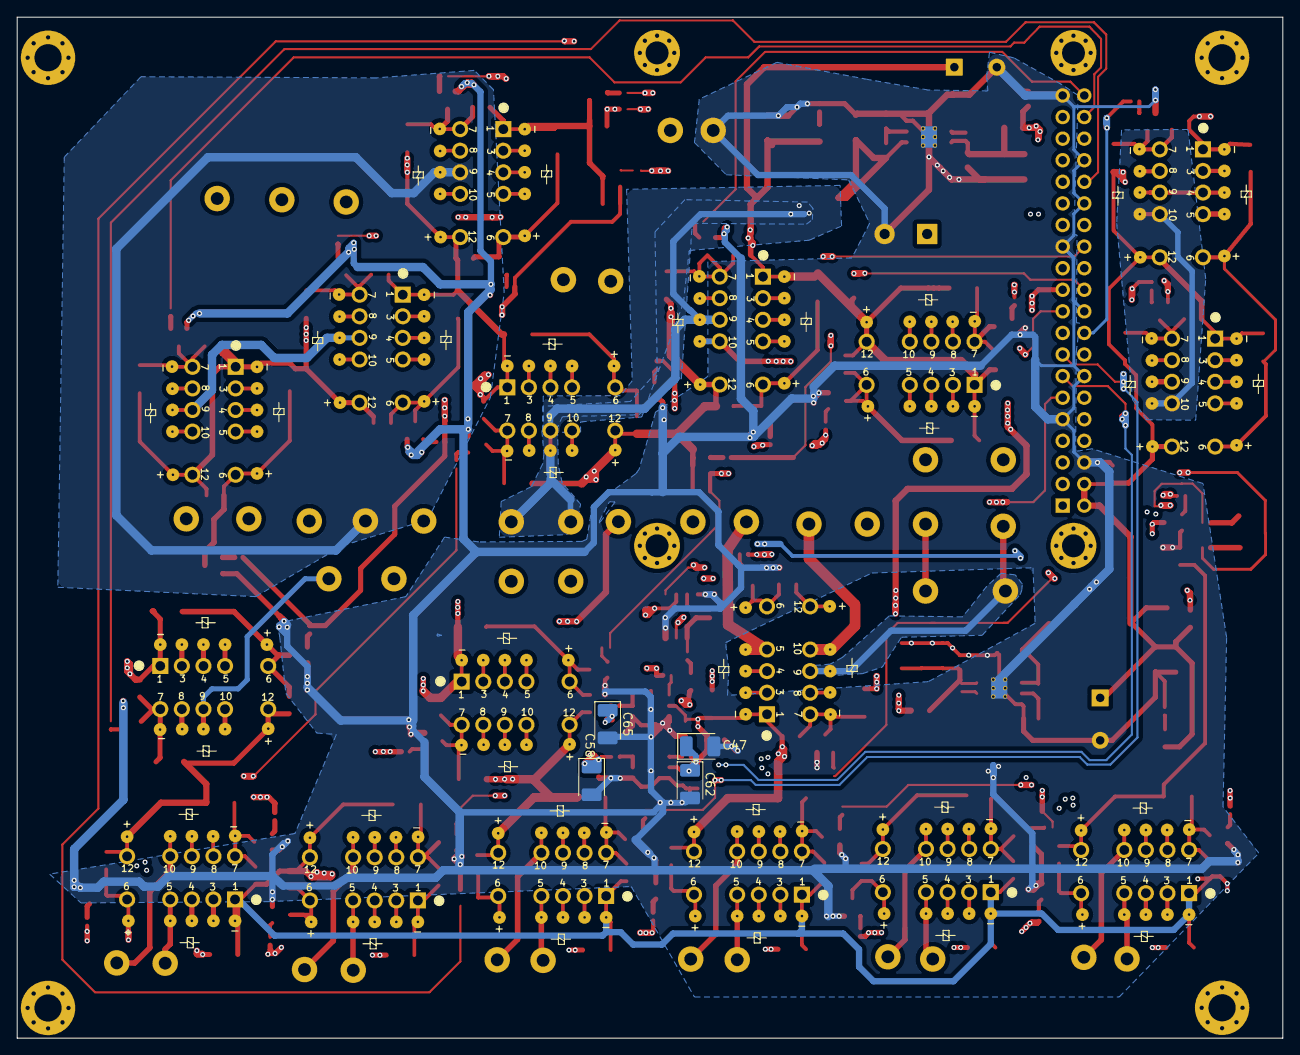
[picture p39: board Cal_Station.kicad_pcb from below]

Board: 4 copper layers, 148.9 x 120.1 mm, 271 parts (4 on the bottom side), 160 nets.

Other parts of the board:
D31: LED GRN; LED_0805_2012Metric_Pad1.15x1.40mm_HandSolder
L1: 10uH; 10uH_Wurth_74479887310A
L3: 22uH; Sumida_CDRH105
R48: 500R; R_0402_1005Metric

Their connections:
+6V: L1.1; also elsewhere on the board
/PI_Power_Supply/PI_PS: L3.1; also elsewhere on the board
unnamed 83: L1.2; also elsewhere on the board
PI_GND: R48.2; also elsewhere on the board

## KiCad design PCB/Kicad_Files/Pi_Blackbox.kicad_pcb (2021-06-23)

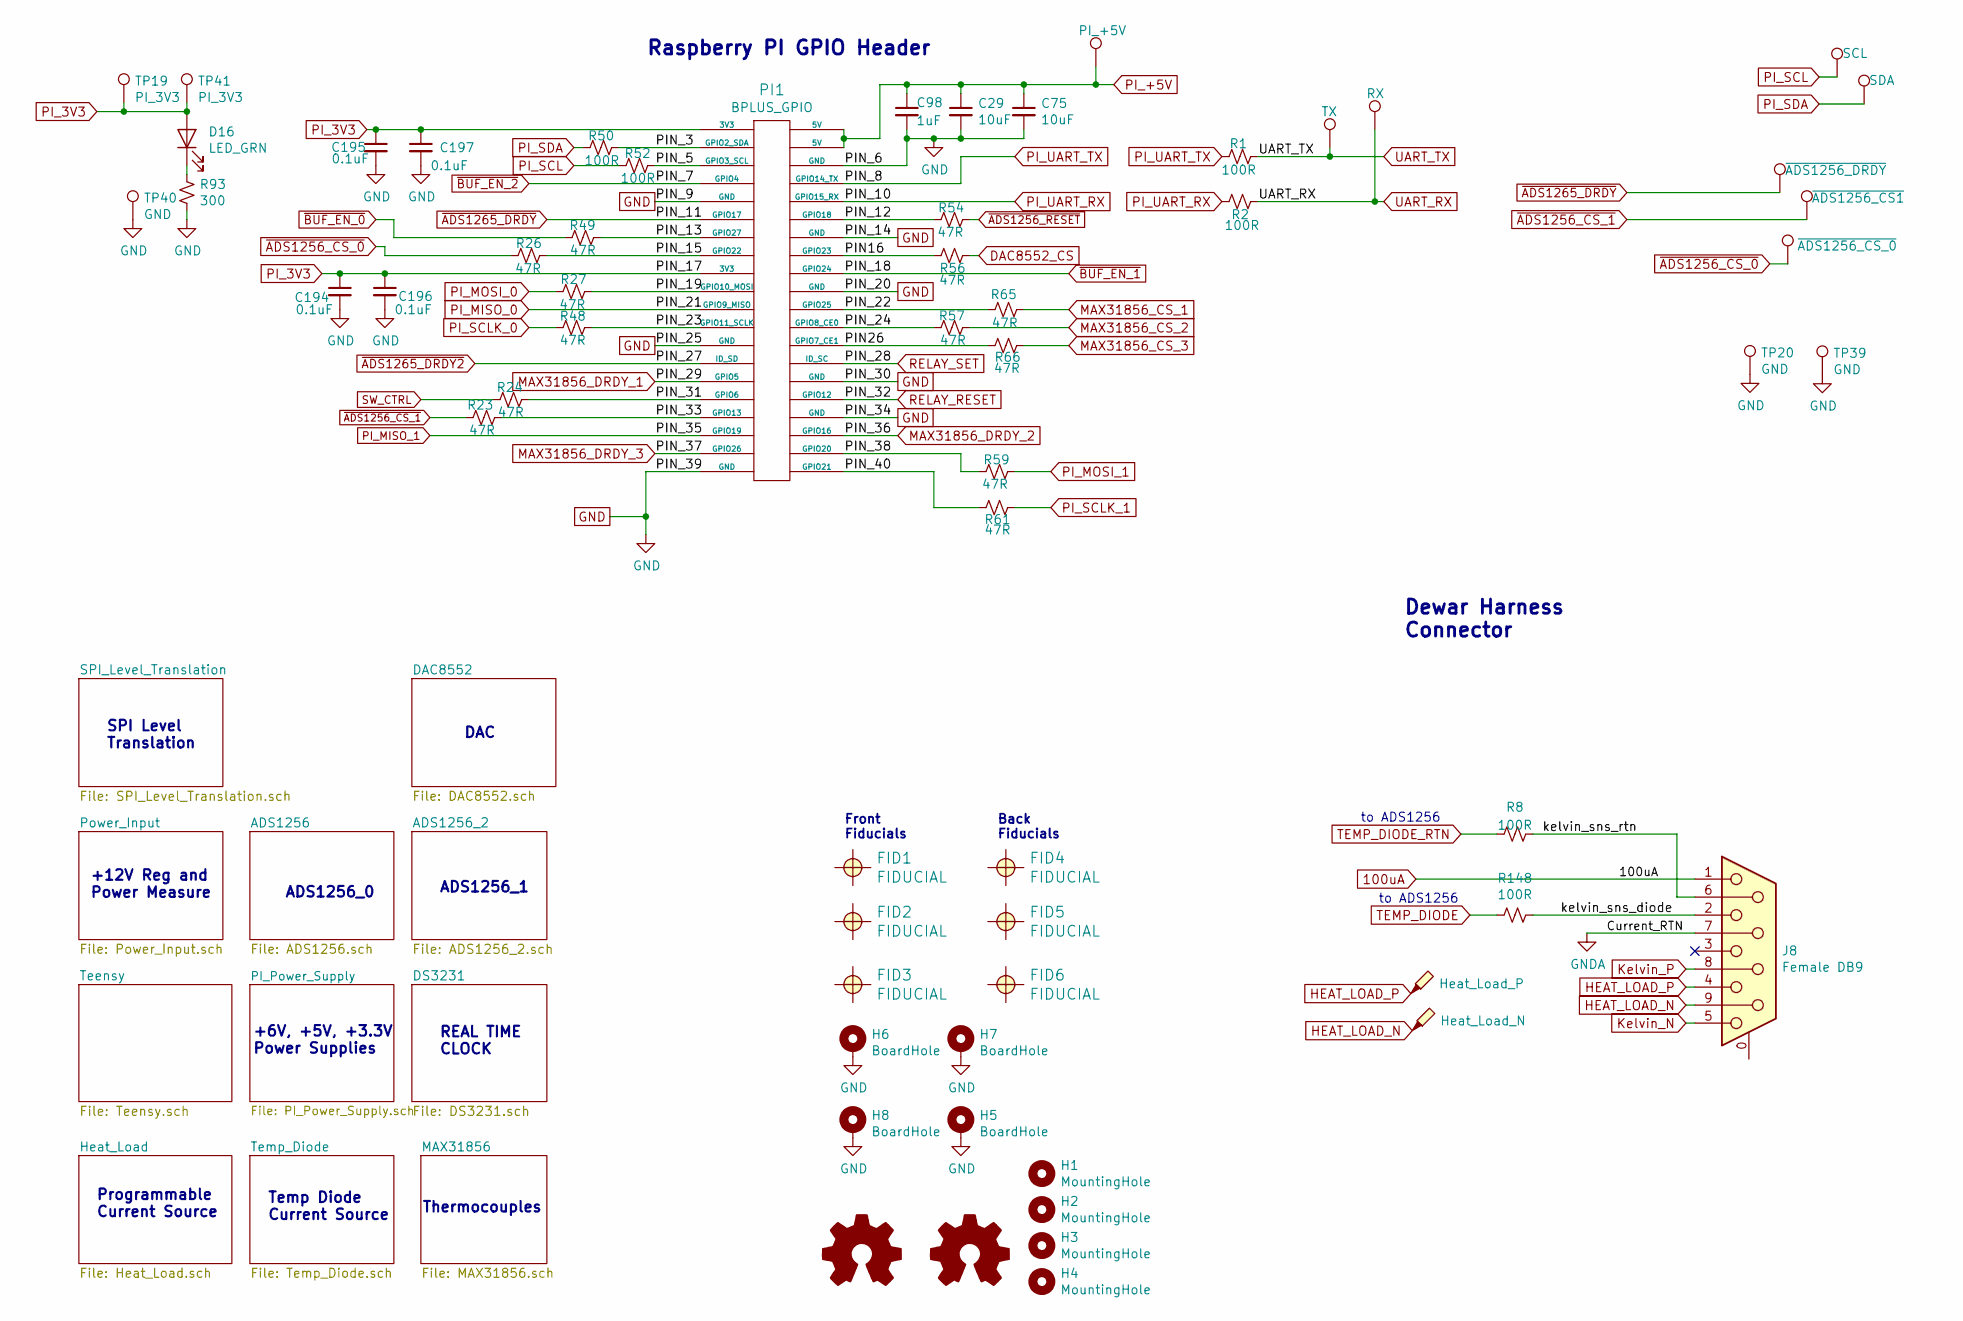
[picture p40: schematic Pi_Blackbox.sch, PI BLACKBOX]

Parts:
C29, C75: 10uF; C_1206_3216Metric_Pad1.42x1.75mm_HandSolder
C98: 1uF; C_0603_1608Metric_Pad1.05x0.95mm_HandSolder
C194, C195, C196, C197: 0.1uF; C_0603_1608Metric_Pad1.05x0.95mm_HandSolder
D16: LED_GRN; LED_0805_2012Metric_Pad1.15x1.40mm_HandSolder
FID1, FID2, FID4, FID5: FIDUCIAL; Fiducial_0.5mm_Mask1.5mm
FID3: FIDUCIAL; Fiducial_1.5mm_Mask3mm
FID6: FIDUCIAL; Fiducial_0.75mm_Mask2.25mm
H1, H2, H3, H4: MountingHole; MountingHole_3.5mm_Pad_Via
H5, H6, H7, H8: BoardHole; MountingHole_2.7mm_M2.5_Pad_Via
J8: Female DB9; DB9_D09S13A4GX00LF
PI1: BPLUS_GPIO; PinHeader_2x20_P2.54mm_Vertical
R1, R2, R8, R50, R52, R148: 100R; R_0402_1005Metric
R23, R24, R26, R27, R48, R49, R54, R56, R57, R59, R61, R65, R66: 47R; R_0402_1005Metric
R93: 300; R_0402_1005Metric
TP1: TX; TestPoint_Pad_D2.0mm
TP2: RX; TestPoint_Pad_D2.0mm
TP3: SCL; TestPoint_SMT_Keystone_5190
TP4: ~ADS1256_CS_0; TestPoint_SMT_Keystone_5190
TP6: SDA; TestPoint_SMT_Keystone_5190
TP13: Heat_Load_P; TestPoint_SMT_Keystone_5190
TP14: ~ADS1256_DRDY; TestPoint_SMT_Keystone_5190
TP15: ~ADS1256_CS1; TestPoint_SMT_Keystone_5190
TP19: PI_3V3; TestPoint_SMT_Keystone_5190
TP20: GND; TestPoint_Keystone_5000-5004_Miniature
TP39: GND; TestPoint_Pad_D2.0mm
TP40: GND; TestPoint_SMT_Keystone_5190
TP41: PI_3V3; TestPoint_Pad_D2.0mm
TP42: PI_+5V; TestPoint_Pad_D2.0mm
TP43: Heat_Load_N; TestPoint_SMT_Keystone_5190

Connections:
100uA: J8.1; also elsewhere on the board
/PIN16: PI1.16 (GPIO23), R56.2
/PIN26: PI1.26 (GPIO7_CE1), R66.2
/PIN_3: PI1.3 (GPIO2_SDA), R50.1
/PIN_5: PI1.5 (GPIO3_SCL), R52.1
/PIN_12: PI1.12 (GPIO18), R54.2
/PIN_13: PI1.13 (GPIO27), R49.1
/PIN_15: PI1.15 (GPIO22), R26.1
/PIN_19: PI1.19 (GPIO10_MOSI), R27.1
/PIN_22: PI1.22 (GPIO25), R65.2
/PIN_23: PI1.23 (GPIO11_SCLK), R48.1
/PIN_24: PI1.24 (GPIO8_CE0), R57.2
/PIN_31: PI1.31 (GPIO6), R24.1
/PIN_33: PI1.33 (GPIO13), R23.1
/PIN_38: PI1.38 (GPIO20), R59.2
/PIN_40: PI1.40 (GPIO21), R61.2
/kelvin_sns_diode: J8.2, R148.1
/kelvin_sns_rtn: J8.6, R8.1
DAC8552_CS: R56.1; also elsewhere on the board
GND: C29.2, C75.2, C98.2, C194.2, C195.2, C196.2, C197.2, H5.PAD, H6.PAD, H7.PAD, H8.PAD, J8.5, J8.9, PI1.6 (GND), PI1.9 (GND), PI1.14 (GND), PI1.20 (GND), PI1.25 (GND), PI1.30 (GND), PI1.34 (GND), PI1.39 (GND), R93.2, TP20.1, TP39.1, TP40.1, TP43.1; also elsewhere on the board
GNDA: J8.7; also elsewhere on the board
HEAT_LOAD_P: J8.4, J8.8, TP13.1; also elsewhere on the board
MAX31856_CS_1: R65.1; also elsewhere on the board
MAX31856_CS_2: R57.1; also elsewhere on the board
MAX31856_CS_3: R66.1; also elsewhere on the board
MAX31856_DRDY_1: PI1.29 (GPIO5); also elsewhere on the board
MAX31856_DRDY_2: PI1.36 (GPIO16); also elsewhere on the board
MAX31856_DRDY_3: PI1.37 (GPIO26); also elsewhere on the board
unnamed: D16.1 (K), R93.1
PI_3V3: C194.1, C195.1, C196.1, C197.1, D16.2 (A), PI1.1 (3V3), PI1.17 (3V3), TP19.1, TP41.1
PI_+5V: C29.1, C75.1, C98.1, PI1.2 (5V), PI1.4 (5V), TP42.1; also elsewhere on the board
PI_MISO_0: PI1.21 (GPIO9_MISO); also elsewhere on the board
PI_MISO_1: PI1.35 (GPIO19); also elsewhere on the board
PI_MOSI_0: R27.2; also elsewhere on the board
PI_MOSI_1: R59.1; also elsewhere on the board
PI_SCL: R52.2, TP3.1; also elsewhere on the board
PI_SCLK_0: R48.2; also elsewhere on the board
PI_SCLK_1: R61.1; also elsewhere on the board
PI_SDA: R50.2, TP6.1; also elsewhere on the board
PI_UART_RX: PI1.10 (GPIO15_RX), R2.2; also elsewhere on the board
PI_UART_TX: PI1.8 (GPIO14_TX), R1.2; also elsewhere on the board
RELAY_RESET: PI1.32 (GPIO12); also elsewhere on the board
RELAY_SET: PI1.28 (ID_SC); also elsewhere on the board
SW_CTRL: R24.2; also elsewhere on the board
TEMP_DIODE: R148.2; also elsewhere on the board
TEMP_DIODE_RTN: R8.2; also elsewhere on the board
UART_RX: R2.1, TP2.1
UART_TX: R1.1, TP1.1
~ADS1256_CS_0: R26.2, TP4.1; also elsewhere on the board
~ADS1256_CS_1: R23.2, TP15.1; also elsewhere on the board
~ADS1256_RESET: R54.1; also elsewhere on the board
~ADS1265_DRDY: PI1.11 (GPIO17), TP14.1; also elsewhere on the board
~ADS1265_DRDY2: PI1.27 (ID_SD); also elsewhere on the board
~BUF_EN_0: R49.2; also elsewhere on the board
~BUF_EN_1: PI1.18 (GPIO24); also elsewhere on the board
~BUF_EN_2: PI1.7 (GPIO4); also elsewhere on the board

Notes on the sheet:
Raspberry PI GPIO Header
REAL TIME CLOCK
to ADS1256
Dewar Harness Connector
Programmable Current Source
Thermocouples
DAC
ADS1256_0
ADS1256_1
+6V, +5V, +3.3V Power Supplies
Temp Diode Current Source
SPI Level Translation
+12V Reg and Power Measure
Front Fiducials
Back Fiducials

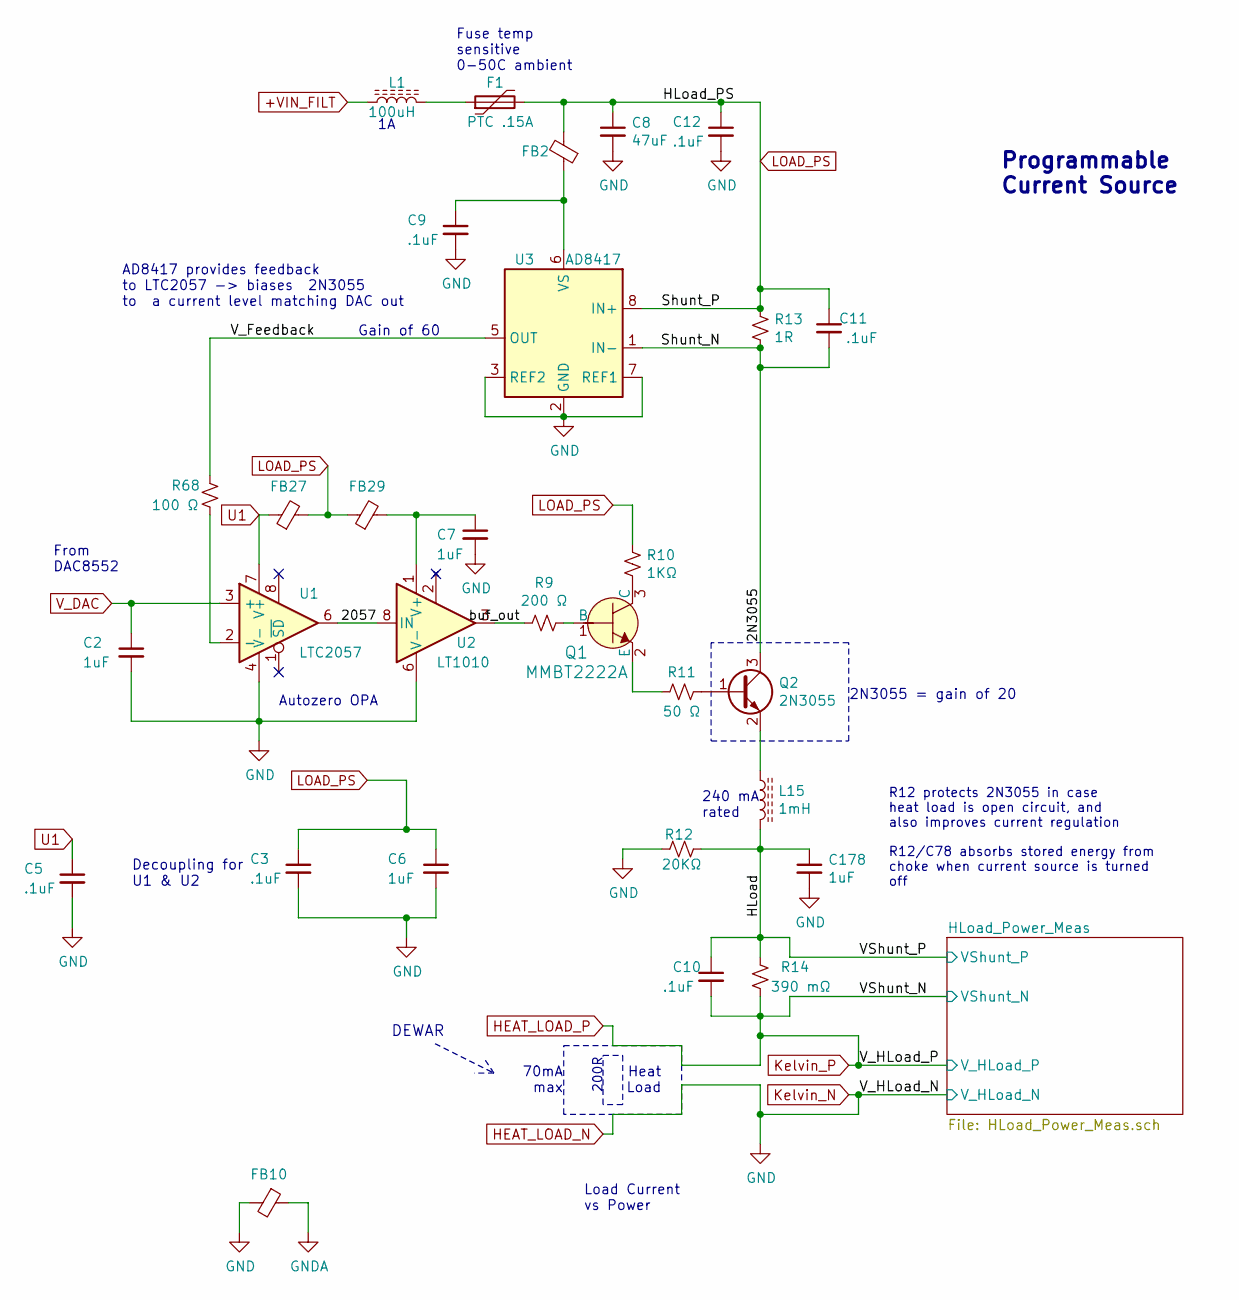
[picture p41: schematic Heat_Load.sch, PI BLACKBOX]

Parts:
C2, C6, C7, C178: 1uF; C_0805_2012Metric_Pad1.15x1.40mm_HandSolder
C3, C5, C9, C10, C12: .1uF; C_0603_1608Metric_Pad1.05x0.95mm_HandSolder
C8: 47uF; T495X476K035ATE300
C11: .1uF; C_0805_2012Metric_Pad1.15x1.40mm_HandSolder
F1: PTC .15A; R_1812_4532Metric_Pad1.30x3.40mm_HandSolder
FB2: FB; L_0603_1608Metric_Pad1.05x0.95mm_HandSolder
FB10: FB; L_1210_3225Metric_Pad1.42x2.65mm_HandSolder
FB27, FB29: Ferrite; C_0603_1608Metric_Pad1.05x0.95mm_HandSolder
L1: 100uH; L_Wuerth_WE-PD-Typ-LS_Handsoldering
L15: 1mH; RLB9012-222KL
Q1: MMBT2222A; SOT-23_Handsoldering; MPN MMBT2222A-7-F; Digi-Key_PN MMBT2222A-FDICT-ND
Q2: 2N3055; TO-3
R9: 200 Ω; R_0603_1608Metric_Pad1.05x0.95mm_HandSolder
R10: 1KΩ; R_0603_1608Metric_Pad1.05x0.95mm_HandSolder
R11: 50 Ω; R_0603_1608Metric_Pad1.05x0.95mm_HandSolder
R12: 20KΩ; R_0603_1608Metric_Pad1.05x0.95mm_HandSolder
R13: 1R; R_1206_3216Metric_Pad1.42x1.75mm_HandSolder
R14: 390 mΩ; R_1206_3216Metric_Pad1.42x1.75mm_HandSolder
R68: 100 Ω; R_0402_1005Metric
U1: LTC2057; SOIC-8_3.9x4.9mm_P1.27mm
U2: LT1010; DIP-8_W7.62mm_LongPads
U3: AD8417; SOIC-8_3.9x4.9mm_P1.27mm

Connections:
+VIN_FILT: L1.1; also elsewhere on the board
/Heat_Load/2N3055: C11.2, Q2.3 (C), R13.2, U3.1 (IN-)
/Heat_Load/2057: U1.6, U2.8 (IN)
/Heat_Load/HLoad: C10.1, C178.1, L15.2, R12.1, R14.1; also elsewhere on the board
/Heat_Load/V_Feedback: R68.2, U3.5 (OUT)
/Heat_Load/buf_out: R9.2, U2.3
GND: C2.2, C3.2, C5.2, C6.2, C7.2, C8.2, C9.2, C12.2, C178.2, FB10.2, R12.2, U1.4 (V-), U2.6 (V-), U3.2 (GND), U3.3 (REF2), U3.7 (REF1); also elsewhere on the board
GNDA: FB10.1; also elsewhere on the board
HEAT_LOAD_P: C10.2, R14.2; also elsewhere on the board
LOAD_PS: C3.1, C6.1, C8.1, C11.1, C12.1, F1.2, FB2.2, FB27.2, FB29.1, R10.1, R13.1, U3.8 (IN+); also elsewhere on the board
unnamed: C7.1, FB29.2, U2.1 (V+)
unnamed: C9.1, FB2.1, U3.6 (VS)
unnamed: F1.1, L1.2
unnamed: L15.1, Q2.2 (E)
unnamed: Q1.1 (B), R9.1
unnamed: Q1.2 (E), R11.2
unnamed: Q1.3 (C), R10.2
unnamed: Q2.1 (B), R11.1
unnamed: R68.1, U1.2 (-)
U1: C5.1, FB27.1, U1.7 (V+)
V_DAC: C2.1, U1.3 (+); also elsewhere on the board

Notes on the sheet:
Heat Load
From DAC8552
Autozero OPA
AD8417 provides feedback to LTC2057 -> biases 2N3055 to a current level matching DAC out
70mA max
Fuse temp sensitive 0-50C ambient
200R
Programmable Current Source
Load Current vs Power
Decoupling for U1 & U2
DEWAR
2N3055 = gain of 20
Gain of 60
240 mA rated
R12 protects 2N3055 in case heat load is open circuit, and also improves current regulation
R12/C78 absorbs stored energy from choke when current source is turned off

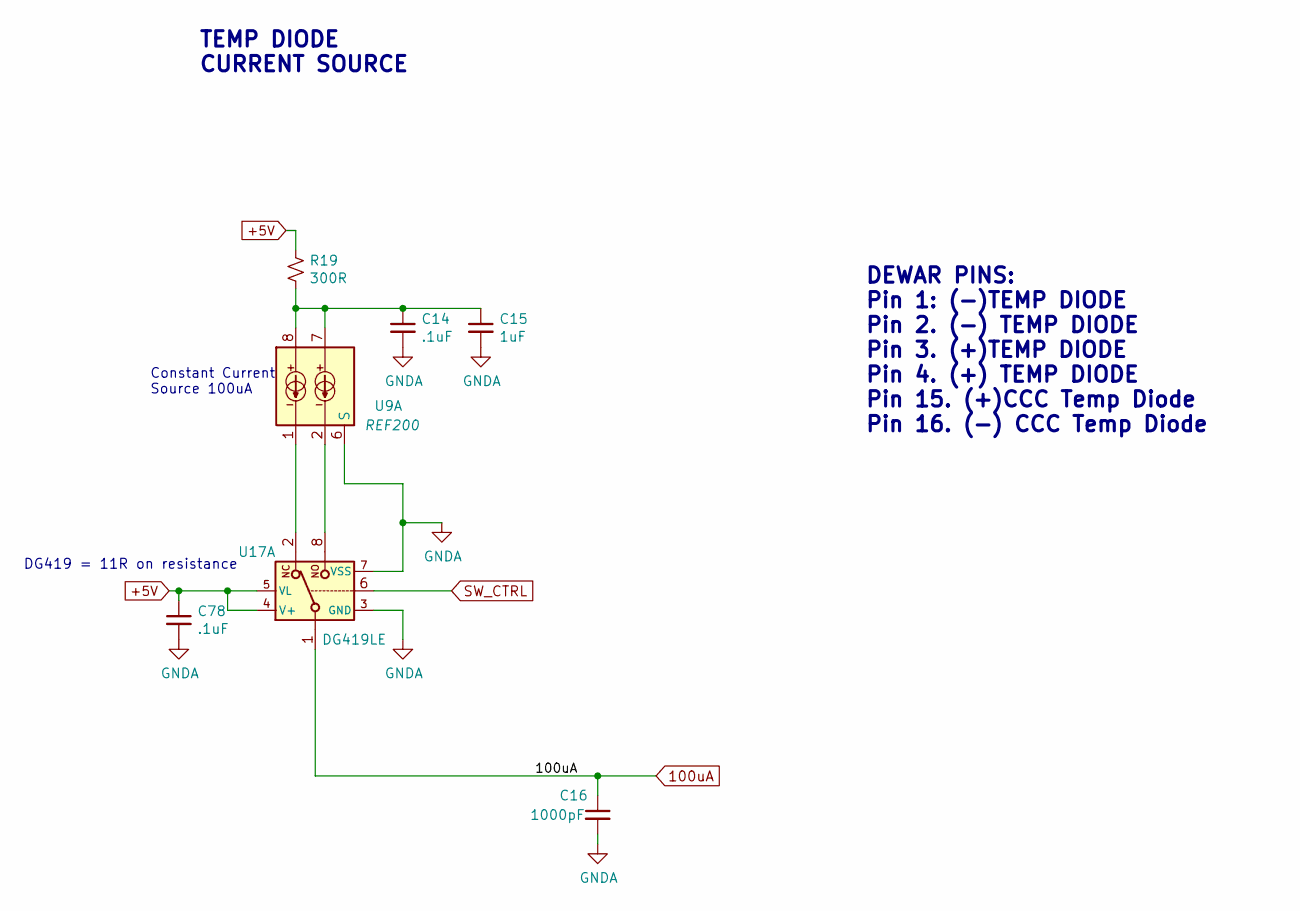
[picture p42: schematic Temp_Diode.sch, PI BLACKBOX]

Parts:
C14, C78: .1uF; C_0603_1608Metric_Pad1.05x0.95mm_HandSolder
C15: 1uF; C_0805_2012Metric_Pad1.15x1.40mm_HandSolder
C16: 1000pF; C_0402_1005Metric
R19: 300R; R_0603_1608Metric_Pad1.05x0.95mm_HandSolder
U9: REF200; SOIC-8_3.9x4.9mm_P1.27mm
U17: DG419LE; MSOP-8_3x3mm_P0.65mm

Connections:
100uA: C16.1, U17.1; also elsewhere on the board
+5V: C78.1, R19.1, U17.4 (V+), U17.5 (VL); also elsewhere on the board
GNDA: C14.2, C15.2, C16.2, C78.2, U9.6 (S), U17.3 (GND), U17.7 (V-); also elsewhere on the board
unnamed: C14.1, C15.1, R19.2, U9.7, U9.8
unnamed: U9.1, U17.2
unnamed: U9.2, U17.8
SW_CTRL: U17.6; also elsewhere on the board

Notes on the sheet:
Constant Current Source 100uA
TEMP DIODE CURRENT SOURCE
DG419 = 11R on resistance
DEWAR PINS: Pin 1: (-)TEMP DIODE Pin 2. (-) TEMP DIODE Pin 3. (+)TEMP DIODE Pin 4. (+) TEMP DIODE Pin 15. (+)CCC Temp Diode Pin 16. (-) CCC Temp Diode


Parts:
C17: 4.7uF; CP_EIA-3528-21_Kemet-B_Pad1.50x2.35mm_HandSolder
C18, C20, C55, C81, C89, C104: 1uF; C_0805_2012Metric_Pad1.15x1.40mm_HandSolder
C19, C90, C105, C106: .1uF; C_0603_1608Metric_Pad1.05x0.95mm_HandSolder
C21, C22, C83: .1uF; R_0603_1608Metric_Pad1.05x0.95mm_HandSolder
C23: 1uF; C_0603_1608Metric_Pad1.05x0.95mm_HandSolder
C24, C25: 20pF; C_0603_1608Metric_Pad1.05x0.95mm_HandSolder
C91, C96, C97: 1uF; C_1210_3225Metric_Pad1.42x2.65mm_HandSolder
FB1, FB12: FB; R_0805_2012Metric_Pad1.15x1.40mm_HandSolder
FB13: FB; L_1210_3225Metric_Pad1.42x2.65mm_HandSolder
FB20: FB; L_0805_2012Metric_Pad1.15x1.40mm_HandSolder
L2, L7: 10uH; L_1210_3225Metric_Pad1.42x2.65mm_HandSolder
R22, R118: 2k; R_0402_1005Metric
R25: 10k; R_0402_1005Metric
R28, R29: 47R; R_0402_1005Metric
R31, R34: 2K; R_0402_1005Metric
R89, R91: 22R; R_0402_1005Metric
R105, R110: 10K; R_0402_1005Metric
TP17: LOAD_I; TestPoint_SMT_Keystone_5190
TP18: LOAD_V; TestPoint_SMT_Keystone_5190
TP22: I_Avg; TestPoint_SMT_Keystone_5190
TP31: CLR_V; TestPoint_SMT_Keystone_5190
TP33: Temp_Diode; TestPoint_SMT_Keystone_5190
TP38: Diode_RTN; TestPoint_SMT_Keystone_5190
U6: ADS1256; SSOP-28_5.3x10.2mm_P0.65mm
U20: ADT7410; SOIC-8_3.9x4.9mm_P1.27mm
Y1: 7.68 Mhz; Crystal_SMD_TXC

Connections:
+2V5_VREF: C17.1, C18.1, C19.1, U6.4 (VREFP); also elsewhere on the board
+3.3V: C81.1, FB20.2, L2.1, R22.1, R25.1, R31.1, R34.1, R105.2, R110.2, R118.1; also elsewhere on the board
+5V: C83.1, L7.1; also elsewhere on the board
/ADS1256/ADS1256_PS: C20.1, FB1.1, L2.2
/ADS1256/ADS_DRDY: R28.2, U6.21 (~DRDY)
/ADS1256/ADS_MISO: R29.2, U6.22 (DOUT)
/ADS1256/AVDD: C105.1, C106.1, FB12.2, U6.1 (AVDD)
/ADS1256/DVDD: C21.1, C22.1, FB1.2, U6.16 (DVDD)
ADS1256_MISO: R29.1; also elsewhere on the board
ADS1256_MOSI: U6.23 (DIN); also elsewhere on the board
ADS1256_SCLK: U6.24 (SCLK); also elsewhere on the board
COOL_PWR_I: C96.1, TP22.1, U6.6 (AIN0); also elsewhere on the board
COOL_PWR_V: C97.1, TP31.1, U6.8 (AIN2); also elsewhere on the board
CRYSTAL1: C24.1, U6.19 (XTAL1/CLKIN), Y1.2
CRYSTAL2: C25.1, U6.18 (XTAL2), Y1.1
GND: FB13.1, U6.17 (DGND); also elsewhere on the board
GNDA: C17.2, C18.2, C19.2, C20.2, C21.2, C22.2, C23.2, C24.2, C25.2, C55.2, C81.2, C83.2, C89.2, C90.2, C96.2, C97.2, C104.2, C105.2, C106.2, FB13.2, U6.2 (AGND), U6.3 (VREFN), U6.5 (AINCOM), U6.7 (AIN1), U6.9 (AIN3), U20.3 (A0), U20.4 (A1), U20.7 (GND); also elsewhere on the board
HEAT_LOAD_I: C55.1, TP17.1, U6.12 (AIN6); also elsewhere on the board
HEAT_LOAD_V: C89.1, TP18.1, U6.13 (AIN7); also elsewhere on the board
unnamed: C23.1, C90.1, FB12.1, L7.2
unnamed: C104.1, FB20.1, U20.8 (VDD)
unnamed: R31.2, R91.2, U20.1 (SCL)
unnamed: R34.2, R89.2, U20.2 (SDA)
unnamed: R105.1, U20.5 (INT)
unnamed: R110.1, U20.6 (CT)
PI_SCL: R91.1; also elsewhere on the board
PI_SDA: R89.1; also elsewhere on the board
TEMP_DIODE: C91.1, TP33.1, U6.10 (AIN4); also elsewhere on the board
TEMP_DIODE_RTN: C91.2, TP38.1, U6.11 (AIN5); also elsewhere on the board
~ADS1256_CS_0: R22.2, U6.20 (~CS); also elsewhere on the board
~ADS1256_RESET: R25.2, U6.15 (~RESET); also elsewhere on the board
~ADS1256_SYNC: U6.14 (~SYNC,_~PDWN)
~ADS1265_DRDY: R28.1, R118.2; also elsewhere on the board

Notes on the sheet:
ADC
Analog Inputs
PLACE C96,C97 RIGHT AT ADS1256 INPUT
PLACE C55,C89 RIGHT AT ADS1256 INPUT
PLACE NEAR ANALOG NETWORK

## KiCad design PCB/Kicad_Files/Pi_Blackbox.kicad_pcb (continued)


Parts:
C26: .1uF; C_1206_3216Metric_Pad1.42x1.75mm_HandSolder; MFG Part # 12065C104KAT4A
C27: .01uF; C_1206_3216Metric_Pad1.42x1.75mm_HandSolder
C30: 1uF; C_Rect_L7.2mm_W7.2mm_P5.00mm_FKS2_FKP2_MKS2_MKP2
C31, C32: 6,000 uF; Chemicon_LBK_Series
C33: .01uF; C_0603_1608Metric_Pad1.05x0.95mm_HandSolder
C34, C36, C93, C109, C132, C154: 10uF; C_1206_3216Metric_Pad1.42x1.75mm_HandSolder
C35: 1000pF; C_0402_1005Metric
C37: 10uF; C_0805_2012Metric_Pad1.15x1.40mm_HandSolder
C38: .1uF; C_0603_1608Metric_Pad1.05x0.95mm_HandSolder
C39, C108: 3.3uF; C_Rect_L7.2mm_W5.5mm_P5.00mm_FKS2_FKP2_MKS2_MKP2
C94: 1,000 uF; CP_Radial_D12.5mm_P5.00mm
C155: .1uF; C_1206_3216Metric_Pad1.42x1.75mm_HandSolder
C159: 1uF; C_1210_3225Metric_Pad1.42x2.65mm_HandSolder
D2: SMDJ18CA
D6: LED YEL; LED_0805_2012Metric_Pad1.15x1.40mm_HandSolder
D14: LED ORG; LED_0805_2012Metric_Pad1.15x1.40mm_HandSolder
F2: 2A; Fuse_2920
FB3: FB; R_0805_2012Metric_Pad1.15x1.40mm_HandSolder
FB14: FB; L_1210_3225Metric_Pad1.42x2.65mm_HandSolder
Fan1: Fan_ALT; Fan_30mmx30mmx10mm
HS1: BJT_Heatsink; Heat_Sink_Omni_220-18-50-2C
J3: IN; 2-1445057-2
J4: Connector; Pomona_Banana_73099_red; MPN 105-1102-001; Digi-Key_PN J576-ND
J9: Banana; Pomona_Banana_73099; MPN 105-1102-001; Digi-Key_PN J576-ND
L3: BNX022
L14: 47uH; L_Bourns_SRP1265A
Q8, Q9: TIP122; TO-220-3_Vertical
R35: 1kΩ; R_0402_1005Metric
R36, R37: 100 Ω; R_0603_1608Metric_Pad1.05x0.95mm_HandSolder
R38, R84: 500 mΩ; R_1206_3216Metric_Pad1.42x1.75mm_HandSolder
R39: 1K; R_0402_1005Metric
R40: 2.25KΩ; R_0805_2012Metric_Pad1.15x1.40mm_HandSolder
R41: 200Ω; R_0805_2012Metric_Pad1.15x1.40mm_HandSolder
R90: 220 kΩ; R_0603_1608Metric_Pad1.05x0.95mm_HandSolder
R92: 11.5 kΩ; C_0603_1608Metric_Pad1.05x0.95mm_HandSolder
R95: 2.2K; R_0402_1005Metric
TP21: COOLER-; TestPoint_Keystone_5000-5004_Miniature
TP30: COOLER_PWR; TestPoint_Keystone_5000-5004_Miniature
TP37: VIN+; TestPoint_Keystone_5000-5004_Miniature
TP49: VIN_RTN; TestPoint_Keystone_5000-5004_Miniature
U7: LT3065; MSOP-12-1EP_3x4mm_P0.65mm_EP1.65x2.85mm_ThermalVias
U10: AD8628; SOIC-8_3.9x4.9mm_P1.27mm
U14: LT5400; MSOP-8_3x3mm_P0.65mm

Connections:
+5V: FB3.1; also elsewhere on the board
+12V_REG: C34.1, C93.1, C94.1, D6.2 (A), Fan1.1 (+), R38.1, R84.1, R90.1; also elsewhere on the board
+18V_IN: C26.1, C30.1, C154.1, D14.2 (A), J3.1, L3.1 (B), TP37.1
+VIN_FILT: C31.1, C32.1, F2.2, L14.2; also elsewhere on the board
+VIN_FUSED: F2.1, Q8.2 (C), Q9.2 (C), R35.1, U7.1 (IN), U7.2 (IN)
/Power_Input/SHDN: R35.2, U7.3 (~SHDN)
/Power_Input/V_ADJ: R90.2, R92.1, U7.10 (ADJ)
/Power_Input/V_BIAS: C33.1, R36.2, R37.2, U7.11 (OUT), U7.12 (OUT)
COOLER_PWR: C159.1, J4.1, TP30.1, U14.1 (R1_in); also elsewhere on the board
COOL_PWR_GD: U7.4 (PWRGD)
COOL_PWR_V: C39.1, C108.1, C109.1, R40.1, R41.1; also elsewhere on the board
GND: C27.2, C31.2, C32.2, C33.2, C34.2, C35.2, C93.2, C94.2, C132.2, C155.2, C159.2, D2.2 (A2), FB14.2, Fan1.2 (-), J9.1, L3.4 (CG), R39.2, R92.2, TP21.1, U7.5 (I_MAX), U7.9 (GND), U7.13 (GND), U14.4 (R4_in); also elsewhere on the board
GNDA: C36.2, C38.2, C39.2, C108.2, C109.2, FB14.1, U10.4 (V-); also elsewhere on the board
unnamed: C35.1, U7.8 (BYP)
unnamed: C36.1, U10.3 (+), U14.5 (R4_out), U14.6 (R3_out)
unnamed: C37.1, R41.2, U10.6
unnamed: C37.2, R40.2, U10.2 (-)
unnamed: C38.1, FB3.2, U10.7 (V+)
unnamed: C27.1, C132.1, C155.1, D2.1 (A1), L3.2 (CB), L14.1
unnamed: D6.1 (K), R39.1
unnamed: D14.1 (K), R95.1
unnamed: Q8.1 (B), R36.1
unnamed: Q8.3 (E), R84.2
unnamed: Q9.1 (B), R37.1
unnamed: Q9.3 (E), R38.2
unnamed: U14.2 (R2_in), U14.3 (R3_in)
unnamed: U14.7 (R2_out), U14.8 (R1_out)
VIN_RTN: C26.2, C30.2, C154.2, J3.2, L3.3 (PSG), R95.2, TP49.1

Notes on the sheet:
12V Supply
COOLER RELAY
+5V supply to opamp limits any overvoltage to ADC
10KΩ x 4 match to .025%
low leakage MKS2 caps
TO ADS1256
AVERAGE VOLTAGE
POWER IN
20A rated
6.5A rated
FILM
FILM
POWER MEASURE
TO CCC


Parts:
C4, C207: DNI; C_0603_1608Metric_Pad1.05x0.95mm_HandSolder
C40, C42, C43, C45, C46, C48: .01uF; C_0402_1005Metric
C41, C52, C53, C54, C56, C57: .1uF; C_0603_1608Metric_Pad1.05x0.95mm_HandSolder
C44, C47, C198, C199, C200: .1uF; C_0402_1005Metric
C49, C50, C51, C113, C114: 1uF; C_0603_1608Metric_Pad1.05x0.95mm_HandSolder
FB4, FB5, FB6, FB15, FB16, FB17: FB; R_0805_2012Metric_Pad1.15x1.40mm_HandSolder
FB33, FB34, FB35: FB; R_0402_1005Metric
J5, J6, J7: THRMCPL; Thermocouple_Connect
R3, R4: DNI; R_0603_1608Metric_Pad1.05x0.95mm_HandSolder
R42, R43, R44, R45, R46, R47: 100R; R_0402_1005Metric
R51, R53, R55, R111, R112, R113, R131, R132, R134: 47R; R_0402_1005Metric
R58: 10K; R_0402_1005Metric
R60, R62, R114, R115, R116: 10k; R_0402_1005Metric
U11, U12, U13: MAX31856; TSSOP-14_4.4x5mm_P0.65mm
U32, U33, U34: SN74AHC1G125; SOT-23-5_HandSoldering

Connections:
+3.3V: FB4.2, FB5.2, FB6.2, FB15.1, FB16.1, FB17.1, FB33.1, FB34.1, FB35.1, R58.1, R60.1, R62.1, R114.1, R115.1, R116.1; also elsewhere on the board
/MAX31856/AVDD_1: C49.1, C52.1, FB4.1, U11.5 (AVDD)
/MAX31856/AVDD_2: C50.1, C53.1, FB5.1, U12.5 (AVDD)
/MAX31856/AVDD_3: C51.1, C54.1, FB6.1, U13.5 (AVDD)
/MAX31856/BIAS1: J6.1, R45.2, U12.2 (BIAS)
/MAX31856/DVDD_1: C113.1, FB15.2, U11.8 (DVDD)
/MAX31856/DVDD_2: C56.1, FB16.2, U12.8 (DVDD)
/MAX31856/DVDD_3: C57.1, C114.1, FB17.2, U13.8 (DVDD)
DAC_MOSI: R4.1, U11.12 (SDI), U12.12 (SDI), U13.12 (SDI); also elsewhere on the board
DAC_SCLK: R3.1, U11.10 (SCK), U12.10 (SCK), U13.10 (SCK); also elsewhere on the board
GNDA: C4.2, C40.1, C42.2, C43.1, C45.2, C46.1, C48.2, C49.2, C50.2, C51.2, C52.2, C53.2, C54.2, C56.2, C57.2, C113.2, C114.2, C198.2, C199.2, C200.2, C207.2, U11.1 (AGND), U11.14 (DGND), U12.1 (AGND), U12.14 (DGND), U13.1 (AGND), U13.14 (DGND), U32.3 (GND), U33.3 (GND), U34.3 (GND); also elsewhere on the board
MAX31856_CS_1: R58.2, U11.9 (~CS), U32.1 (~OE); also elsewhere on the board
MAX31856_CS_2: R62.2, U12.9 (~CS), U33.1 (~OE); also elsewhere on the board
MAX31856_CS_3: R60.2, U13.9 (~CS), U34.1 (~OE); also elsewhere on the board
MAX31856_DRDY_1: R111.1, R114.2; also elsewhere on the board
MAX31856_DRDY_2: R113.1, R116.2; also elsewhere on the board
MAX31856_DRDY_3: R112.1, R115.2; also elsewhere on the board
MAX31856_MISO: R131.1, R132.1, R134.1; also elsewhere on the board
MAX31856_MISO_1: R51.1, U32.2 (A)
MAX31856_MISO_2: R53.1, U33.2 (A)
MAX31856_MISO_3: R55.1, U34.2 (A)
unnamed: C4.1, R3.2
unnamed: C40.2, C41.1, R42.1, U11.4 (T+)
unnamed: C41.2, C42.1, R43.1, U11.3 (T-)
unnamed: C43.2, C44.1, R44.1, U12.4 (T+)
unnamed: C44.2, C45.1, R45.1, U12.3 (T-)
unnamed: C46.2, C47.1, R46.1, U13.4 (T+)
unnamed: C47.2, C48.1, R47.1, U13.3 (T-)
unnamed: C198.1, FB33.2, U32.5 (VCC)
unnamed: C199.1, FB34.2, U33.5 (VCC)
unnamed: C200.1, FB35.2, U34.5 (VCC)
unnamed: C207.1, R4.2
unnamed: J5.1, R43.2, U11.2 (BIAS)
unnamed: J5.2, R42.2
unnamed: J6.2, R44.2
unnamed: J7.1, R47.2, U13.2 (BIAS)
unnamed: J7.2, R46.2
unnamed: R51.2, U11.11 (SDO)
unnamed: R53.2, U12.11 (SDO)
unnamed: R55.2, U13.11 (SDO)
unnamed: R111.2, U11.7 (~DRDY)
unnamed: R112.2, U13.7 (~DRDY)
unnamed: R113.2, U12.7 (~DRDY)
unnamed: R131.2, U32.4 (Y)
unnamed: R132.2, U33.4 (Y)
unnamed: R134.2, U34.4 (Y)

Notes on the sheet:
MAX31856 is protected up to +-45V applied to input pins
THERMOCOUPLE MONITOR
OPTIONAL pads for terminating SPI bus if reflections become an issue
pads are at last chip in SPI chain, U12


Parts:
C58, C66, C69: 1uF; C_0805_2012Metric_Pad1.15x1.40mm_HandSolder
C59, C61, C64, C68, C117, C120: .1uF; C_0603_1608Metric_Pad1.05x0.95mm_HandSolder
C60, C63, C65: .01uF; C_0603_1608Metric_Pad1.05x0.95mm_HandSolder
C62, C67, C70, C116: 4.7uF; CP_EIA-3528-21_Kemet-B_Pad1.50x2.35mm_HandSolder
C213: 10uF; C_0805_2012Metric_Pad1.15x1.40mm_HandSolder
FB7, FB8, FB9, FB19: FB; R_0805_2012Metric_Pad1.15x1.40mm_HandSolder
FB18: FB; L_0805_2012Metric_Pad1.15x1.40mm_HandSolder
R63: 1K; R_0402_1005Metric
R64: 10k; R_0402_1005Metric
R67, R101: 50R; R_0402_1005Metric
R69: 10K; R_0603_1608Metric_Pad1.05x0.95mm_HandSolder
R70: 20R; R_0805_2012Metric_Pad1.15x1.40mm_HandSolder
R100: 10K; R_0402_1005Metric
TP23: 2V5_Filt; TestPoint_SMT_Keystone_5190
TP24: VDAC; TestPoint_SMT_Keystone_5190
TP25: DAC_AUX; TestPoint_Pad_D1.5mm
U15: LTC6655; LTC6655_LS8
U16: DAC8552; VSSOP-8_3.0x3.0mm_P0.65mm
U19: AD8628; SOIC-8_5.275x5.275mm_P1.27mm

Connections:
+2V5_VREF: FB7.2, FB19.1; also elsewhere on the board
+3.3V: R64.1; also elsewhere on the board
+5V: C63.1, C65.1, FB8.2, FB9.2, FB18.2; also elsewhere on the board
/DAC8552/AD8628_PS_FILT: C64.1, FB8.1, U19.7 (V+)
/DAC8552/DAC_PS: C66.1, C68.1, FB9.1, U16.1 (VDD)
/DAC8552/VDAC_AUX: R67.2, U16.3 (VOUTB)
/DAC8552/VDAC_OUT: R101.2, U16.4 (VOUTA)
/DAC8552/Vref_DAC: C58.1, C59.1, C60.2, FB7.1, U16.2 (VREF)
/DAC8552/Vref_In: C61.1, C62.1, FB18.1, R63.1, U15.2 (Vin)
/DAC8552/Vref_Shdn: R63.2, U15.1 (~SHDN)
/DAC8552/Vref_force: C67.1, C120.1, C213.1, R100.2, U15.6 (V_SENSE), U15.7 (V_FORCE)
/DAC8552/buff_comp: C69.1, R70.2, U19.6
/DAC8552/buff_in: C116.1, R100.1, U19.3 (+)
/DAC8552/buff_inv: C69.2, R69.2, U19.2 (-)
/DAC8552/vref_buff_out: C70.1, C117.1, FB19.2, R69.1, R70.1, TP23.1
DAC8552_CS: R64.2, U16.5 (~SYNC); also elsewhere on the board
DAC_AUX: R67.1, TP25.1
DAC_MOSI: U16.7 (DIN); also elsewhere on the board
DAC_SCLK: U16.6 (SCLK); also elsewhere on the board
GNDA: C58.2, C59.2, C60.1, C61.2, C62.2, C63.2, C64.2, C65.2, C66.2, C67.2, C68.2, C70.2, C116.2, C117.2, C120.2, C213.2, U15.3 (GND), U15.4 (GND), U15.5 (GND), U15.8 (GND), U16.8 (GND), U19.4 (V-); also elsewhere on the board
V_DAC: R101.1, TP24.1; also elsewhere on the board

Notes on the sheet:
Voltage Reference
DAC
Voltage Reference Decoupling
tantalum


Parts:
C1: 1000uF; CP_Radial_D12.5mm_P5.00mm; MFG Part # EEU-FR1V102B
C71, C87, C126, C131, C140, C148, C151, C152, C156: 47uF; T495X476K035ATE300
C72, C77: .1uF; C_0603_1608Metric_Pad1.05x0.95mm_HandSolder
C73, C88, C118, C119, C141, C143, C149: 1uF; C_0805_2012Metric_Pad1.15x1.40mm_HandSolder
C74, C76, C84, C92, C123, C124, C125, C127, C130, C134, C135, C138, C142, C144, C145, C146, C153: 10uF; C_1206_3216Metric_Pad1.42x1.75mm_HandSolder
C79: .1uF; C_0805_2012Metric_Pad1.15x1.40mm_HandSolder
C80: 12pF; C_0603_1608Metric_Pad1.05x0.95mm_HandSolder
C82: 3nF; C_0603_1608Metric_Pad1.05x0.95mm_HandSolder
C85: .1uF; R_0603_1608Metric_Pad1.05x0.95mm_HandSolder
C86: 680pF; C_0603_1608Metric_Pad1.05x0.95mm_HandSolder
C111, C122, C209, C210, C211: 10uF; C_0805_2012Metric_Pad1.15x1.40mm_HandSolder
C121: 1uF; C_0603_1608Metric_Pad1.05x0.95mm_HandSolder
C129, C133: .47uF; C_0402_1005Metric
C137: 560uF; CP_Radial_D10.0mm_P5.00mm
C147: 1000uF; CP_Radial_D12.5mm_P5.00mm
D7: MBRA340T3; MBRA430T
D8, D10, D11: LED GRN; LED_0805_2012Metric_Pad1.15x1.40mm_HandSolder
D9: LED YEL; LED_0805_2012Metric_Pad1.15x1.40mm_HandSolder
F3: 3A; Fuse_2920
L4: 22uH; L_Bourns_SRP1038
L5: 330uH 3.3A; Murata1433433C
L6, L8: 22uH; Sumida_CDRH105
L9: 10uH; 10uH_Wurth_74479887310A
L10: CM_choke; CM_Choke_EPCOS_B82720K
L11: 47uH; RLB9012-470KL
L12: 68uH; L_Wuerth_WE-PD
L13: 10uH; L_1210_3225Metric_Pad1.42x2.65mm_HandSolder
R71: 215K; R_0603_1608Metric_Pad1.05x0.95mm_HandSolder
R72: 1K; R_0402_1005Metric
R73: 36K; R_0603_1608Metric_Pad1.05x0.95mm_HandSolder
R74: 300R; R_0402_1005Metric
R75: 20k; R_0603_1608Metric_Pad1.05x0.95mm_HandSolder
R76: 2.2k; R_0603_1608Metric_Pad1.05x0.95mm_HandSolder
R77: 71.5K; R_0603_1608Metric_Pad1.05x0.95mm_HandSolder
R78: 11K; R_0603_1608Metric_Pad1.05x0.95mm_HandSolder
R79: 750R; R_0402_1005Metric
R80: 500R; R_0402_1005Metric
R81: 1k; R_0402_1005Metric
R88: 20R; R_1210_3225Metric_Pad1.42x2.65mm_HandSolder
R102: 200mOhm; R_1206_3216Metric_Pad1.42x1.75mm_HandSolder
R103: 1.5R; R_1206_3216Metric_Pad1.42x1.75mm_HandSolder
R104: 33.2k; R_0402_1005Metric
R107: 50.5k; R_0603_1608Metric_Pad1.05x0.95mm_HandSolder
R109: 47R; R_1210_3225Metric_Pad1.42x2.65mm_HandSolder
R127: 47R; R_0603_1608Metric_Pad1.05x0.95mm_HandSolder
R128: 5R; R_0805_2012Metric_Pad1.15x1.40mm_HandSolder
TP16: +6V_FILT; TestPoint_SMT_Keystone_5190
TP26, TP48: GNDA; TestPoint_SMT_Keystone_5190
TP27: +3V3; TestPoint_SMT_Keystone_5190
TP28: +6V; TestPoint_SMT_Keystone_5190
TP29: +5V_FILT; TestPoint_SMT_Keystone_5190
TP32: GND; TestPoint_SMT_Keystone_5190
TP35: PI_+5V; TestPoint_SMT_Keystone_5190
U18: TPS54360; Power_Pad_SO
U22, U30: LT3045; MSOP-12-1EP_3x4mm_P0.65mm_EP1.65x2.85mm_ThermalVias
U26: TPS7A7002; SOIC-8-1EP_3.9x4.9mm_P1.27mm_EP2.514x3.2mm_ThermalVias

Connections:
+3.3V: C85.1, C131.1, C134.1, C211.1, D8.2 (A), L13.2, TP27.1; also elsewhere on the board
+5V: C92.1, C111.1, C121.1, C122.1, C140.1, C153.1, C209.1, D11.2 (A), L11.2, TP29.1, U22.1 (IN), U22.2 (IN), U22.3 (IN), U22.4 (EN/UV), U22.7 (PG/FB); also elsewhere on the board
+6V: C1.1, C118.1, C119.1, C151.1, C152.1, D9.2 (A), L12.2, R102.2, R103.2, R109.1, TP16.1; also elsewhere on the board
+VIN_FILT: F3.2; also elsewhere on the board
/PI_Power_Supply/3.3V: C130.1, L13.1, U22.10 (OUTS), U22.11 (OUT), U22.12 (OUT)
/PI_Power_Supply/6V: C123.1, C138.1, C141.1, C143.1, C145.1, C147.1, L5.2, L6.1, R77.1, R88.2, TP28.1
/PI_Power_Supply/6V_CLK: R71.1, U18.4 (RT/CLK)
/PI_Power_Supply/6V_PS_COMP: C80.1, C82.1, U18.6 (COMP)
/PI_Power_Supply/6V_PS_FB: R77.2, R78.1, U18.5 (FB)
/PI_Power_Supply/+VIN_Fused: C71.1, F3.1, L4.1
/PI_Power_Supply/BUCK_VIN: C72.1, C73.1, C74.1, C156.1, L4.2, U18.2 (VIN)
/PI_Power_Supply/PI_PS: C84.1, C87.1, L8.1, R75.1, U26.6 (OUT)
/PI_Power_Supply/SW_OUT: C79.1, D7.1 (K), L5.1, R128.1, U18.8 (SW)
GND: C1.2, C71.2, C72.2, C73.2, C74.2, C76.2, C77.2, C80.2, C84.2, C86.1, C87.2, C118.2, C119.2, C123.2, C124.2, C125.2, C137.2, C138.2, C141.2, C142.2, C143.2, C144.2, C145.2, C146.2, C147.2, C148.2, C149.2, C151.2, C152.2, C156.2, D7.2 (A), L10.1, R71.2, R73.2, R76.2, R78.2, R79.2, R80.2, TP32.1, U18.7 (GND), U18.9 (GNDPAD), U26.8 (GND), U26.9 (GND_PAD); also elsewhere on the board
GNDA: C85.2, C88.2, C92.2, C111.2, C121.2, C122.2, C126.2, C127.2, C129.2, C130.2, C131.2, C133.2, C134.2, C135.2, C140.2, C153.2, C209.2, C210.2, C211.2, L10.2, R74.2, R81.2, R104.2, R107.2, TP26.1, TP48.1, U22.6 (ILIM), U22.9 (GND), U22.13 (GND), U30.6 (ILIM), U30.9 (GND), U30.13 (GND); also elsewhere on the board
unnamed: C79.2, R127.2
unnamed: C82.2, R73.1
unnamed: C86.2, R128.2
unnamed: C76.1, C77.1, C124.1, C125.1, L9.2, R72.2, U26.3 (IN)
unnamed: C88.1, C126.1, C127.1, C210.1, L10.3, U30.1 (IN), U30.2 (IN), U30.3 (IN), U30.4 (EN/UV), U30.7 (PG/FB)
unnamed: C129.1, R104.1, U22.8 (SET)
unnamed: C133.1, R107.1, U30.8 (SET)
unnamed: C135.1, L11.1, U30.10 (OUTS), U30.11 (OUT), U30.12 (OUT)
unnamed: C148.1, C149.1, L6.2, L12.1, R88.1, R109.2
unnamed: D8.1 (K), R74.1
unnamed: D9.1 (K), R79.1
unnamed: D10.1 (K), R80.1
unnamed: D11.1 (K), R81.1
unnamed: L9.1, R102.1
unnamed: L10.4, R103.1
unnamed: R72.1, U26.2 (EN)
unnamed: R75.2, R76.1, U26.7 (FB)
unnamed: R127.1, U18.1 (BOOT)
PI_+5V: C137.1, C142.1, C144.1, C146.1, D10.2 (A), L8.2, TP35.1; also elsewhere on the board

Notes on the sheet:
Vout = (R77/R78)(.8)+.8 = 6V
R23 sets switch frequency around 400khz
3V3 Supply
Buck to +6V
PTC Fuse
PI & ANALOG SUPPLIES
Vout = .5*(1 + R75/R76)
PI SUPPLY
tantalum
max dropout of .6V
.1% low TC
electrolytic
R127 in Series w/ bootstrap cap slows down slew rate of switching == less noise
LT3045 500mA max
5V Supply

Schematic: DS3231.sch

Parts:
BT1: Battery_Holder; BatteryHolder_Keystone_1058_2032; MFG Part # 1058
C160, C168: 0.1uF; C_0603_1608Metric_Pad1.05x0.95mm_HandSolder
FB26: ferrite; R_0603_1608Metric_Pad1.05x0.95mm_HandSolder
R121, R122: 22R; R_0402_1005Metric
R123, R124: 2k; R_0402_1005Metric
R125, R126: 10k; R_0402_1005Metric
U29: DS3231MZ+; SOIC-8_W3.9mm; MPN DS3231MZ/V+; Digi-Key_PN DS3231MZ/V+-ND

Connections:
+3.3V: FB26.2, R123.1, R124.1, R125.1, R126.1; also elsewhere on the board
GNDA: BT1.2 (-), C160.2, C168.2, U29.5 (GND); also elsewhere on the board
unnamed: C160.1, FB26.1, U29.2 (VCC)
unnamed: R121.1, R124.2, U29.7 (SDA)
unnamed: R122.1, R123.2, U29.8 (SCL)
unnamed: R125.2, U29.3 (~INT~/SQW)
unnamed: R126.2, U29.1 (32KHZ)
PI_SCL: R122.2; also elsewhere on the board
PI_SDA: R121.2; also elsewhere on the board
VBat: BT1.1 (+), C168.1, U29.6 (VBAT); also elsewhere on the board

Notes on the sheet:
REAL TIME CLOCK DS3231

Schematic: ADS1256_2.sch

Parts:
C181: 4.7uF; CP_EIA-3528-21_Kemet-B_Pad1.50x2.35mm_HandSolder
C182, C184, C208: 1uF; C_0603_1608Metric_Pad1.05x0.95mm_HandSolder
C183, C186, C188, C190, C191: .1uF; C_0603_1608Metric_Pad1.05x0.95mm_HandSolder
C185: .1uF; C_0805_2012Metric_Pad1.15x1.40mm_HandSolder
C187, C189: 1uF; R_0603_1608Metric_Pad1.05x0.95mm_HandSolder
C192, C193: 20pF; C_0603_1608Metric_Pad1.05x0.95mm_HandSolder
L16, L17: 10uH; MLZ2012N100LT000
R130, R138: 2k; R_0402_1005Metric
R133: 10k; R_0402_1005Metric
R136, R137: 47R; R_0402_1005Metric
U31: ADS1256; SSOP-28_5.3x10.2mm_P0.65mm
Y2: 7.68 Mhz; Crystal_SMD_TXC

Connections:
+2V5_VREF: C181.1, C182.1, C183.1, U31.4 (VREFP); also elsewhere on the board
+3.3V: C184.1, L16.1, R130.1, R133.1, R138.1; also elsewhere on the board
+5V: C186.1, L17.1; also elsewhere on the board
/ADS1256_2/ADS2_AVDD: C188.1, C189.1, C191.1, L17.2, U31.1 (AVDD)
/ADS1256_2/ADS2_DRDY2: R136.2, U31.21 (~DRDY)
/ADS1256_2/ADS2_DVDD: C187.1, C190.1, L16.2, U31.16 (DVDD)
/ADS1256_2/ADS2_MISO2: R137.2, U31.22 (DOUT)
ADS1256_MISO: R137.1; also elsewhere on the board
ADS1256_MOSI: U31.23 (DIN); also elsewhere on the board
ADS1256_SCLK: U31.24 (SCLK); also elsewhere on the board
COOL_PWR_I: C208.1, U31.6 (AIN0); also elsewhere on the board
CRYSTALA: C192.1, U31.19 (XTAL1/CLKIN), Y2.2
CRYSTALB: C193.1, U31.18 (XTAL2), Y2.1
GNDA: C181.2, C182.2, C183.2, C184.2, C186.2, C187.2, C188.2, C189.2, C190.2, C191.2, C192.2, C193.2, C208.2, U31.2 (AGND), U31.3 (VREFN), U31.5 (AINCOM), U31.7 (AIN1), U31.11 (AIN5), U31.13 (AIN7), U31.17 (DGND); also elsewhere on the board
HEAT_LOAD_I: U31.10 (AIN4); also elsewhere on the board
HEAT_LOAD_V: U31.12 (AIN6); also elsewhere on the board
TEMP_DIODE: C185.1, U31.8 (AIN2); also elsewhere on the board
TEMP_DIODE_RTN: C185.2, U31.9 (AIN3); also elsewhere on the board
~ADS1256_CS_1: R130.2, U31.20 (~CS); also elsewhere on the board
~ADS1256_RESET: R133.2, U31.15 (~RESET); also elsewhere on the board
~ADS1265_DRDY2: R136.1, R138.2; also elsewhere on the board

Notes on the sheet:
ADC
Analog Inputs

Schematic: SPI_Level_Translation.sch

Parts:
C201, C202, C203, C204, C205, C206: 0.1uF; C_0603_1608Metric_Pad1.05x0.95mm_HandSolder
R5, R6, R7, R147: 10k; R_0402_1005Metric
R135, R139, R140, R141, R142, R143, R144, R145, R146: 47R; R_0402_1005Metric
TP5: MISO_1; TestPoint_SMT_Keystone_5190
TP7: MOSI_1; TestPoint_SMT_Keystone_5190
TP8: SCLK_0; TestPoint_SMT_Keystone_5190
TP9: SCLK_1; TestPoint_SMT_Keystone_5190
TP10: MOSI_0; TestPoint_SMT_Keystone_5190
TP11: GND; TestPoint_SMT_Keystone_5190
TP12: MISO_0; TestPoint_SMT_Keystone_5190
TP50: PI_SCLK_0; TestPoint_SMT_Keystone_5190
U35, U36, U37: SN74HC125; SN74LVC125APWR; MPN SN74HC125A; Digi-Key_PN 296-1222-1-ND

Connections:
+3.3V: C201.1, C202.1, C203.1, C204.1, C205.1, C206.1, R5.1, R6.1, R7.1, R147.1, U35.14 (VCC), U36.14 (VCC), U37.14 (VCC); also elsewhere on the board
ADS1256_MISO: TP12.1, U35.12 (4A); also elsewhere on the board
ADS1256_MOSI: R142.1, TP10.1; also elsewhere on the board
ADS1256_SCLK: R141.1, TP8.1; also elsewhere on the board
DAC_MOSI: R144.1, R146.1; also elsewhere on the board
DAC_SCLK: R143.1, R145.1; also elsewhere on the board
GND: C201.2, C202.2, C203.2, C204.2, C205.2, C206.2, TP11.1, U35.7 (GND), U36.7 (GND), U37.7 (GND); also elsewhere on the board
MAX31856_MISO: U36.12 (4A), U37.12 (4A); also elsewhere on the board
unnamed: R135.1, U35.11 (4Y)
unnamed: R139.1, U36.11 (4Y)
unnamed: R140.1, TP5.1, U37.11 (4Y)
unnamed: R141.2, U35.3 (1Y)
unnamed: R142.2, U35.6 (2Y)
unnamed: R143.2, U36.3 (1Y)
unnamed: R144.2, U36.6 (2Y)
unnamed: R145.2, U37.3 (1Y)
unnamed: R146.2, U37.6 (2Y)
PI_MISO_0: R135.2, R139.2; also elsewhere on the board
PI_MISO_1: R140.2; also elsewhere on the board
PI_MOSI_0: U35.5 (2A), U36.5 (2A); also elsewhere on the board
PI_MOSI_1: TP7.1, U37.5 (2A); also elsewhere on the board
PI_SCLK_0: TP50.1, U35.2 (1A), U36.2 (1A); also elsewhere on the board
PI_SCLK_1: TP9.1, U37.2 (1A); also elsewhere on the board
~BUF_EN_0: R7.2, R147.2, U35.1 (~1OE), U35.4 (~2OE), U35.13 (~4OE); also elsewhere on the board
~BUF_EN_1: R5.2, U36.1 (~1OE), U36.4 (~2OE), U36.13 (~4OE); also elsewhere on the board
~BUF_EN_2: R6.2, U37.1 (~1OE), U37.4 (~2OE), U37.13 (~4OE); also elsewhere on the board

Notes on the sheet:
turn on when ads1 or ads2 CS goes low

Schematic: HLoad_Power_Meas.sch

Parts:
C13: 1.5uF; C_1210_3225Metric_Pad1.42x2.65mm_HandSolder
C157, C158: 0.1uF; C_0603_1608Metric_Pad1.05x0.95mm_HandSolder
C161: 1uF; C_0603_1608Metric_Pad1.05x0.95mm_HandSolder
C162: .1uF; C_0402_1005Metric
C163, C164, C167: 1uF; C_1210_3225Metric_Pad1.42x2.65mm_HandSolder
C165: 10uF; C_0805_2012Metric_Pad1.15x1.40mm_HandSolder
C166: .1uF; C_0603_1608Metric_Pad1.05x0.95mm_HandSolder
FB11, FB21, FB22, FB23: FB; R_0603_1608Metric_Pad1.05x0.95mm_HandSolder
R15: 1 kΩ; R_0402_1005Metric
R16: 1KΩ; R_0402_1005Metric
R17: 100 Ω; R_0402_1005Metric
R18: 1KΩ; R_0603_1608Metric_Pad1.05x0.95mm_HandSolder
R83: 100 Ω; R_0603_1608Metric_Pad1.05x0.95mm_HandSolder
TP34, TP36: test_pad; Probe_Test_Pad
U4: AD8278; SOIC-8_5.23x5.23mm_P1.27mm
U5: LT5400; MSOP-8_3x3mm_P0.65mm
U25: AD8417; SOIC-8_3.9x4.9mm_P1.27mm
U27, U28: AD8628; SOIC-8_3.9x4.9mm_P1.27mm
VLoad/4, VLoad/8: Jumper; SolderJumper-2_P1.3mm_Open_RoundedPad1.0x1.5mm

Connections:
+5V: FB21.1, FB22.1, FB23.1; also elsewhere on the board
/Heat_Load/HLoad: U25.8 (IN+); also elsewhere on the board
/Heat_Load/HLoad_Power_Meas/GUARD: C165.2, R18.2, U28.2 (-)
/Heat_Load/HLoad_Power_Meas/GUARD2: C161.2, R16.2, U27.2 (-)
/Heat_Load/HLoad_Power_Meas/I_Load: R15.2, U25.5 (OUT)
/Heat_Load/HLoad_Power_Meas/VLoad_div2: U4.5, U4.6, U5.1 (R1_in)
/Heat_Load/HLoad_Power_Meas/V_div4: TP34.1, U5.2 (R2_in), U5.3 (R3_in), VLoad/4.1
/Heat_Load/HLoad_Power_Meas/V_div8: TP36.1, U5.5 (R4_out), U5.6 (R3_out), VLoad/8.1
GND: C13.1, U4.2, U4.4 (V-); also elsewhere on the board
GNDA: C157.2, C158.2, C162.2, C163.2, C164.2, C166.2, C167.2, U4.1, U5.4 (R4_in), U25.2 (GND), U25.3 (REF2), U25.7 (REF1), U27.4 (V-), U28.4 (V-); also elsewhere on the board
HEAT_LOAD_I: C164.1, R16.1, R17.1; also elsewhere on the board
HEAT_LOAD_P: C13.2, U4.3, U25.1 (IN-); also elsewhere on the board
HEAT_LOAD_V: C167.1, R18.1, R83.1; also elsewhere on the board
LOAD_PS: FB11.1; also elsewhere on the board
unnamed: C157.1, FB11.2, U4.7 (V+)
unnamed: C158.1, FB21.2, U25.6 (VS)
unnamed: C161.1, R17.2, U27.6
unnamed: C162.1, FB22.2, U27.7 (V+)
unnamed: C163.1, U28.3 (+), VLoad/4.2, VLoad/8.2
unnamed: C165.1, R83.2, U28.6
unnamed: C166.1, FB23.2, U28.7 (V+)
unnamed: R15.1, U27.3 (+)
unnamed: U5.7 (R2_out), U5.8 (R1_out)

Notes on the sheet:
FILM
AD8278 Difference Amp in divide by 2 config
LT5400 divides by 4
AD8417 has a Gain of 60
FILM
Total Division Ratio is 8. Max Input Voltage is around 17 V, so output is scaled to 2.125 VMax, which is within ADC reference voltage of 2.5V

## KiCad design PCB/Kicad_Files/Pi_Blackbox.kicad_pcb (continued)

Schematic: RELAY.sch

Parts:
C28: 560uF; CP_Radial_D10.0mm_P5.00mm
C95: 47uF; T495X476K035ATE300
C102: .1uF; C_0603_1608Metric_Pad1.05x0.95mm_HandSolder
C103, C112: 1uF; C_0805_2012Metric_Pad1.15x1.40mm_HandSolder
C110: 1000uF; CP_Radial_D12.5mm_P5.00mm
D1, D3: 1N5819; SOD123
D4: 1N4148; SOD123
D12: 1N4148W; SOD123
D13: LED GRN; LED_0805_2012Metric_Pad1.15x1.40mm_HandSolder
D15: LED GREEN; LED_0805_2012Metric_Pad1.15x1.40mm_HandSolder
D17: LED RED; LED_0805_2012Metric_Pad1.15x1.40mm_HandSolder
JP1, JP2, JP3, JP4: Jumper_NO; SolderJumper-2_P1.3mm_Open_RoundedPad1.0x1.5mm
K1: DSP1-L2-DC5V; Panasonic_DSP1-L2-DC5V-F
Q3: BCM856DS; SOT-23-6_Handsoldering
Q4, Q7: MMBT2222A; SOT-23_Handsoldering
Q5: DMG6602
Q6: IRML6401; SOT-23_Handsoldering
R30, R32, R33: 50KΩ; R_0603_1608Metric_Pad1.05x0.95mm_HandSolder
R82: 750Ω; R_0603_1608Metric_Pad1.05x0.95mm_HandSolder
R85, R86: 500Ω; R_0402_1005Metric
R87, R98, R99: 1KΩ; R_0402_1005Metric
R96, R97: 47KΩ; R_0603_1608Metric_Pad1.05x0.95mm_HandSolder

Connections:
+5V: Q3.1 (E), Q6.3 (D); also elsewhere on the board
+5V_RELAY_PS: C110.1, D4.1 (K), D12.1 (K), D15.2 (A), K1.1, K1.2, Q3.4 (E), Q6.2 (S)
+12V_REG: D1.2 (A), K1.8, K1.9, R30.1, R32.1; also elsewhere on the board
/Power_Input/Power_Measure/RELAY_ON: C95.1, C102.1, C103.1, D13.2 (A), K1.5; also elsewhere on the board
/Power_Input/RELAY/COOLER_OFF: C112.1, D17.2 (A), K1.12
COIL_A: D4.2 (A), JP1.1, JP1.2, JP2.1, JP3.1, K1.16, Q4.3 (C)
COIL_B: D12.2 (A), JP2.2, JP3.2, JP4.1, JP4.2, K1.15, Q7.3 (C)
GND: C95.2, C102.2, C103.2, C112.2, R87.2, R99.2; also elsewhere on the board
GNDA: C28.2, C110.2, Q4.2 (E), Q5.5 (S), Q7.2 (E), R33.2, R96.2, R97.2, R98.2; also elsewhere on the board
unnamed: C28.1, D1.1 (K), Q5.2 (S), R30.2
unnamed: D3.1 (K), R82.2
unnamed: D3.2 (A), Q5.1 (G), Q5.4 (D), R33.1
unnamed: D13.1 (K), R87.1
unnamed: D15.1 (K), R98.1
unnamed: D17.1 (K), R99.1
unnamed: Q3.2 (B), Q3.5 (B), Q3.6 (C), R96.1
unnamed: Q3.3 (C), Q6.1 (G), R97.1
unnamed: Q4.1 (B), R82.1, R85.2
unnamed: Q5.3 (G), Q5.6 (D), R32.2
unnamed: Q7.1 (B), R86.1
RELAY_RESET: R86.2; also elsewhere on the board
RELAY_SET: R85.1; also elsewhere on the board

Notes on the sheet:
nominal coil current is 60 mA
RELAY_OFF
Automatically shuts off relay at power off
Supply for relay reset circuit
IDEAL DIODE (SUPPLY TO TURN OFF RELAY)
RELAY_ON
RELAY OFF INDICATOR
ON INDICATOR

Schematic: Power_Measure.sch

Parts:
C99, C115: .1uF; C_0603_1608Metric_Pad1.05x0.95mm_HandSolder
C100, C101, C107, C214: 10uF; C_1206_3216Metric_Pad1.42x1.75mm_HandSolder
C128, C174, C175, C176, C179: 1uF; C_0805_2012Metric_Pad1.15x1.40mm_HandSolder
C136: 47uF; T495X476K035ATE300
C139, C150: 100uF; C_1210_3225Metric_Pad1.42x2.65mm_HandSolder
C169: 3.3uF; C_Rect_L7.2mm_W5.5mm_P5.00mm_FKS2_FKP2_MKS2_MKP2
C170: 1uF; C_1210_3225Metric_Pad1.42x2.65mm_HandSolder
C171, C172, C173: 0.1uF; C_0603_1608Metric_Pad1.05x0.95mm_HandSolder
C177: 1000pF; C_0402_1005Metric
C180: 4.7uF; CP_EIA-3528-21_Kemet-B_Pad1.50x2.35mm_HandSolder
D5: LED_GRN; LED_0805_2012Metric_Pad1.15x1.40mm_HandSolder
FB24: FB; R_0805_2012Metric_Pad1.15x1.40mm_HandSolder
FB25, FB28: Ferrite; R_0805_2012Metric_Pad1.15x1.40mm_HandSolder
FB30: ferrite; R_0805_2012Metric_Pad1.15x1.40mm_HandSolder
FB31: FB; L_0603_1608Metric_Pad1.05x0.95mm_HandSolder
FB32: ferrite; L_1210_3225Metric_Pad1.42x2.65mm_HandSolder
R20: 500; R_0603_1608Metric_Pad1.05x0.95mm_HandSolder
R94: 56 mΩ; R_1206_3216Metric_Pad1.42x1.75mm_HandSolder
R106: 1M; R_0603_1608Metric_Pad1.05x0.95mm_HandSolder
R108: 4.7k; R_0402_1005Metric
R117: 1.87k; R_0603_1608Metric_Pad1.05x0.95mm_HandSolder
R119: 100R; R_0603_1608Metric_Pad1.05x0.95mm_HandSolder
R120: 1M; C_0603_1608Metric_Pad1.05x0.95mm_HandSolder
R129: .1R; R_0603_1608Metric_Pad1.05x0.95mm_HandSolder
SCALE1: 500R; Potentiometer_Bourns_3214W_Vertical
TP44: -5V; TestPoint_SMT_Keystone_5190
TP45: Current_SNS; TestPoint_SMT_Keystone_5190
TP46: AD637_RMS; TestPoint_SMT_Keystone_5190
TP47: RMS_FILT; TestPoint_SMT_Keystone_5190
U8: AD8417; SOIC-8_3.9x4.9mm_P1.27mm
U21: AD8628; SOIC-8_3.9x4.9mm_P1.27mm
U23: LT1054L; SOIC-8_5.275x5.275mm_P1.27mm
U24: AD637; SOIC-16W_7.5x10.3mm_P1.27mm
ZERO1: 50K POT; Potentiometer_Bourns_3214W_Vertical

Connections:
+5V: FB24.1, FB25.1, FB28.1, FB31.1, R108.2, ZERO1.1; also elsewhere on the board
-5V: C179.1, C180.1, C214.1, D5.1 (K), FB30.1, R129.1, TP44.1, ZERO1.3
/Power_Input/Power_Measure/RELAY_ON: R94.2, U8.8 (+); also elsewhere on the board
/Power_Input/Power_Measure/RMS_OUT: C169.1, C170.1, R117.2, SCALE1.1, SCALE1.2, TP46.1, U24.11 (RMS_OUT)
COOLER_PWR: R94.1, U8.1 (-); also elsewhere on the board
COOL_PWR_I: R119.1, U21.2 (-); also elsewhere on the board
Current_Sns_Amp: TP45.1, U8.5, U24.15 (VIN)
GNDA: C99.2, C100.2, C101.2, C107.2, C115.2, C128.2, C136.2, C150.2, C172.2, C173.2, C174.2, C175.2, C176.2, C177.2, C179.2, C180.2, C214.2, R20.2, R120.2, U8.2 (GND), U8.3 (REF2), U8.4 (GND), U8.7 (REF1), U21.4 (V-), U23.3 (GND), U24.1 (BUF_IN), U24.3 (COM); also elsewhere on the board
unnamed: C99.1, FB24.2, U8.6 (V+)
unnamed: C100.1, C101.1, C107.1, C176.1, R117.1, R120.1, TP47.1, U21.3 (+)
unnamed: C115.1, FB25.2, U21.7 (V+)
unnamed: C128.1, C136.1, FB31.2, U23.8 (V+)
unnamed: C139.1, U23.2 (CAP+)
unnamed: C139.2, U23.4 (CAP-)
unnamed: C150.1, FB32.1, U23.5 (-VOUT)
unnamed: C169.2, C170.2, U24.10 (C_AVG)
unnamed: C171.1, C172.1, C174.1, FB28.2, U24.13 (+VS)
unnamed: C171.2, C173.1, C175.1, FB30.2, U24.12 (-VS)
unnamed: C177.1, R106.2, ZERO1.2
unnamed: D5.2 (A), R20.1
unnamed: FB32.2, R129.2
unnamed: R106.1, U24.4 (OFFSET)
unnamed: R108.1, U24.5 (CS)
unnamed: R119.2, U21.6
unnamed: SCALE1.3, U24.6 (DENOM)

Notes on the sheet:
TO ADS1256
RMS CURRENT
AD8628 is low noise, low offset autozero amp to provide low impedance source to ADC
20-25 turn trim pot
FILM



Board: 6 copper layers, 175.1 x 125.6 mm, 569 parts (201 on the bottom side), 276 nets.

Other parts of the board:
C151#2: 4.7uF; C_1206_3216Metric_Pad1.42x1.75mm_HandSolder
C212: 10uF; C_1206_3216Metric_Pad1.42x1.75mm_HandSolder
JP5: MOSI_0; SolderJumper-2_P1.3mm_Open_RoundedPad1.0x1.5mm
JP6: MISO_0; SolderJumper-2_P1.3mm_Open_RoundedPad1.0x1.5mm
JP7: SCLK_0; SolderJumper-2_P1.3mm_Open_RoundedPad1.0x1.5mm
U38: Teensy4.0_min_pads; Teensy40_most_pads_small_holes

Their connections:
+6V: C151#2.1; also elsewhere on the board
ADS1256_MISO: JP6.1; also elsewhere on the board
ADS1256_MOSI: JP5.1; also elsewhere on the board
ADS1256_SCLK: JP7.1; also elsewhere on the board
DAC8552_CS: U38.17; also elsewhere on the board
DAC_MOSI: U38.26; also elsewhere on the board
DAC_SCLK: U38.27; also elsewhere on the board
GND: C151#2.2, C212.2, U38.GND; also elsewhere on the board
MAX31856_CS_1: U38.4; also elsewhere on the board
MAX31856_CS_2: U38.5; also elsewhere on the board
MAX31856_CS_3: U38.20; also elsewhere on the board
MAX31856_DRDY_1: U38.21; also elsewhere on the board
MAX31856_DRDY_2: U38.28; also elsewhere on the board
MAX31856_DRDY_3: U38.29; also elsewhere on the board
MAX31856_MISO: U38.1; also elsewhere on the board
unnamed: JP5.2, U38.11
unnamed: JP6.2, U38.12
unnamed: JP7.2, U38.13
PI_+5V: C212.1, U38.VIN; also elsewhere on the board
PI_SCL: U38.19; also elsewhere on the board
PI_SDA: U38.18; also elsewhere on the board
PI_UART_RX: U38.8; also elsewhere on the board
PI_UART_TX: U38.7; also elsewhere on the board
VBat: U38.VBAT; also elsewhere on the board
~ADS1256_CS_0: U38.10; also elsewhere on the board
~ADS1256_CS_1: U38.0; also elsewhere on the board
~ADS1256_RESET: U38.22; also elsewhere on the board
~ADS1265_DRDY: U38.6; also elsewhere on the board
~ADS1265_DRDY2: U38.9; also elsewhere on the board
~BUF_EN_0: U38.14; also elsewhere on the board
~BUF_EN_1: U38.15; also elsewhere on the board
~BUF_EN_2: U38.16; also elsewhere on the board

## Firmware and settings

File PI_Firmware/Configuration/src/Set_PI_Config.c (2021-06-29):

//  sudo raspi-config nonint do_change_locale en_US.UTF-8
//  sudo raspi-config nonint do_configure_keyboard us


/*
Verify Timezone:
/etc/timezone  contains: "America/Los_Angeles"
if not then:
echo "America/Los_Angeles" > /etc/timezone
dpkg-reconfigure -f noninteractive tzdata

Verify locale
cp /etc/locale.gen /etc/locale.gen.dist
sed -i -e "/^[^#]/s/^/#/" -e "/en_US.UTF-8/s/^#//" /etc/locale.gen

cp /var/cache/debconf/config.dat /var/cache/debconf/config.dat.dist
sed -i -e "/^Value: en_GB.UTF-8/s/en_GB/en_US/" \
       -e "/^ locales = en_GB.UTF-8/s/en_GB/en_US/" /var/cache/debconf/config.dat
locale-gen
update-locale LANG=en_US.UTF-8
///////////

// make copy of all files modified for easy revert to defaults




Something with SSH:
# update-rc.d ssh enable && invoke-rc.d ssh start
# rm -f -v /etc/ssh/ssh_host_*_key*
# /usr/bin/ssh-keygen -A -v
*/
// add firmware version number to config file
// read /dev/ folder and verify proper devices exist
//parse config file
// check and store:
/*
HOSTNAME
eth0_IP
network ADDRESS
subnet
hub ip#
update-rc.d ssh enable && invoke-rc.d ssh start
# dd if=/dev/hwrng of=/dev/urandom count=1 bs=4096
# rm -f -v /etc/ssh/ssh_host_*_key*
# /usr/bin/ssh-keygen -A -v
PCB revision level
usb folder location
log file suffix
hub log store
profile folder locations
environment variables
    hostname
    socket
    hub ip
    cal file location
    firmware version
*/

#include <stdio.h>
#include <stdlib.h>
#include <string.h>
#include <stdbool.h>
#include <wchar.h>
#include <locale.h>
#include <ctype.h>
#include <unistd.h>
#include <dirent.h>
#include "Aliases.h"
#include "colors.h"
#include "network.h"


#include <fcntl.h>
#include <errno.h>
#include <sys/types.h>


//#define NEW_USERNAME                  "sapien"
//#define NEW_PASSWORD                  "blackberry"

#define DEFAULT_PASSWORD              "raspberry"
#define DEFAULT_USERNAME              "pi"

#define BACKUP_FILE_SUFFIX            ".pi_original"

#define SHELL_CMD_GET_HOSTNAME        "raspi-config nonint get_hostname"
#define SHELL_CMD_SET_HOSTNAME        "sudo raspi-config nonint do_hostname "

#define SHELL_CMD_GET_SSH             "sudo raspi-config nonint get_ssh"    // If SSH is set this command returns 0
#define SHELL_CMD_SET_SSH             "sudo raspi-config nonint do_ssh "    // Add argument of 0 to enable SSH

#define POPEN_READ                   "re"  // "r" opens for reading, "e" sets close on exec flag ("FD_CLOEXEC")
#define POPEN_WRITE                   "w"  // "r" opens for reading, "e" sets close on exec flag ("FD_CLOEXEC")

#define DEGREE_SYMBOL                 "°"
#define CHECKMARK_CHARACTER           "\033[01;32m\xE2\x9C\x94\x1b[0m"
#define CROSS_CHARACTER               "\033[01;31m\xE2\x9D\x8C\x1b[0m"

#define SHELL_CMD_LIST_BOOT_FILES     "sudo /bin/ls /boot 2>&1"
#define SHELL_CMD_CAT_CONFIG_FILE     "sudo /bin/cat /boot/config.txt 2>&1"
#define SHELL_CMD_CLEAR               "clear"
#define SHELL_CMD_SET_KEYBOARD        "sed -i -e '/XKBLAYOUT=/s/[a-z][a-z]/us/' /etc/default/keyboard"
#define SHELL_CMD_RESTART_KBD_SERIVCE "sudo service keyboard-setup restart"
#define FILE_PI_HARDWARE_CONFIG       "/boot/config.txt"
#define FILE_BOOTLOG                  "~/firmware/bootlog.txt"




struct Disk_Usage{
	char kernel_location[30];
    char filesystem[20];
    char total_space[10];
    char used_space[10];
    char free_space[10];
    char mount_location[100];
    char percent_filled[20];
    int percent_disk_filled;
};

struct Disk_Usage uSD_Card;                      // root filesystem stored on micro SD card
struct Disk_Usage Flash_Drive;

#define ENV_VAR_USER      "USER"
#define ENV_VAR_HOME      "HOME"
#define ENV_VAR_HOSTNAME  "(hostname)"

//----------------------------------------------
// PRIMARY FUNCTION DECLARATIONS

void Add_User(char* NEW_USERNAME);
void Backup_File(char* filepath);
void Create_Aliases_File();
char** Exec_Shell_Command(char* command);
void Expand_FileSystem();
void Enable_Autologin_For_User(char* USERNAME);
void Free_String_Array_Memory(char** string_array);
char* Get_Environment_Variable_Value(char* env_variable);
void  Get_Environment_Variables();
char* Get_Keyboard_Layout();
char* Get_Hostname();
void Get_Disk_Usage();
double Get_CPU_Temp();
char** Install_Software_Packages(char* software_list_filepath);
char** List_Users();
void Print_Users();
void Print_String_Array(char** string_array);
void Reboot_PI();
void Remove_User(char* USERNAME);
void Set_Hostname(char* hostname);
bool Verify_Boot_File_Config();
bool Set_Boot_File_Config();
bool Verify_SSH_Enabled();
void Set_SSH_Enabled();
void Set_US_Keyboard_Layout();
char* Shell_List_Files(char* filepath);
char* Shell_List_Folders(char* filepath);
char* Shell_List_Hidden_Folders(char* path);
void Set_Network_Configuration(char* eth0_IP);
void Set_User_Password(char* USERNAME, char* NEW_PASSWORD);
void Set_Wallpaper(char* wallpaper_filepath);


//-----------------------------------------------------
//  HELPER FUNCTIONS

void Backup_System_Files();
void Echo_Env_Variable(char* variable, char* value);
void Enable_Sudo_No_Password_For_User(char* USERNAME);
void Enable_Desktop_Autologin(char* USERNAME);
void Enable_Console_Autologin(char* USERNAME);
void Erase_String_Contents(char* string);
void ExtractUserName(char* long_user_string);
void Get_Desktop_Autologin_File_Entry(char* get_line);
void Get_Desktop_Autologin_User(char* get_user);
void Get_Console_Autologin_User(char* get_user);
void Get_Console_Autologin_File_Entry(char* get_line);
char* Get_Substring(char* full_string, int start_index, int end_index);
char* Get_File_Suffix(char* filepath);
void Parse_Disk_Use(char* console_line, struct Disk_Usage* device);
char* Parse_KBD_Country_Code(char* read_line);
double parseDouble(char* integer_string);
int parseInt(char* integer_string);
char** Parse_Package_List(char*  software_list_filepath );
char** parseUsers(char** long_user_list, int uid_min, int uid_max);
void Print_Aliases();
bool Search_String_in_File(char *filename, char *match_string);
bool String_Equals_String(char* target_string, char* input_string);
bool String_Contains(char* base_string, char* match_string);
bool String_List_Contains(char** string_list, char* string_to_match);
void Trim_Trailing_WhiteSpace(char * str);
void Trim_Leading_WhiteSpace(char* str);
bool Verify_File_Exists(char* filepath);



//--------------------------------------------------------------
//  NEED TO DO
char* Get_TimeZone();
void Set_TimeZone(char* timezone);
bool Set_Locale();
bool Set_eth0_IP_Address(char* ip);
void Parse_Config_File();

///////////-----------------------------------------------------


char* USER;
char* HOME_FOLDER;
char* HOSTNAME;

int main( int argc, char *argv[] )
{

  FILE *file_pointer;
  char path[1035];
  bool boot_config = false;
  bool SSH_enabled = false;

  printf("\n");


	Install_Software_Packages("./package.install");
  //Exec_Shell_Command(SHELL_CMD_LIST_BOOT_FILES);
  //Exec_Shell_Command(SHELL_CMD_CAT_CONFIG_FILE);
  //Set_Hostname("PI-BB38");

  //Shell_List_Files(HOME_FOLDER);
  //Shell_List_Folders(HOME_FOLDER);
  //Shell_List_Hidden_Folders(HOME_FOLDER);
	// Get_Environment_Variables();
  Create_Aliases_File();
  printf(COLOR_BOLD_YELLOW "\nHARDWARE CONFIG " COLOR_RESET "\n\tChecking " COLOR_CYAN "/boot/config.txt " COLOR_RESET "for correct hardware overlays...\n" COLOR_RESET);
  boot_config = Verify_Boot_File_Config();
  if(boot_config)
  {
    printf("\n\t/boot/config.txt check:\t PASS ");
    printf(CHECKMARK_CHARACTER);
    printf("\n\n");
  }
  else
  {
    printf("/boot/config.txt check:\t FAIL");
    boot_config = Set_Boot_File_Config();
    printf(CROSS_CHARACTER);
  }

  SSH_enabled = Verify_SSH_Enabled();
  printf("\tSSH enabled: ");
  if(SSH_enabled)
  {
    printf("PASS \t");
    printf(CHECKMARK_CHARACTER);
    printf("\n\n");
  }
  else printf(CROSS_CHARACTER);

  printf("\tKeyboard Layout  \n");
  char* keyboard_layout = Get_Keyboard_Layout();
  printf("\t\tlayout:  " COLOR_LIGHT_MAGENTA "%s\t" COLOR_RESET, keyboard_layout);
  free(keyboard_layout);

  bool keyboard_layout_is_us = String_Equals_String(keyboard_layout, "us");
  if(keyboard_layout_is_us)
  {
      printf(CHECKMARK_CHARACTER);
      printf("\n\n");
  }

  char* hostname = Get_Hostname();
  printf(COLOR_BOLD_YELLOW "HOSTNAME: \t " COLOR_RESET COLOR_LIGHT_GREEN "%s\n" COLOR_RESET, hostname);

  Remove_User("sapien");
  Add_User("sapien");
  Add_User("pi");
  Enable_Sudo_No_Password_For_User("pi");
  Enable_Autologin_For_User("pi");

  // Set_Wallpaper("/home/pi/images/glowpi.jpg");
  // enter following command if pcmanfm doesnt restart
  // pcmanfm --desktop --profile LXDE-pi
  Backup_System_Files();

  Set_Network_Configuration("192.168.123.4");
  Get_Disk_Usage();

  double CPU_temperature = Get_CPU_Temp();
  printf(COLOR_LIGHT_RED);
  printf("CPU_TEMP:\t%.1f%sC\n", CPU_temperature, DEGREE_SYMBOL);
  printf(COLOR_RESET);
  Expand_FileSystem();
  //Reboot_PI();

  return 0;
}



char** Install_Software_Packages(char* software_list_filepath)
{
    if( !Verify_File_Exists( software_list_filepath) )
    {
        printf("Package Install List cannot be found.\t" COLOR_CYAN "%s\n" COLOR_RESET, software_list_filepath );
				return 0;
    }

		char package_update_command[] = "sudo apt-get -y update";
		char package_upgrade_command[] = "sudo apt-get -y upgrade";

		char** shell_response = Exec_Shell_Command( package_update_command );
		Print_String_Array( shell_response );
		Free_String_Array_Memory( shell_response );

		shell_response = Exec_Shell_Command( package_upgrade_command );
		Print_String_Array( shell_response );
		Free_String_Array_Memory( shell_response );


		char** packageList = Parse_Package_List( software_list_filepath );


		int package_index = 0;
		printf("\n\n");
	  while( packageList[ package_index ] )
	  {
	      printf("\t%d.   %s\n", package_index+1, packageList[ package_index ] );
	      ++package_index;
	  }

		Free_String_Array_Memory( packageList);
//do sudo apt update
// sudo apt upgrade
// verofy internet connection
// read package.install
// parse into strings
// do sudo apt install for each string
// return report of pass and failed installs


}

char** Parse_Package_List(char*  software_list_filepath )
{
	int MAX_LINES = 200;
	int MAX_LINE_LENGTH = 100;
	char read_line[250];

	FILE* software_list_file = fopen("/home/pi/firmware/package.install", "r");                 //  The popen() function opens a process by creating a pipe, forking and invoking the shell.
	if (software_list_file == NULL)
	{
			printf("Error opening package list file!!\n" );
			exit(1);
	}

	int line_count = 0;
	char**  package_list = malloc(sizeof(char*) * MAX_LINES);        // allocate memory for pointer to strings
	while (fgets(read_line, sizeof(read_line), software_list_file) != NULL)     /* Read the output a line at a time - output it. */
	{
			Trim_Trailing_WhiteSpace(read_line);
			//printf("LINE:\t%s\n", read_line);
			package_list[line_count] = (char*)malloc(sizeof(char) * MAX_LINE_LENGTH); // allocate memory for the
			strcpy(package_list[line_count], read_line);
			++line_count;
	}
	package_list[line_count] = NULL;   // Add a marker for the last string in the array
	fclose( software_list_file );     // close file pointer to STDOUT
	return package_list;
}

void Set_Splash_Icon(char* splash_icon_filepath)
{

}


void Set_Launch_Bar_Icon(char* launch_icon_filepath)
{
//    /usr/share/icons/PiX/32x32/places/start_here.png


}


bool Create_SSH_Keys()
{
    // create directory .ssh

    // create key with identifier
    //ssh keygen -t rsa -C  "PIBB38"

    // send the contents of the public key to the server:
    //cat ~/.ssh/id_rsa.pub | ssh pi@10.198.23.52 'cat >> ~/.ssh/authorized_keys'
}




/*
|--------------------------------------------------------------------------
| Get_CPU_Temp
|--------------------------------------------------------------------------
|
| Query the linux kernel for the CPU temperature. Returns a double of the
| temperature in Celsius. Not super precise but gives pretty good results.
| Succesive reads may return the same temperature. Seems to change in around
| 0.5C increments, despite showing finer resolution. Tested with cold spray
| and temperature reporting is accurate- returns values in vicinity of -20
| when hit with cold spray.
|
| @return    tempC    temperature of pi CPU in degrees Celsius
*/
double Get_CPU_Temp()
{
    char temperature_command[] = "/opt/vc/bin/vcgencmd measure_temp";
    char** shell_response = Exec_Shell_Command( temperature_command );
    double tempC = parseDouble( shell_response[0] );
    Free_String_Array_Memory( shell_response );

    return tempC;
}

void Remove_User(char* USERNAME)
{
    char delete_user_command[100];
    strcpy(delete_user_command, "sudo userdel ");                    // linux command to delete a user
    strcat(delete_user_command, USERNAME);                        // Append USERNAME to the command

    char** result = Exec_Shell_Command( delete_user_command );          // Execute the delete command
    printf("\n------------\n");
    printf(COLOR_BOLD_YELLOW "REMOVE USER\n" COLOR_RESET);
    printf("\tRemoving user:\t" COLOR_LIGHT_MAGENTA "%s.\n" COLOR_RESET, USERNAME);
    Print_String_Array( result );                                       // Print shell response
    printf("------------\n");
    Free_String_Array_Memory( result );                                 // Free memory from return string
}


/*
|--------------------------------------------------------------------------
| Expand_FileSystem
|--------------------------------------------------------------------------
|
| Fresh Rasbian install only allots max 8 GB disk space to the SD card, despite
| the SD card physical size. This function firsts queries whether the file
| system can be expanded. If it can be expanded, then the command is executed
| to expand the filesystem. File system changes will not take effect until
| reboot.
|
*/
void Expand_FileSystem()
{
    int SD_card_already_expanded;
    char** shell_response;
    char can_expand[100];
    char get_info_command[] = "sudo raspi-config nonint get_can_expand";
    char expand_FS_command[] = "sudo raspi-config nonint do_expand_rootfs";

    printf(COLOR_BOLD_YELLOW "\n\nEXPANDING FILESYSTEM...\n" COLOR_RESET);
    shell_response = Exec_Shell_Command( get_info_command );
    SD_card_already_expanded = parseInt( shell_response[0] );
    Free_String_Array_Memory( shell_response );

    if( SD_card_already_expanded == 0 )
    {
        printf("\tSD Card Already Expanded\n");
    }
    else
    {
        printf("\tExpanding SD Card ....");
        shell_response = Exec_Shell_Command( expand_FS_command );
        Free_String_Array_Memory( shell_response );
        printf("\tChanges will apply after reboot\n");
    }
    printf("\n\n");
}

/*
|--------------------------------------------------------------------------
| Backup_File
|--------------------------------------------------------------------------
|
| Creates a copy of the file parameter in the argument. The argument should be
| a fully referenced filepath if not the current directory. For instance:
|     /home/pi/Documents/save.txt
| First a check is made the file in the argument actually exists. Then it checks if
| a backup copy has already been made. If a backup copy already exists, it is not
| overwritten. If a backup does not exist, then a copy is made, appending the
| copy with ".pi_original". From the above example the backup would be:
|     /home/pi/Documents/save.txt.pi_original
|
|@param   filepath  fully specified filepath to target file, which is to be backup up
*/
void Backup_File(char* filepath)
{
    if( !Verify_File_Exists(filepath) ) // if file to backup doesnt exist, leave
        return;

    char* backup_file_suffix = ".pi_orig";

    char backup_file_path[100];
    strcpy(backup_file_path, filepath);
    strcat(backup_file_path, BACKUP_FILE_SUFFIX);           // a backup file ends in ".pi_original"
    backup_file_path[ strlen(backup_file_path) ] = '\0';

    if( Verify_File_Exists(backup_file_path) )  // If backup file exists already, dont overwrite it
    {
        printf(COLOR_YELLOW "\tBACKUP:\t" COLOR_RESET "file exists already  " COLOR_CYAN "%s\n" COLOR_RESET , backup_file_path);
        return;
    }

    char shell_command[100];
    sprintf(shell_command, "sudo cp %s %s", filepath, backup_file_path);
    char** response = Exec_Shell_Command( shell_command);
    Free_String_Array_Memory( response );
    printf("Backed up file:\t%s\n", backup_file_path);
}

/*
|--------------------------------------------------------------------------
| Backup_System_Files
|--------------------------------------------------------------------------
|
| Iteratively creates backups of all files listed.
|
*/
void Backup_System_Files()
{
    printf("---------------\n");
    printf( COLOR_BOLD_YELLOW "BACKUP SYSTEM FILES\n" COLOR_RESET);
    Backup_File("/etc/sudoers.d/010_pi-nopasswd");
    Backup_File("/etc/lightdm/lightdm.conf");
    Backup_File("/etc/systemd/system/autologin@.service");
    Backup_File("/etc/default/keyboard");
    Backup_File("/boot/config.txt");
    Backup_File("/etc/fstab");
    Backup_File("/etc/bash.bashrc");
    Backup_File("/etc/xdg/lxpanel/LXDE-pi/panels/panel");
    Backup_File("/etc/wpa_supplicant/wpa_supplicant.conf");
    Backup_File("/etc/dhcpcd.conf");
    Backup_File("/etc/network/interfaces");
    printf("---------------\n");
}


void Set_Wallpaper(char* wallpaper_filepath)
{
    // verify ends with .jpg or .png
    char* file_suffix = Get_File_Suffix(wallpaper_filepath);
    bool file_is_picture = false;
    if( String_Equals_String(".png", file_suffix))
        file_is_picture = true;
    else if(String_Equals_String(".jpg", file_suffix))
        file_is_picture = true;
    else if(String_Equals_String(".jpeg", file_suffix))
        file_is_picture = true;
    free(file_suffix);

    // If the argument is not a photo, dont set it as wallpaper
    if( !file_is_picture )
        return;
    char shell_command[100];
    char update_command[] = "sudo killall -9 pcmanfm";
    // /home/pi/.config/pcmanfm/LXDE-pi/desktop-items-0.conf
    // edit the field wallpaper=
    // killall -9 pcmanfm
    char* escape_slash = "\\/";

    strcpy(shell_command, "sed -i 's/^wallpaper=.*/wallpaper=");

    char sed_filepath[50];


    int sed_index = 0;
    for(int i=0; i<strlen(wallpaper_filepath); ++i)
    {
        if( wallpaper_filepath[i] == '/')
        {
            sed_filepath[sed_index] = '\\';
            ++sed_index;
            sed_filepath[sed_index] = '/';
            ++sed_index;
        }
        else
        {
            sed_filepath[sed_index] = wallpaper_filepath[i];
            ++sed_index;
        }
    }
    sed_filepath[sed_index] = '\0';

    strcat(shell_command, sed_filepath);        // append filepath to shell command
    strcat(shell_command, "/' /home/pi/.config/pcmanfm/LXDE-pi/desktop-items-0.conf");
    printf("command:\t%s\n", shell_command);

    Backup_File("/home/pi/.config/pcmanfm/LXDE-pi/desktop-items-0.conf");
    char** response_string;
    // verify wallpaper file exists in proper location:
    if( access( wallpaper_filepath, F_OK ) != -1 )
    {
        printf("\tWallpaper File Exists:  \t\t" COLOR_LIGHT_CYAN "%s\n" COLOR_RESET, wallpaper_filepath);        // file exists
        response_string = Exec_Shell_Command( shell_command );
        Free_String_Array_Memory( response_string );
        response_string = Exec_Shell_Command( update_command );
        Free_String_Array_Memory( response_string );
    }
    else
    {
        printf("file not present\n");
              return;
    }
}


void Reboot_PI()
{
  char reboot_command[100];
  strcpy( reboot_command, "sudo reboot" );

  char**  return_string_array = Exec_Shell_Command( reboot_command );
  Free_String_Array_Memory(return_string_array);
}
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

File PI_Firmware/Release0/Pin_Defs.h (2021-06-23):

#ifndef PIN_DEFINITIONS
#define PIN_DEFINITIONS

// Pin Numbering
/*
Rasperry Pi Physical Pin Numbering w/ bcm2835 library pin Numbering
            BCM2835           Raspberry Pi
Function     pin#             physical pin#
SDA1          2                   3       PI_SDA
SCL1          3                   5       PI_SCL
GPCLK0        4                   7       BUF_EN_2
GPCLK1        5                   29      MAX31856_DRDY1
GPCLK2        6                   31      SW_CTRL_100uA
SPI0_CE1_N    7                   26      MAX31856_CS3
SPI0_CE0_N    8                   24      MAX31856_CS2
SPI0_MISO     9                   21      ADS1256_MISO
SPI0_MOSI     10                  19      ADS1256 MOSI
SPI0_SCLK     11                  23      ADS1256_SCLK
PWM0          12                  32      RELAY_RESET
PWM1          13                  33      ADS1256_CS_1
TXD0          14                  8       CCC_UART_TX
RXD0          15                  10      CCC_UART_RX
SPI1_CE2      16                  36      MAX31856_DRDY2
SPI1_CE1      17                  11      ADS1256_DRDY
PCM_CLK       18                  12      ADS1256_RESET
SPI1_MISO     19                  35      MISO_SPI1
SPI1_MOSI     20                  38      MOSI_SPI1
SPI1_SCLK     21                  40      SCLK_SPI1
SD0_CLK       22                  15      ADS1256_CS_0
SD0_CMD       23                  16      DAC8552_CS
SD0_DAT0      24                  18      BUF_EN_1
SD0_DAT1      25                  22      MAX31856_CS1
SD0_DAT2      26                  37      MAX31856_DRDY3
SD0_DAT3      27                  13      BUF_EN_0
              01                  28      RELAY_SET
              00                  27      ADS1256_DRDY2
*/
#define BUS_SPEED_100KHZ  100000
#define BUS_SPEED_300KHZ  300000
#define BUS_SPEED_400KHZ  400000

#define DS3231_ADDRESS    0x68

#define ADS1256_DRDY_0    17        // physical pin 11
#define ADS1256_DRDY_1     0        // physical pin 27
#define ADS1256_RESET     18        // physical pin 12

#define ADS1256_CS_0      22        // Physical pin 15
#define ADS1256_CS_1      13        // physical pin 33

//#define	DAC8552_CS	    RPI_GPIO_P1_16	// Physical pin 16
#define	DAC8552_CS	      23	      // Physical pin 16

#define MAX31856_CS_1     25        // physical pin 25
#define MAX31856_CS_2     8         // physical pin 24
#define MAX31856_CS_3     7         // physical pin 26
#define MAX31856_DRDY_1   5         // physcial pin 29
#define MAX31856_DRDY_2   16        // physical pin 36
#define MAX31856_DRDY_3   26        // physical pin 37

#define BUFFER_EN_1       24
#define BUFFER_EN_2       4         // physical pin 7
#define BUFFER_EN_0       27        // physical pin 13

#define PI_MOSI_0         10        // physical pin 19
#define PI_MISO_0         9         // physical pin 21
#define PI_SCLK_0         11        // physical pin 23

#define PI_MOSI_1         20        // physical pin 38
#define PI_MISO_1         19        // physical pin 35
#define PI_SCLK_1         21        // physical pin 40

#define RELAY_RESET       12        // physical pin 32
#define RELAY_SET         1         // physical pin 28
#define SW_CTRL_100uA     6         // physical pin 31
#define PI_UART_TX        14        // physical pin 8
#define PI_UART_RX        15        // physical pin 10






typedef struct ADS1256
{
    int CS_pin;
    int DRDY_pin;
    int RESET_pin;
		int BUF_EN_pin;
} ADC;

ADC ADC0;
ADC ADC1;

int CURRENT_SOURCE_SELECT = 0;

bool RELAY_is_ON = false;
const int NUM_MEAS_SAMPLES = 3;







#endif

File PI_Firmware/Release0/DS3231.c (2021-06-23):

#include <bcm2835.h>
#include <stdio.h>
#include <unistd.h>
#include <time.h>
#include <stdlib.h>
#include <string.h>
#include <ctype.h>
#include <stdbool.h>



#define ADDR_SECONDS      0x00
#define ADDR_MINUTES      0x01
#define ADDR_HOURS        0x02
#define ADDR_DAY_OF_WEEK  0x03
#define ADDR_DAY_OF_MONTH 0x04
#define ADDR_MONTH        0x05
#define ADDR_YEAR         0x06

#define INDEX_START_ADDR        0x00
#define WRITE_INDEX_SECONDS       1
#define WRITE_INDEX_MINUTES       2
#define WRITE_INDEX_HOURS         3
#define WRITE_INDEX_DAY_OF_WEEK   4
#define WRITE_INDEX_DAY_OF_MONTH  5
#define WRITE_INDEX_MONTH         6
#define WRITE_INDEX_YEAR          7

#define READ_INDEX_SECONDS       0
#define READ_INDEX_MINUTES       1
#define READ_INDEX_HOURS         2
#define READ_INDEX_DAY_OF_WEEK   3
#define READ_INDEX_DAY_OF_MONTH  4
#define READ_INDEX_MONTH         5
#define READ_INDEX_YEAR          6


#define MASK_SECONDS      0x7F
#define MASK_MINUTES      0x7F
#define MASK_HOURS        0x3F
#define MASK_DAY_OF_WEEK  0x07
#define MASK_DAY_OF_MONTH 0x3F
#define MASK_MONTH        0x1F


#define DS3231_ADDRESS        0x68        ///  I2C address for DS3231
#define DS3231_CONTROL        0x0E        ///  Control register
#define DS3231_STATUS_REG     0x0F        ///  Status register

#define SECONDS_PER_DAY       86400       ///  60 * 60 * 24
#define SECONDS_1970_TO_2000  946684800   ///  Unixtime for 2000-01-01 00:00:00, useful for initialization

/**
  Number of days in each month, from January to November. December is not
  needed. Omitting it avoids an incompatibility with Paul Stoffregen's Time
  library. C.f. https://github.com/adafruit/RTClib/issues/114
//*/
const uint8_t daysInMonth [] = { 31,28,31,30,31,30,31,31,30,31,30 };

/**************************************************************************/
/*!
    @brief  Given a number of days, hours, minutes, and seconds, return the total seconds
    @param days Days
    @param h Hours
    @param m Minutes
    @param s Seconds
    @return Number of seconds total
*/
/**************************************************************************/
static long time2long(uint16_t days, uint8_t h, uint8_t m, uint8_t s) {
    return ((days * 24L + h) * 60 + m) * 60 + s;
}


/**************************************************************************/
/*!
    @brief  Convert a binary coded decimal to binary. RTC stores time/date values as BCD.
    @param val BCD value
    @return Binary value
*/
/**************************************************************************/
static uint8_t BCD_To_Decimal (uint8_t bcd)
{
  //  return bcd - 6 * (bcd >> 4);    // gets day of week right
    // return (uint8_t)(10 * ((bcd & 0xF0) >> 4) + (bcd & 0x0F));
    uint8_t msb = bcd;
    return ((msb >> 4) * 10) + (bcd & 0x0F);
}

/**************************************************************************/
/*!
    @brief  Convert a binary value to BCD format for the RTC registers
    @param val Binary value
    @return BCD value
*/
/**************************************************************************/
static uint8_t Decimal_To_BCD(uint8_t dec)
{
//    return dec + 6 * (dec / 10);    // gets day of week right
    //    return (uint8_t)(((dec / 10) << 4) | (dec % 10));
    uint8_t msb = dec;
            return ((msb / 10) << 4) + (dec % 10);
}


struct time_stamp
{
    int month;
    int day;
    int year;
    int hour;
    int minute;
    int second;
};

typedef struct time_stamp Time_Stamp;
Time_Stamp Time_Now;

uint8_t TIME_bytes[8];
char *str[]  ={"SUN", "MON", "TUES", "WED", "THUR", "FRI", "SAT"};

struct tm *time_info;
time_t raw_time_now;
struct timespec current_time;

void DS3231_Set_From_Linux_Time()
{
    //char addr_byte[1] = { 0x00 };
    char timestamp_string[300];
    timestamp_string[0] = '\0';

    time( &raw_time_now);
    time_info = localtime(&raw_time_now);


    printf("\t --SET DS3231 FROM LINUX TIME--\n");
    strftime (timestamp_string,50,"%H:%M:%S  %m/%d/%Y ",time_info); // convert time info to string
    //printf("formatted string from get_time: \t%s\n", timestamp_string);
    for(int i=0; i<strlen(timestamp_string); i++)
    {
          if(timestamp_string[i] == '/' || timestamp_string[i] == ':') // remove slashes from date and replace with dashes so compatible with filename
          {	timestamp_string[i] = ' ';	}
    }

    // parse the string into individual integer values
    sscanf(timestamp_string, "%d %d %d  %d %d %d ", &Time_Now.hour, &Time_Now.minute, &Time_Now.second, &Time_Now.month, &Time_Now.day, &Time_Now.year );

    Time_Now.year -= 2000;
    //printf("SET before BCD %d:%d:%d %d/%d/%d\t\t(2 digit year)\n", Time_Now.hour, Time_Now.minute, Time_Now.second, Time_Now.month,
    //        Time_Now.day, Time_Now.year);

    TIME_bytes[INDEX_START_ADDR] = 0x00;
    TIME_bytes[WRITE_INDEX_SECONDS] = Decimal_To_BCD( (uint8_t) Time_Now.second & MASK_SECONDS ) ; //sec
    TIME_bytes[WRITE_INDEX_MINUTES] = Decimal_To_BCD( (uint8_t) Time_Now.minute & MASK_MINUTES );
    TIME_bytes[WRITE_INDEX_HOURS] = Decimal_To_BCD( (uint8_t) Time_Now.hour & MASK_HOURS );
    TIME_bytes[WRITE_INDEX_DAY_OF_WEEK] = 0;
    TIME_bytes[WRITE_INDEX_DAY_OF_MONTH] = Decimal_To_BCD((uint8_t) Time_Now.day & MASK_DAY_OF_MONTH );
    TIME_bytes[WRITE_INDEX_MONTH] = Decimal_To_BCD( (uint8_t) Time_Now.month & MASK_MONTH );
    //TIME_bytes[WRITE_INDEX_YEAR] = Decimal_To_BCD( (uint8_t) Time_Now.year -2000);
    TIME_bytes[WRITE_INDEX_YEAR] = (uint8_t)( Time_Now.year -2000 );


    //printf("SET After BCD: %d:%d:%d %d/%d/%d\t\t(two digit year)\n", TIME_bytes[WRITE_INDEX_HOURS], TIME_bytes[WRITE_INDEX_MINUTES], TIME_bytes[WRITE_INDEX_SECONDS], TIME_bytes[WRITE_INDEX_MONTH],
    //        TIME_bytes[WRITE_INDEX_DAY_OF_MONTH], TIME_bytes[WRITE_INDEX_YEAR]);
    //printf("\t --------------\n");
    bcm2835_i2c_write(TIME_bytes, 8);
}

void Read_Linux_Time()
{
    char line[256];
    //char addr_byte[1] = { 0x00 };
    int hour, minute, second, month, day, two_digit_year, four_digit_year;

    system("date +\"%H:%M:%S %D\" > /tmp/datefile");    // sends date command to terminal and redirects output to file @ /tmp/datefile
    FILE* file_pointer = fopen("/tmp/datefile", "r");   // opens the file for reading

    if(fgets(line, 256, file_pointer) != NULL)
    {
          for(int i=0; i<strlen(line); i++)
          {
              if(line[i] == '/' || line[i] == ':') // remove slashes from date and replace with dashes so compatible with filenames
              {	line[i] = ' ';	}
          }
          sscanf(line, "%d %d %d %d %d %d ", &hour, &minute, &second, &month, &day, &two_digit_year); // read the file into the variables
    }

    four_digit_year = two_digit_year + 2000;
    fclose(file_pointer);
    system("rm /tmp/datefile");  // delete the temporary file

    printf("\t --------------\n");
    printf("LINUX READ TIME \t %d:%d:%d %d/%d/%d\n", hour, minute, second, month, day, four_digit_year);
}
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

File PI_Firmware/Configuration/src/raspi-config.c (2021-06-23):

/* Command strings */
#define GET_CAN_EXPAND  "sudo raspi-config nonint get_can_expand"
#define EXPAND_FS       "sudo raspi-config nonint do_expand_rootfs"
#define GET_HOSTNAME    "sudo raspi-config nonint get_hostname"
#define SET_HOSTNAME    "sudo raspi-config nonint do_hostname %s"
#define GET_BOOT_CLI    "sudo raspi-config nonint get_boot_cli"
#define GET_AUTOLOGIN   "sudo raspi-config nonint get_autologin"
#define SET_BOOT_CLI    "sudo raspi-config nonint do_boot_behaviour B1"
#define SET_BOOT_CLIA   "sudo raspi-config nonint do_boot_behaviour B2"
#define SET_BOOT_GUI    "sudo raspi-config nonint do_boot_behaviour B3"
#define SET_BOOT_GUIA   "sudo raspi-config nonint do_boot_behaviour B4"
#define GET_BOOT_WAIT   "sudo raspi-config nonint get_boot_wait"
#define SET_BOOT_WAIT   "sudo raspi-config nonint do_boot_wait %d"
#define GET_SPLASH      "sudo raspi-config nonint get_boot_splash"
#define SET_SPLASH      "sudo raspi-config nonint do_boot_splash %d"
#define GET_OVERSCAN    "sudo raspi-config nonint get_overscan"
#define SET_OVERSCAN    "sudo raspi-config nonint do_overscan %d"
#define GET_CAMERA      "sudo raspi-config nonint get_camera"
#define SET_CAMERA      "sudo raspi-config nonint do_camera %d"
#define GET_SSH         "sudo raspi-config nonint get_ssh"
#define SET_SSH         "sudo raspi-config nonint do_ssh %d"
#define GET_VNC         "sudo raspi-config nonint get_vnc"
#define SET_VNC         "sudo raspi-config nonint do_vnc %d"
#define GET_SPI         "sudo raspi-config nonint get_spi"
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

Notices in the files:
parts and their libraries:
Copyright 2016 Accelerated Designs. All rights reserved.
